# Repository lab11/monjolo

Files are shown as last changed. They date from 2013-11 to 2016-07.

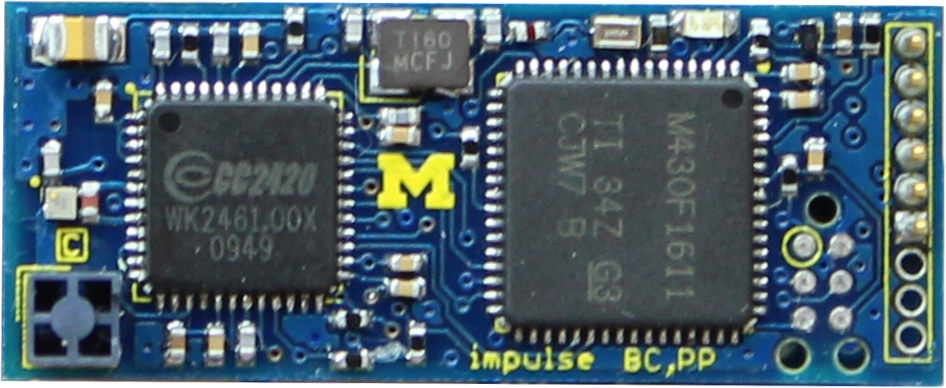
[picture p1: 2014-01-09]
hardware/impulse/rev_c/impulse.jpg

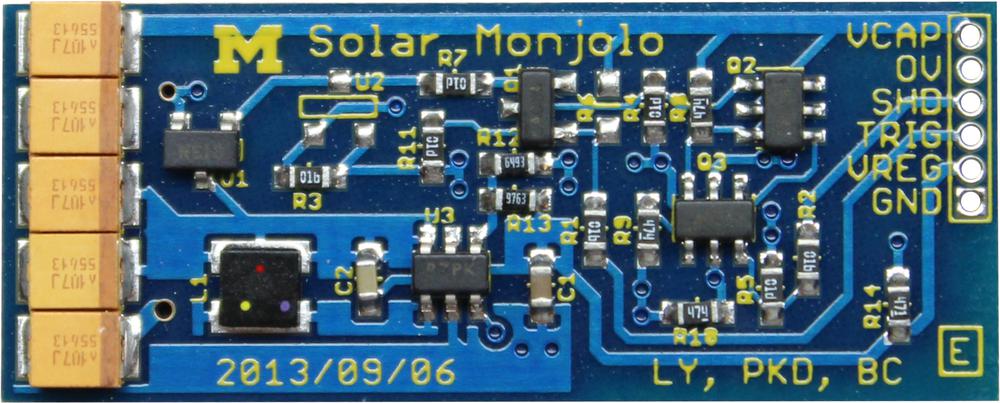
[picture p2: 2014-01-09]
hardware/gecko_power_supply/rev_e/monjolo.jpg

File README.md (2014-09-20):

Monjolo
=======

Monjolo sensors are designed to meter energy consumers, such as plug loads,
lighting, water heaters, etc. Monjolo exploits an interesting fact to accomplish
this: energy consuming loads (e.g. overhead lighting) often produce side
channels of energy that can be harvested (e.g. light with a solar panel).
Monjolo nodes use an energy-harvesting power supply to scavenge energy from
these side channels to power themselves. The sensors then infer information
about the original load based on the rate it is able to harvest. Monjolo nodes
follow a simple principle: the faster the rate of harvesting the greater the
amount of energy consumed by the monitored load.

The operation of a Monjolo node proceeds as follows: the harvester charges
a capacitor to some threshold. Once the threshold is met, the processing
core of the node activates and transmits a packet. The capacitor is then
drained to a lower threshold where the processing core is disabled and
the recharging process recommences. A central receiver collects all of these
packets and calculates the activation rate of the Monjolo node. This rate
is then used to meter the energy consumer.

This differs from traditional sensing because there is no explicit sensor
on the device. The sensing apparatus is entirely composed of the
energy-harvester and the packet receiver. All information is contained in
the rate of activations of the Monjolo node.

We have developed Three instantiations of this metering design. First is
Coilcube, a power meter for AC loads. Second is a light sensor for metering
lighting. And third is a thermoelectric design for metering temperature
differential.

Coilcube
--------

cc_case (https://raw.github.com/lab11/monjolo/master/media/coilcube_case.jpg)
cc_open (https://raw.github.com/lab11/monjolo/master/media/coilcube_open.jpg)

Coilcube is an AC power meter that comes in two forms: plug-load and split-core.

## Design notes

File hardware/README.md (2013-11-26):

Hardware (PCBs)
===============

This folder contains hardware for the various Monjolo nodes.

| Board | Folder | Description |
|---|---|---|
| Coilcube Power Supply | cc_power_supply | An AC current transformer based energy-harvesting power supply. |
| Coilcube | coilcube | Plug load AC meter. Contains processing core. |
| Gecko Power Supply | gecko_power_supply | Energy-harvesting power supply for solar cell. |
| Impulse | impulse | Processing core. Contains, uC, radio, antenna, FRAM, and timing capacitor. |
| sEHnsor | sEHnsor | Processing core like Impulse based on the CC2538. |

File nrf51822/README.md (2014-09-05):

Monjolo + nRF51822
==================

This folder contains code to run on the nRF51822 based Monjolo platform.

Setup
=====

1. Get the git repo that has the Makefiles in it.

        git clone https://github.com/hlnd/nrf51-pure-gcc-setup.git

1. Make sure you have the [arm-none-eabi-gcc](https://launchpad.net/gcc-arm-embedded)
toolchain. You just need the binaries for your platform.

1. Get the nRF51822 SDK and S110 soft device from the
[downloads page](https://www.nordicsemi.com/eng/Products/Bluetooth-Smart-Bluetooth-low-energy/nRF51822?resource=20339).
You want the "nRF51 SDK Zip File" and the "S110 nRF51822 SoftDevice (Production ready)".
You do need to buy a nRF51822 evm kit to get access to these, because companies
are the worst.

1. Make sure the SDK path is set correctly in the application Makefile.

1. Get the [Segger flashing tools](http://www.segger.com/jlink-software.html).
On Linux you want the "J-Link software & documentation pack for Linux".

Install an App
==============

1. Just once you need to load the soft device onto the nRF51822.

        make flash-softdevice SOFTDEVICE=/path/to/softdevice/s110_nrf51822_X.X.X_softdevice.hex

2. Now compile and load the application code.

        cd apps/monjolo
        make flash

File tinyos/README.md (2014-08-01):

TinyOS
======

Most of the code for Monjolo sensors is written in TinyOS. There are a
few steps you must complete to be able to compile the TinyOS apps.

Step 1: Get TinyOS
------------------

This repo will only compile against the latest version of tinyos. For now,
you need to compile the tools as well.

    git clone https://github.com/lab11/tinyos-main.git
    cd tinyos-main
    cd tools
    ./Bootstrap
    ./configure
    make
    sudo make install

You also need this repository, of course:

    git clone https://github.com/lab11/monjolo.git

Now you need to tell the TinyOS build tools where to find the Monjolo specific
TinyOS code. Add the following to `bash.rc`:

    export TINYOS_ROOT_DIR_ADDITIONAL=~/git/monjolo/tinyos:$TINYOS_ROOT_DIR_ADDITIONAL
    export TINYOS_ROOT_DIR=~/git/tinyos-main

This should setup enough TinyOS infrastructure to enable you to compile the
Monjolo applications.

Step 2: Setup the RaspberryPi
-----------------------------

The receiving code is designed for the Raspberry Pi platform. You need the
[Linux CC2520 Driver](https://github.com/ab500/linux-cc2520-driver) for the RPi.
Instead of installing that by hand I suggest using my preinstalled image you
can download from the [torrent](https://github.com/lab11/raspberrypi-cc2520/tree/master/torrents).

You also need the RPi TinyOS code.

    git clone https://github.com/lab11/raspberrypi-cc2520

Add this to `bash.rc`:

    export TINYOS_ROOT_DIR_ADDITIONAL=~/git/raspberrypi-cc2520/tinyos:$TINYOS_ROOT_DIR_ADDITIONAL

Step 3: Get the Compilers
-------------------------

In order to compile the TinyOS code you need the msp430 and the ARM compilers

Step 4: Compile the Applications
--------------------------------

### Monjolo Node

The application for the Monjolo sensors is simply called Monjolo. To compile
for coilcube:

    make coilcube blip

### Receiver

The receiver just uses the default BorderRouter app from raspberrypi-cc2520 with
the makefile in this repository.

    cd git/raspberrypi-cc2520/apps/BorderRouter
    make -f git/monjolo/tinyos/apps/BorderRouter/Makefile rpi blip

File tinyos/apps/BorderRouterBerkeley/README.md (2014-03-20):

Border Router
=============

To receive coilcube packets there must be a border router application
running. Because coilcubes just use IPv6 packets, there does not
need to be a coilcube specific border router app. Instead, use
the BorderRouter app from the raspberrypi-cc2520 repository, just with
this Makefile.

    cd raspberrypi-cc2520/tinyos/apps/BorderRouter
    make -f monjolo/tinyos/apps/BorderRouter/Makefile rpi

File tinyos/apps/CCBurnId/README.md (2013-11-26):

CCBurnId
========

Use this app to insert the unique 64 bit address for this node in the FRAM.

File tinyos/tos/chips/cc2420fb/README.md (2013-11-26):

CC2420FB
========

Driver for the cc2420, fast boot style.

This radio driver contains very little. You should not expect it to handle
really anything any of the other radio drivers do. Calling send on this driver
basically puts bits on the wire. All header, seq no, etc must be filled in by
you.

This driver is designed for energy-harvesting devices that wake up and send a
packet, and not much else.

To do:

1. write ieee154Bare that wraps the low level send in the nice abstraction
2. write ieee154 that wraps that with a packet layer that understands actual
   15.4 headers

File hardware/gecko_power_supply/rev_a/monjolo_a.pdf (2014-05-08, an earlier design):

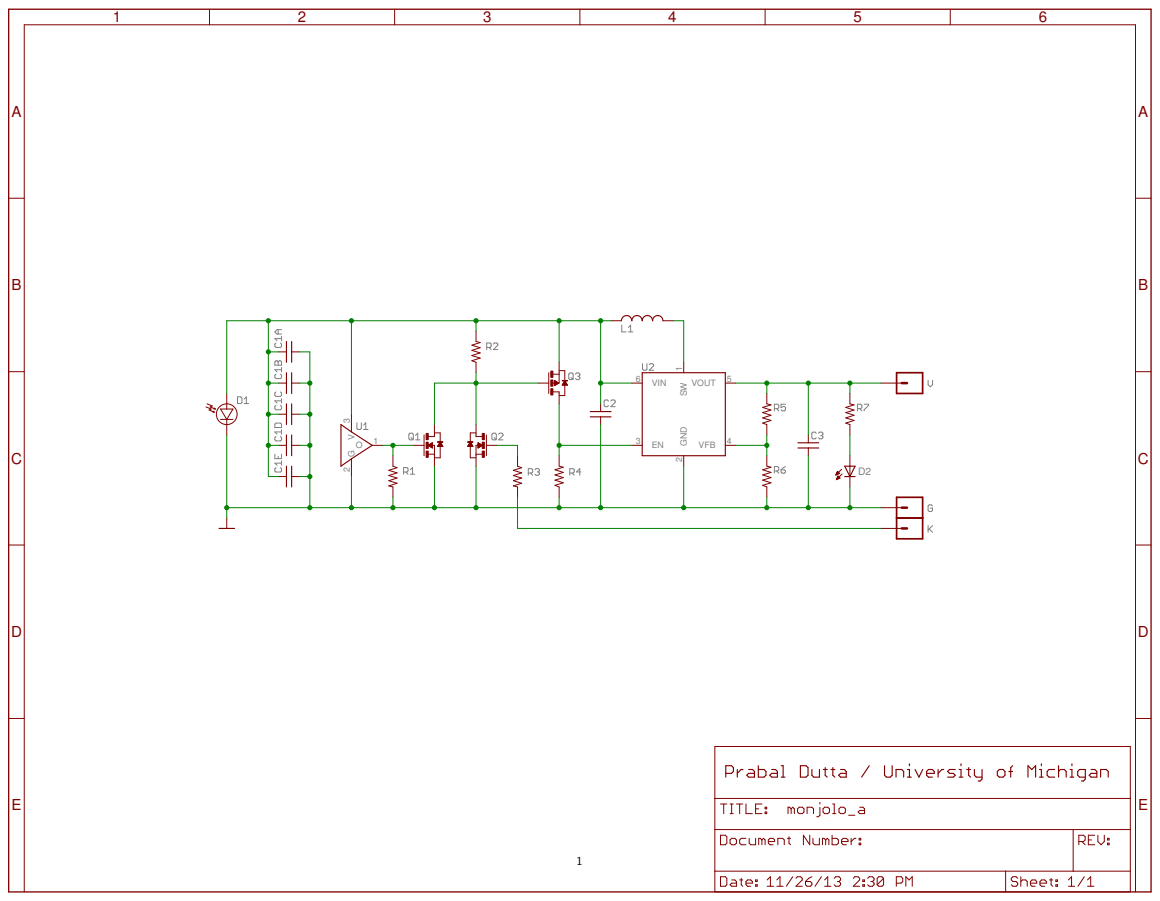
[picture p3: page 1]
SW ¹ VIN 6; VOUT; 5 VFB G; D2 ABCDE; ABCDE 1

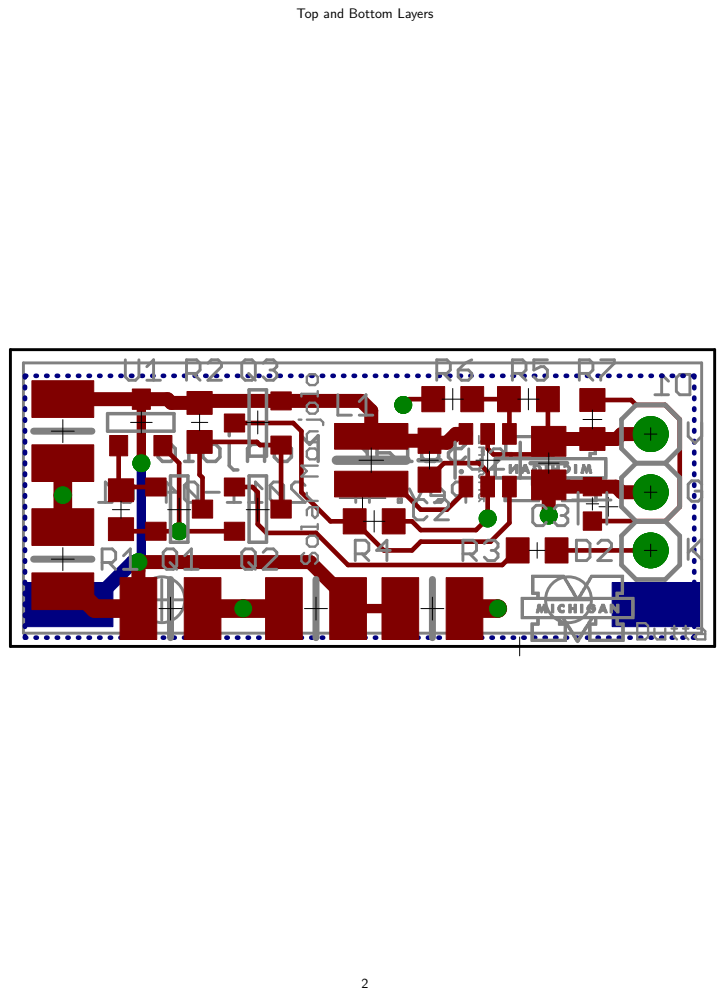
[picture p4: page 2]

Top and Bottom Layers

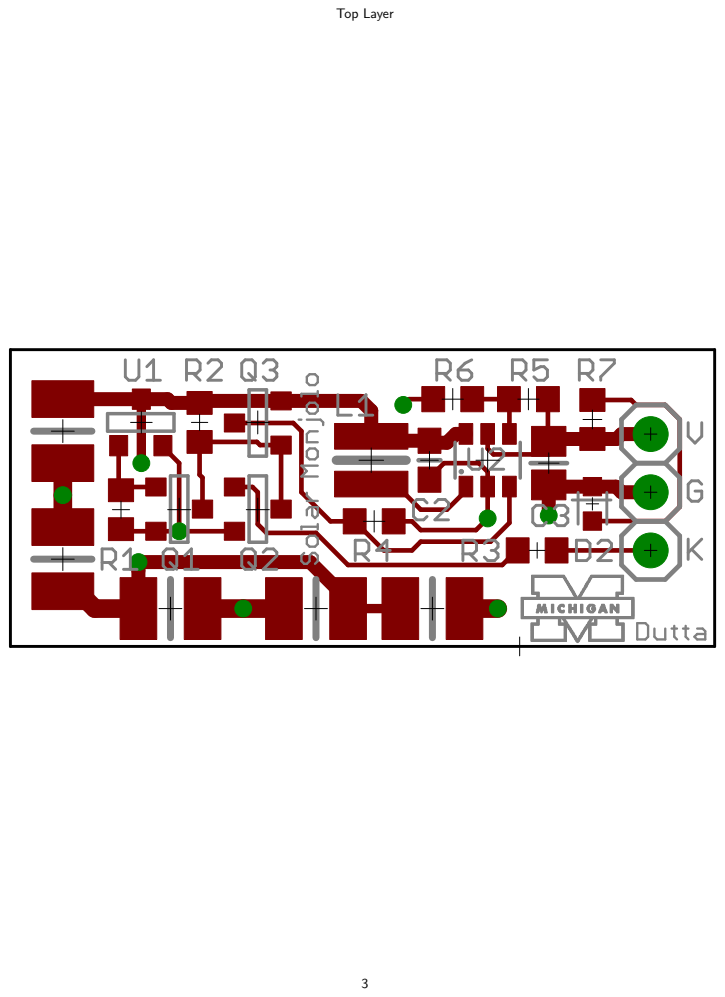
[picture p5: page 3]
Top Layer

Bottom Layer

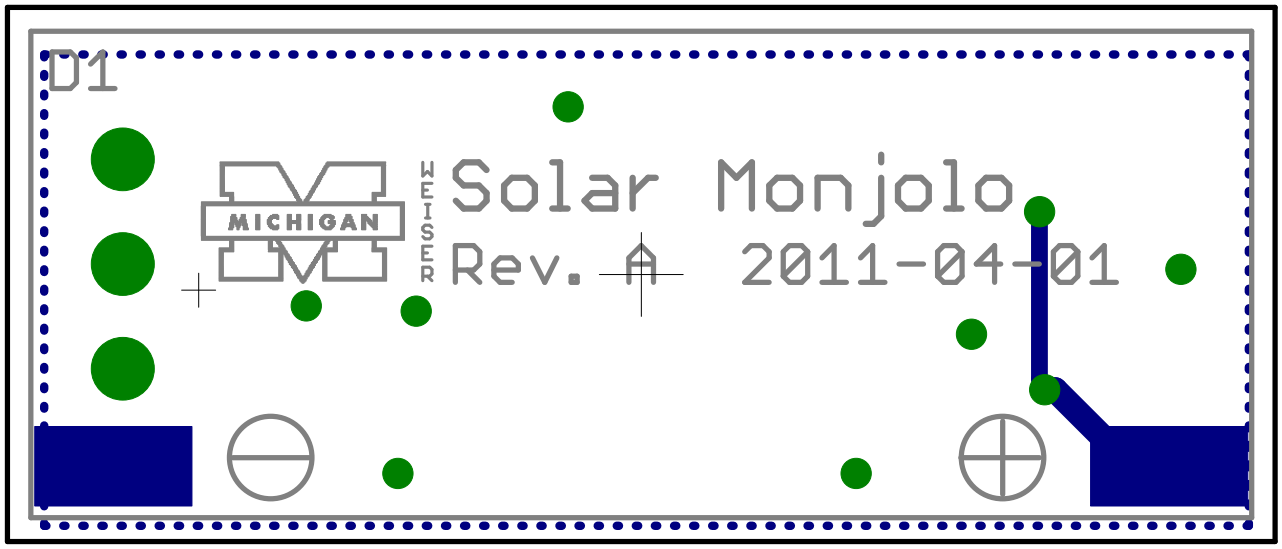
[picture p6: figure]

Top Copper Layer

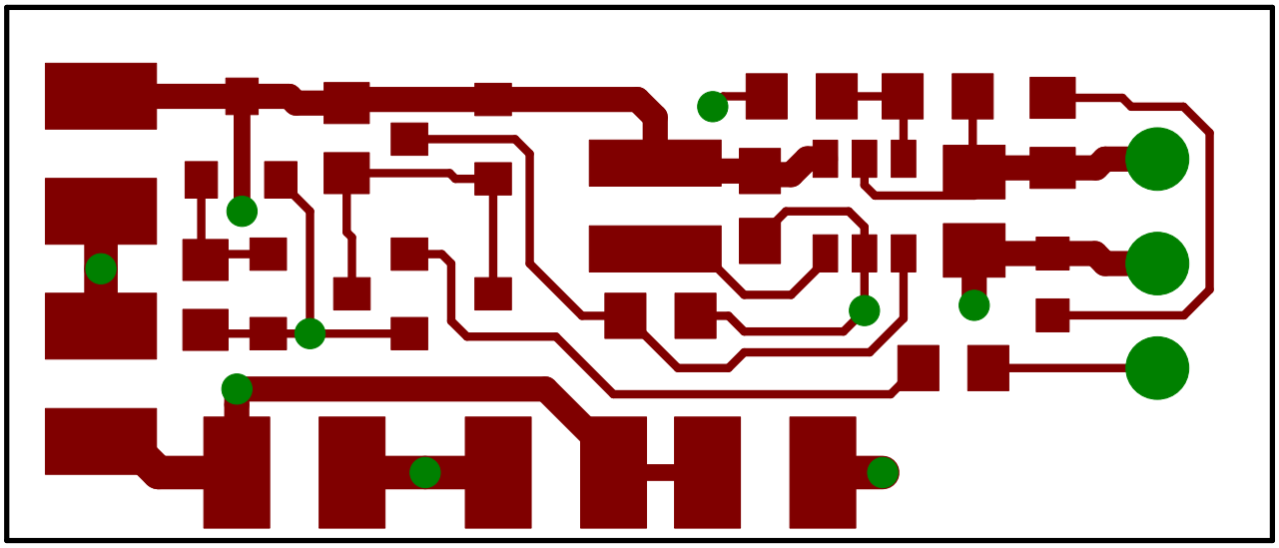
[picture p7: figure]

Bottom Copper Layer

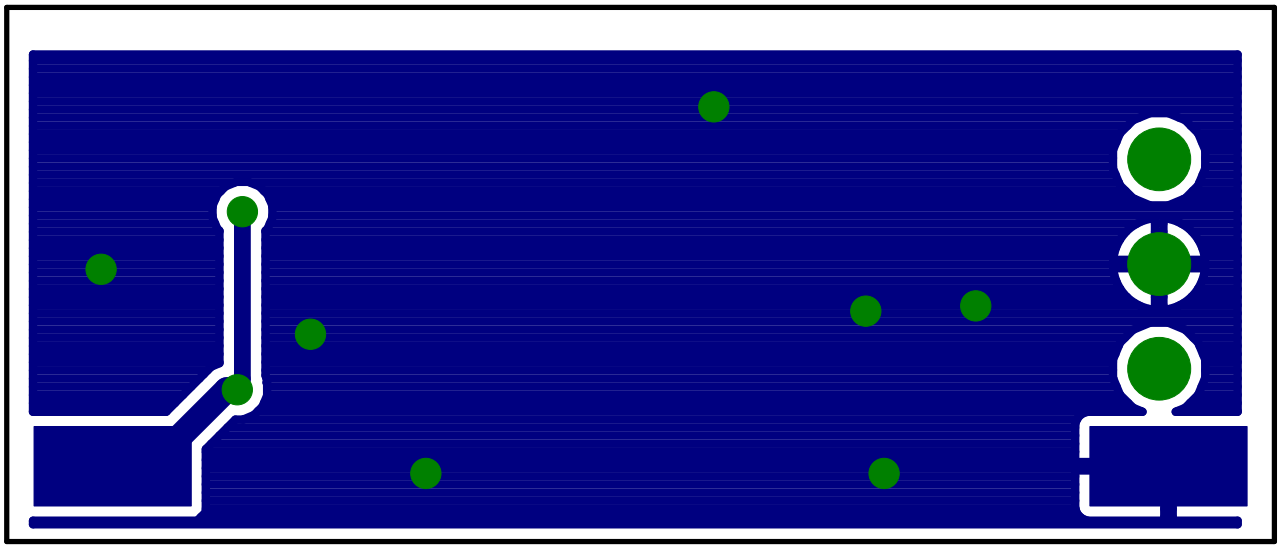
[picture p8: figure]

Top Paste Layer with Silkscreen

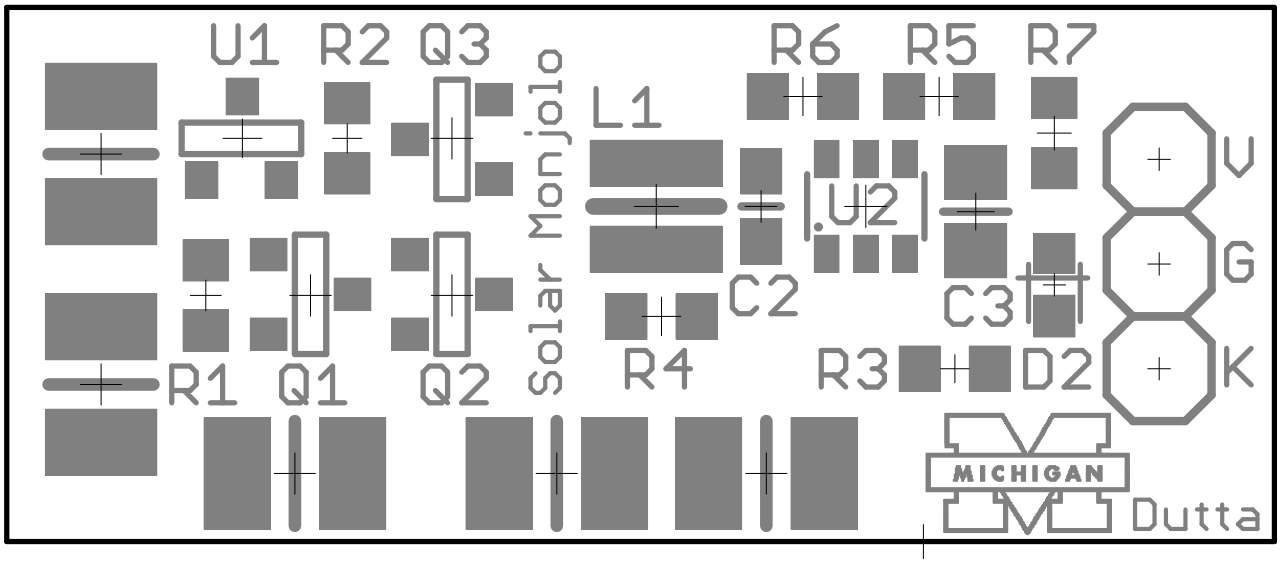
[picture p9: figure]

Bottom Paste Layer with Silkscreen

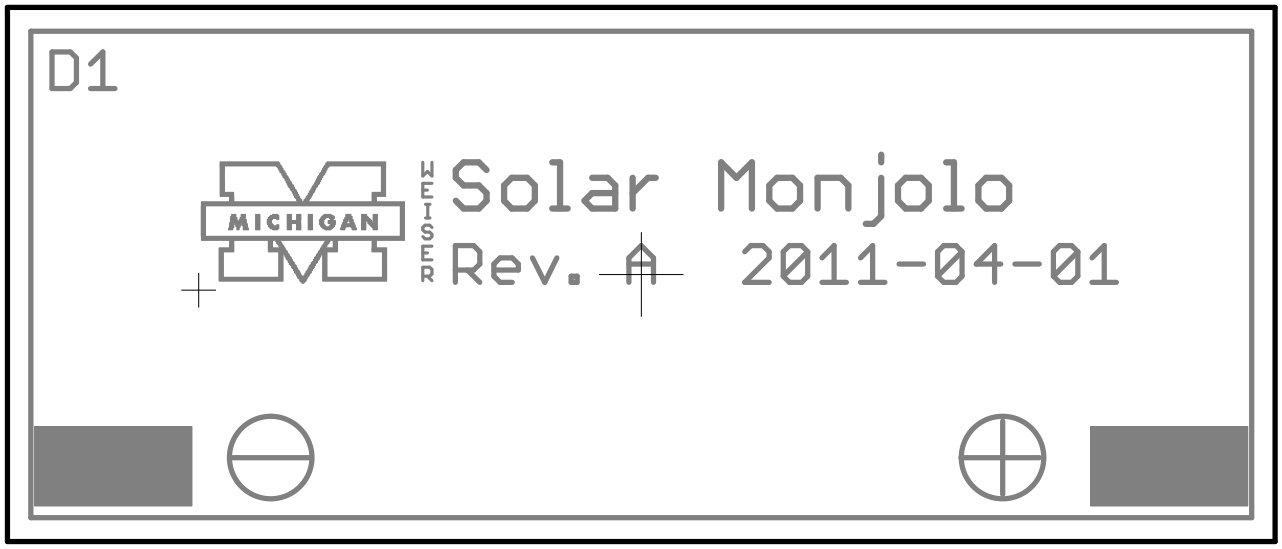
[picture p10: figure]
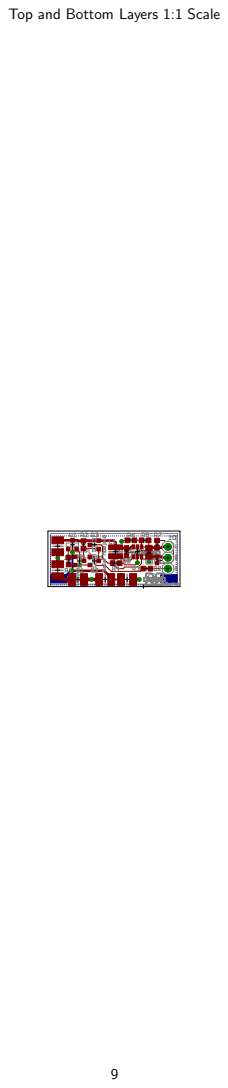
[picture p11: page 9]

Top and Bottom Layers 1:1 Scale

Top Layer 1:1 Scale

Bottom Copper Layer 1:1 Scale

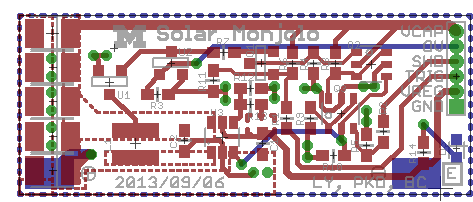
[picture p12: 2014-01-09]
hardware/gecko_power_supply/rev_e/monjolo_pcb.png

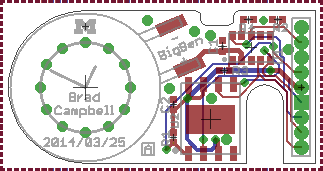
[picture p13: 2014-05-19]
hardware/bigben/rev_a/bigben_pcb.png

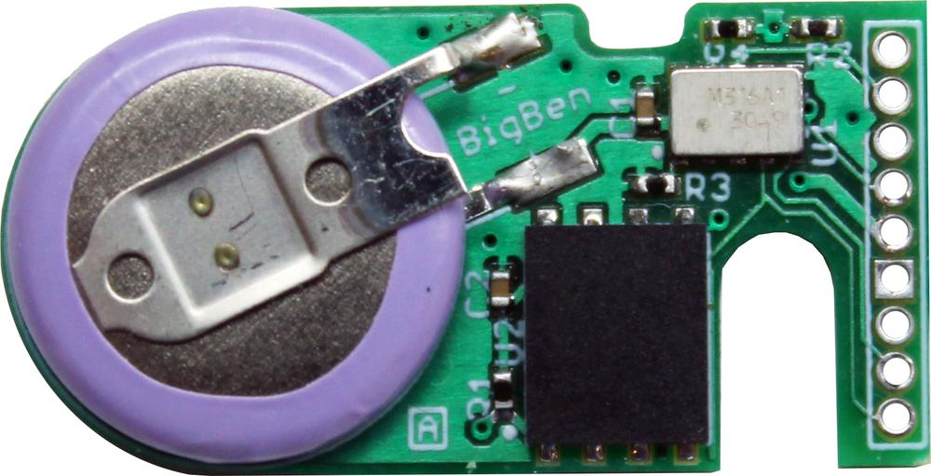
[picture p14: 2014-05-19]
hardware/bigben/rev_a/bigben.jpg

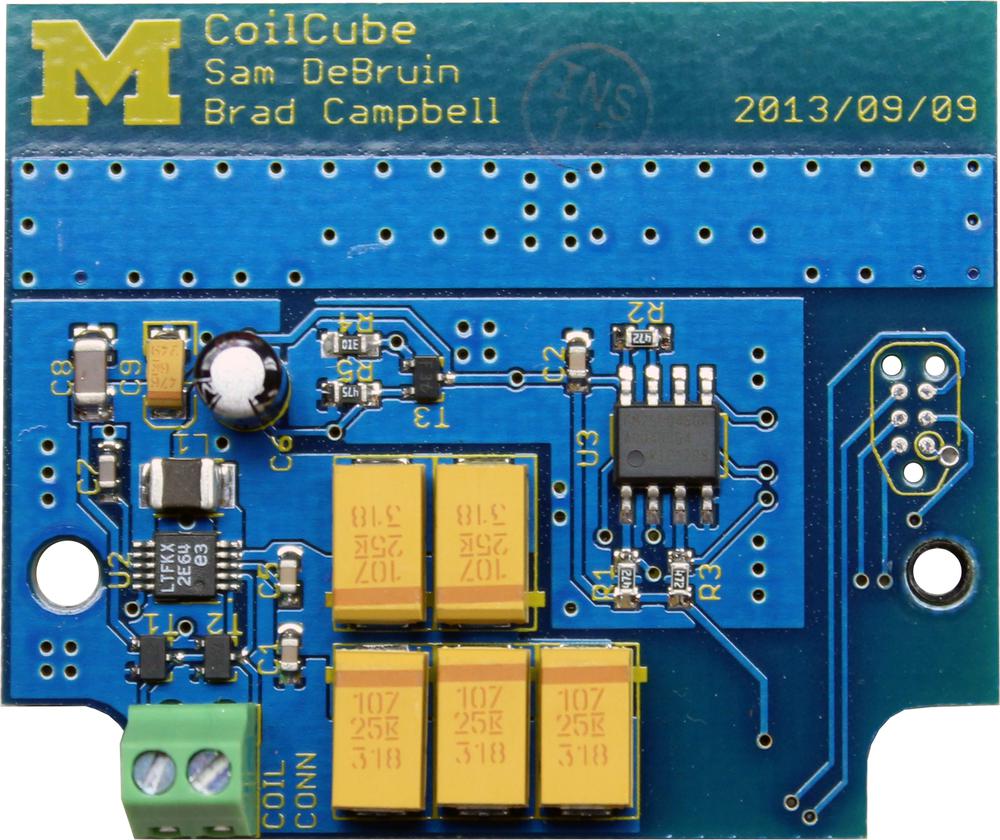
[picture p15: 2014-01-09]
hardware/coilcube/rev_c/coilcube.jpg

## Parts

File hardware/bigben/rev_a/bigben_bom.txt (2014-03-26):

# Bill of Materials
# Converted from bigben_bom.xls
# Generated by bom_to_text.py

Qty  Value         Device        Package           Parts   Description                                                  DIGIKEY         MOUSER            NEWARK
1    ML-1220/F1AN  ML-1220/F1AN  ML-1220/F1BN      BT1     BATTERY LITH 3V RECHARGE PC PINS                             P663-ND         658-ML-1220/F1BN  
1    10nF          CAPACITOR     0402_CAP          C1      0402 Capacitor                                               445-1260-1-ND                     90R7604
1    0.1uF         CAPACITOR     0402_CAP          C2      0402 Capacitor                                               445-1265-1-ND                     90R7585
4    4.7k          RESISTOR      0402_RES          R1, R2  Resistor                                                     RHM4.7KCECT-ND                    
2    10k           RESISTOR      0402_RES          R3, R4  Resistor                                                     RHM10KCECT-ND                     
1    RV-3049-C3    RV-3049-C3    MICRO-CRYSTAL-C3  U1      The RV-3049-C3 is an ultra miniature Real-Time-Clock Module                                    RV-3049-C3
1    FM25LBTDFN-8  FM25LBTDFN-8  TDFN-8            U2      IC FRAM 4KBIT 10MHZ 8SOIC                                                    877-FM25V20-DG

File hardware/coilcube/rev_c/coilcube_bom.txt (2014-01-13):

# Bill of Materials
# Converted from coilcube_bom.xlsx
# Generated by bom_to_text.py

Qty  Value                   Device                  Package         Parts                    Description                       DIGIKEY               DIGIREEL               Notes
4    0.1uF                   C-EUC0603               C0603           C1, C2, C3, C4           CAPACITOR, European symbol        445-1316-1-ND         445-1316-6-ND          
1    1uF                     C-EUC0603               C0603           C5                       CAPACITOR, European symbol        445-1321-1-ND         445-1321-6-ND          
1    2.2uF                   CAP_POLEA1MM5           CPOL_EEA_1MM5   C6                                                         P14506-ND                                    
1    4.7uF                   C-EUC0603               C0603           C7                       CAPACITOR, European symbol        445-5178-1-ND         445-5178-6-ND          
1    10uF                    C-EUC1206               C1206           C8                       CAPACITOR, European symbol        399-8152-1-ND         399-8152-6-ND          
1    47uF                    CAP_POL1206             EIA3216         C9                       Capacitor Polarized               399-3700-1-ND         399-3700-6-ND          
5    100uF 25V               2917_CAP_POL            2917_CAP_POL    C10, C11, C12, C13, C14                                    399-5175-1-ND         399-5175-6-ND          Replacement: 399-8410-1-ND
1    SCREW-TERMINAL_2_0.100  SCREW-TERMINAL_2_0.100  CONN_BLOCK_2    J1                       2x 0.100 in screw terminal block  277-1273-ND                                  
1    10uH                    INDUCTOR1210            1210            L1                       Inductors                         587-1625-1-ND         587-1625-6-ND          
3    4.7k                    R-US_R0603              R0603           R1, R2, R3               RESISTOR, American symbol         P4.7KGCT-ND           P4.7KGDKR-ND           
1    1M                      R-US_R0603              R0603           R4                       RESISTOR, American symbol         RHM1.00MCFCT-ND       RHM1.00MCFDKR-ND       
1    4.7M                    R-US_R0603              R0603           R5                       RESISTOR, American symbol         RHM4.7MCGCT-ND        RHM4.7MCGDKR-ND        
2    NCHAN_MOSFET            NCHAN_MOSFET            NCHAN_MOSFET    T1, T2                                                     SI1302DL-T1-GE3CT-ND  SI1302DL-T1-GE3DKR-ND  
1    NCHAN_MOSFET            NCHAN_MOSFET            NCHAN_MOSFET    T3                                                         568-3244-1-ND         568-3244-6-ND          
1    EPIC-CORE_A             EPIC-CORE_A             EPIC-LCC68      U1                                                                                                      Customer provided.
1    LTC3588_                LTC3588_                MSOP-10-GNDPAD  U2                       Energy Harvesting Power Supply    LTC3588EMSE-1#PBF-ND                         
1    FM25LB                  FM25LB                  SOIC_8          U3                                                         428-3210-ND

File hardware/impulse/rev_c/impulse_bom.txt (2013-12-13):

# Bill of Materials
# Converted from impulse_bom.xlsx
# Generated by bom_to_text.py

Qty  Value                   Device                  Package              Parts                                            Description                                               DIGIKEY               DIGIREEL               MOUSER           TAG-CONNECT
1    MOLEX-2.4GHZ-047948     MOLEX-2.4GHZ-047948     MOLEX-47948-ANTENNA  A1                                                                                                         WM4893CT-ND           WM4893DKR-ND                            
1    BD2425N50200A           BD2425N50200A           BD2425N50200A        B1                                                                                                         1173-1063-1-ND        1173-1063-6-ND                          
1    12pF                    CAPACITOR               0402_CAP             C1                                               0402 Capacitor                                            712-1257-1-ND         712-1257-6-ND                           
2    22pF                    CAPACITOR               0402_CAP             C2, C3                                           0402 Capacitor                                            445-1239-1-ND         445-1239-6-ND                           
4    68pF                    CAPACITOR               0402_CAP             C4, C5, C6, C7                                   0402 Capacitor                                            445-1245-1-ND         445-1245-6-ND                           
1    0.01uF                  CAPACITOR               0402_CAP             C8                                               0402 Capacitor                                            445-1260-1-ND         445-1260-6-ND                           
10   0.1uF                   CAPACITOR               0402_CAP             C9, C10, C11, C12, C13, C14, C15, C16, C17, C18  0402 Capacitor                                            445-1265-1-ND         445-1265-6-ND                           
1    2.2uF                   CAPACITOR               0402_CAP             C19                                              0402 Capacitor                                            445-3882-1-ND         445-3882-6-ND                           
1    10uF                    C-USC0805               C0805                C20                                              CAPACITOR, American symbol                                478-2561-1-ND         478-2561-6-ND                           
2    BLUE                    LED-0603                LED-0603             D1, D2                                           LED – BLUE                                                                                                            
DNP  IMPULSE_GECKO_HEADER    IMPULSE_GECKO_HEADER    HEADER1X9/0.05IN     J1                                               Header on the impulse EPIC-esque board                                                                                  
DNP  EPIC-PROG-POGO-NO-LEGS  EPIC-PROG-POGO-NO-LEGS  TC2030-IDC-NL        J2                                               Epic programmer based on the Tag Connect pogo pin cable.                                                                TC2030-IDC-NL
1    INDUCTOR0402            INDUCTOR0402            0402_CAP             L1                                                                                                         712-1419-1-ND         712-1419-6-ND                           
1    MOSFET-NCHANNELXFDN-3   MOSFET-NCHANNELXFDN-3   XFDFN-3              Q1                                               Generic NMOS footprint                                    DMN2400UFB4-7DICT-ND  DMN2400UFB4-7DIDKR-ND                   
1    2.2                     RESISTOR                0402_RES             R1                                               Resistor                                                  RHM2.2CECT-ND         RHM2.2CEDKR-ND                          
1    470                     RESISTOR                0402_RES             R2, R16                                          Resistor                                                                        RHM470BHDKR-ND                          
1    2.2k                    RESISTOR                0402_RES             R3                                               Resistor                                                  RHM2.2KCECT-ND        RHM2.2KCEDKR-ND                         
3    4.7k                    RESISTOR                0402_RES             R4, R5, R6                                       Resistor                                                  RHM4.7KCECT-ND        RHM4.7KCEDKR-ND                         
1    43k                     RESISTOR                0402_RES             R7                                               Resistor                                                  RHM43KCECT-ND         RHM43KCEDKR-ND                          
2    100k                    RESISTOR                0402_RES             R8, R9                                           Resistor                                                  RHM100KCECT-ND        RHM100KCEDKR-ND                         
4    1M                      RESISTOR                0402_RES             R10, R11, R12, R13                               Resistor                                                  RHM1.0MCECT-ND        RHM1.0MCEDKR-ND                         
1    4.7M                    RESISTOR                0402_RES             R14                                              Resistor                                                  541-4.7MJCT-ND        541-4.7MJDKR-ND                         
1    5.1M                    RESISTOR                0402_RES             R15                                              Resistor                                                  RHM5.1MBICT-ND        RHM5.1MBIDKR-ND                         
1    DS2411                  DS2411                  SOT-23               U1                                               Maxim DS2411                                              DS2411R+CT-ND         DS2411R+DKR-ND                          
1    FM25LBTDFN-8            FM25LBTDFN-8            TDFN-8               U2                                               IC FRAM 4KBIT 10MHZ 8SOIC                                 FM25L04B-DGRA-ND                             877-FM25L04B-DG  
1    MSP430F1611IRTD         MSP430F1611IRTD         S-PVQFN-N64          U3                                                                                                         296-18102-1-ND        296-18102-6-ND                          
1    CC2420RGZ               CC2420RGZ               S-PVQFN-N48          U4                                               2.4 GHz IEEE 802.15.4 / ZigBee-ready RF Transceiver       296-19585-1-ND        296-19585-6-ND                          
1    TXC-7V                  TXC-7V                  TXC-7V               X1                                                                                                         887-1799-1-ND         887-1799-6-ND                           
1    ABRACON-ABS05           ABRACON-ABS05           ABS05                X2                                               32.768kHz Crystal                                         535-11899-1-ND        535-11899-6-ND

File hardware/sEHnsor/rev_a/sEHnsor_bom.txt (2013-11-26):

# Bill of Materials
# Converted from sEHnsor_bom.xlsx
# Generated by bom_to_text.py

Qty  Value                           Device                          Package                          Parts                              Description                                                   DIGIKEY               MOUSER               NEWARK   RICHARDSON_RFPD
1    FRACTUS-2.4GHZ-FR05-S1-N-0-001  FRACTUS-2.4GHZ-FR05-S1-N-0-001  FRACTUS-ANTENNA-FR05-S1-N-0-001  A1                                 Fractus Reach Xtend                                                                                               FR05-S1-N-0001B
1    2450BM15A0002                   2450BM15A0002                   2450BM                           B1                                 BALUN JTI MATCHED ZIGBEE                                      712-1536-1-ND                                       
2    12pF                            CAPACITOR                       0402_CAP                         C1, C2                             0402 Capacitor                                                445-1236-1-ND                                       
1    220pF                           CAPACITOR                       0402_CAP                         C3                                 0402 Capacitor                                                445-1251-1-ND                                       
1    1nF                             CAPACITOR                       0402_CAP                         C4                                 0402 Capacitor                                                445-2651-1-ND                                       
8    0.1uF                           CAPACITOR                       0402_CAP                         C5, C6, C7, C8, C9, C10, C11, C12  0402 Capacitor                                                445-1265-1-ND                                       
3    1uF                             CAPACITOR                       0402_CAP                         C13, C14, C15                      0402 Capacitor                                                445-4998-1-ND                                       
1    2.2uF                           CAPACITOR                       0402_CAP                         C16                                0402 Capacitor                                                445-10882-1-ND                                      
1    GECKO_POWER_SUPPLY_CONN         GECKO_POWER_SUPPLY_CONN         HEADER1X6/0.05IN                 J1                                 Header on the gecko power supply board.                       TMS-106-51-G-S-ND                                   
1    MOSFET-NCHANNELXFDN-3           MOSFET-NCHANNELXFDN-3           XFDFN-3                          Q1                                 Generic NMOS footprint                                        DMN2400UFB4-7DICT-ND                                
2    2.2k                            RESISTOR                        0402_RES                         R1, R2                             Resistor                                                      RHM2.2KCECT-ND                                      
3    4.7k                            RESISTOR                        0402_RES                         R3, R4, R5                         Resistor                                                      RHM4.7KCECT-ND                                      
1    56k                             RESISTOR                        0402_RES                         R6                                 Resistor                                                      RHM56KBHCT-ND                                       
1    4.7M                            RESISTOR                        0402_RES                         R7                                 Resistor                                                      541-4.7MJCT-ND                                      
1    DS2411                          DS2411                          SOT-23                           U1                                 Maxim DS2411                                                  DS2411R+CT-ND                                       
1    FM25LBTDFN-8                    FM25LBTDFN-8                    TDFN-8                           U2                                 IC FRAM 4KBIT 10MHZ 8SOIC                                     FM25L04B-DGRA-ND      877-FM25L04B-DG               
1    CC2538                          CC2538                          S-PVQFN-N56                      U3                                 A Powerful System-On-Chip for 2.4-GHz IEEE 802.15.4, 6LoWPAN  296-35797-1-ND        595-CC2538SF53RTQT   87W7713  
1    EPSON-FA-128                    EPSON-FA-128                    FA-128                           X1                                 MHz RANGE CRYSTAL UNIT                                        SER3800CT-ND          732-FA128-32F20X-K3

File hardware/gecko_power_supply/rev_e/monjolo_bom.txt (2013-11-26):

# Bill of Materials
# Converted from monjolo_bom.xls
# Generated by bom_to_text.py

Qty  Value         Layout      Parts               Digikey Part #         DIGIREEL                Coilcraft       Discription                       Notes
1    10uF          C0603       C1                  445-7486-1-ND          445-7486-6-ND                           CAP CER 10UF 10V 10% X5R 0603     
1    4.7uF         C0603       C2                  490-6407-1-ND          490-6407-6-ND                           CAP CER 4.7UF 6.3V 10% X5R 0603   
4    100uF         C1206       C3, C4, C5, C6, C7  478-3130-1-ND          478-3130-6-ND                           CAP TANT 100UF 6.3V 20% 1210      
1    AM-1417       Solar cell  D1                  869-1000-ND                                                    SOLAR CELL AM 35MM X 13.9MM       
1    LED           LED0603     D2                  160-1837-1-ND          160-1837-6-ND                           LED BLUE CLEAR 0603 SMD           
1    4.7uH         L-US        L1                                                                 EPL3012-472MLB  4.7 UH INDUCTOR                   
1    PMOS          SOT23-3     Q1                  SI2305ADS-T1-GE3CT-ND  SI2305ADS-T1-GE3DKR-ND                  MOSFET P-CH 8V 5.4A SOT23-3       
2    MOSFET NP-CH  6-TSOP      Q2, Q3              SI3585DV-T1-E3CT-ND    SI3585DV-T1-E3DKR-ND                    MOSFET N/P-CH 20V 2A/1.5A 6-TSOP  
3    1K            R0603       R1, R2, R3          RHM1.00KCFCT-ND        RHM1.00KCFDKR-ND                        RES 1.00K OHM 1/10W 1% 0603 SMD   
4    100K          R0603       R4, R5, R7, R11     RHM100KCFCT-ND         RHM100KCFDKR-ND                         RES 100K OHM 1/10W 1% 0603 SMD    
DNP  100K          R0603       R6                  RHM100KCFCT-ND         RHM100KCFDKR-ND                         RES 100K OHM 1/10W 1% 0603 SMD    To use External Trigger solder R6 instead of R11
3    470K          R0603       R8, R9, R10         RHM470KCFCT-ND         RHM470KCFDKR-ND                         RES 470K OHM 1/10W 1% 0603 SMD    
1    649K          R0603       R12                 541-649KHCT-ND         541-649KHDKR-ND                         RES 649K OHM 1/10W 1% 0603 SMD    
1    976K          R0603       R13                 541-976KHCT-ND         541-976KHDKR-ND                         RES 976K OHM 1/10W 1% 0603 SMD    
1    470           R0603       R14                 RHM470CFCT-ND          RHM470CFDKR-ND                          RES 470 OHM 1/10W 1% 0603 SMD     
1    MN1382S 2.0V  SOT23-3     U1                  TC54VC2102ECB713CT-ND  TC54VC2102ECB713DKR-ND                  IC VOLT DETECT 2.0V CMOS SMD      
1    TC54VC 2.9V   SOT23-3     U2                  TC54VC2902ECB71CT-ND   TC54VC2902ECB71DKR-ND                   IC VOLT DETECTOR 2.9V SOT23A      Not needed if not using external Trigger (R11 soldered)
1    MCP1640T      SOT23-6     U3                  MCP1640T-I/CHYCT-ND    MCP1640T-I/CHYDKR-ND                    IC BOOST SYNC ADJ 0.1A SOT23-6

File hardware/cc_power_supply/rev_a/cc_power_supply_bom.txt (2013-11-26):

# Bill of Materials
# Converted from cc_power_supply_bom.xlsx
# Generated by bom_to_text.py

Qty  Value                    Device                   Package           Parts                    Description                              DIGIKEY               DIGIREEL               MOUSER
1    0.1uF                    C-EUC0603                C0603             C1                       CAPACITOR, European symbol               445-1316-1-ND         445-1316-6-ND          
1    1uF                      C-EUC0603                C0603             C5                       CAPACITOR, European symbol               445-1321-1-ND         445-1321-6-ND          
1    4.7uF                    C-EUC0603                C0603             C7                       CAPACITOR, European symbol               445-5178-1-ND         445-5178-6-ND          
1    10uF                     C-EUC1206                C1206             C8                       CAPACITOR, European symbol               399-8152-1-ND         399-8152-6-ND          
1    47uF                     CAP_POL1206              EIA3216           C9                       Capacitor Polarized                      399-3700-1-ND         399-3700-6-ND          
5    100uF 25V                2917_CAP_POL             2917_CAP_POL      C10, C11, C12, C13, C14                                           399-5175-1-ND         399-5175-6-ND          
DNP  SCREW-TERMINAL_2_0.100   SCREW-TERMINAL_2_0.100   CONN_BLOCK_2      J1                       2x 0.100 in screw terminal block         277-1273-ND                                  
1    10uH                     INDUCTOR1210             1210              L1                       Inductors                                587-1625-1-ND         587-1625-6-ND          
2    NCHAN_MOSFET             NCHAN_MOSFET             NCHAN_MOSFET      T1, T2                                                            SI1302DL-T1-GE3CT-ND  SI1302DL-T1-GE3DKR-ND  781-SI1302DL-E3
1    LTC3588_                 LTC3588_                 MSOP-10-GNDPAD    U2                       Energy Harvesting Power Supply           LTC3588EMSE-1#PBF-ND                         
DNP  GECKO_POWER_SUPPLY_CONN  GECKO_POWER_SUPPLY_CONN  HEADER1X6/0.05IN  J1                       Header on the gecko power supply board.  TMS-106-51-G-S-ND

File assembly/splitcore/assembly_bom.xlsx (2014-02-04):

Quantity | DIGIKEY | Manufacturer Part Number | Description | Notes
0 | 398-1079-ND | TT 100-SD | TRANSFORM CURR 100A SPLIT CORE
1 | 398-1078-ND | TT 50-SD | TRANSFORM CURRENT 50A SPLIT CORE

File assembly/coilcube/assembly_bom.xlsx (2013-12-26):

Quantity | DIGIKEY | Manufacturer Part Number | Description | Notes
0 | 582-1002-ND | CR2550-G | CURRENT INDICATOR REMOTE GRN 11" | Current transfomer. Need one of this or 582-1018-ND
1 | 582-1018-ND | CR8420-1000-G | TRANSFORMER GROUND FAULT WIRE LD
1 | 377-1709-ND | PPB-11860-BK | BOX ABS 3.09X2.09X1.65" BLK | Case. Comes in white or black.
0 | 377-1710-ND | PPB-11860-WT | BOX ABS 3.09X2.09X1.65" WHT
1 | Q228-ND | 739W-X2/03 | OUTLET PWR NEMA 5-15R SNAPIN/IDC | Female 5-15 socket.
1 | 6717 BK005-ND | 6717 BK005 | HOOK-UP STRND 14AWG BLACK 100' | 14 guage black
1 | 6717 GR005-ND | 6717 GR005 | HOOK-UP STRND 14AWG GREEN 100' | 14 guage green
1 | 6717 WH005-ND | 6717 WH005 | HOOK-UP STRND 14AWG WHITE 100' | 14 guage white
1 | ANT-2.4-CW-RH-SMA-ND | ANT-2.4-CW-RH-SMA | ANTENNA 2.45GHZ 1/4 WAVE SMA | SMA 2.4GHz Antenna
1 | 931-1187-ND | CAB.719 | HIROSE U.FL TO SMA(F) 100MM | Mirco ufl to sma for epic
1 | 3M6439-ND | DP-4XL | EPOXY ADHESIVE DUO-PACK 37ML | Epoxy
2 |  |  |  | #4 3/16" Panhead Self-Tapping Screws

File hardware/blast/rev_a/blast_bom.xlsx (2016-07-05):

Note | Qty | Value | Device | Package | Parts | Description | DIGIKEY | MOUSER | NEWARK | RICHARDSON_RFPD
 | 1 | FRACTUS-2.4GHZ-FR05-S1-N-0-001 | FRACTUS-2.4GHZ-FR05-S1-N-0-001 | FRACTUS-ANTENNA-FR05-S1-N-0-001 | A1 | Fractus Reach Xtend |  |  |  | FR05-S1-N-0001B
 | 1 | BAL-NRF01D3 | BAL-NRF01D3 | BAL-NRF01D3 | B1 | 50 ohm nominal input / conjugate match balun to nRF51422-QFAA, | 497-13637-1-ND | 511-BAL-NRF01D3
 | 1 | 0.8pF | CAPACITOR | 0402_CAP | C1 | 0402 Capacitor | 490-6269-1-ND
 | 2 | 12pF | CAPACITOR | 0402_CAP | C2, C3 | 0402 Capacitor | 490-6197-1-ND
 | 2 | 1nF | CAPACITOR | 0402_CAP | C4, C5 | 0402 Capacitor | 490-1303-1-ND
 | 1 | 2.2nF | CAPACITOR | 0402_CAP | C6 | 0402 Capacitor | 490-5419-1-ND
DNP | 1 | 10nF | CAPACITOR | 0402_CAP | C7 | 0402 Capacitor | 445-1260-1-ND
 | 1 | 47nF | CAPACITOR | 0402_CAP | C8 | 0402 Capacitor | 445-1264-1-ND
 | 2 | 0.1uF | CAPACITOR | 0402_CAP | C9, C10 | 0402 Capacitor | 445-4952-1-ND
DNP | 1 | 0.1uF | CAPACITOR | 0402_CAP | C11 | 0402 Capacitor | 445-4952-1-ND
 | 1 | 1uF | CAPACITOR | 0402_CAP | C12 | 0402 Capacitor | 1276-1513-1-ND
 | 1 | 2.2uF | CAPACITOR | 0402_CAP | C13 | 0402 Capacitor | 445-3882-1-ND
 | 1 | 4.7uF | CAPACITOR | 0402_CAP | C14 | 0402 Capacitor | 445-5947-1-ND
 | 2 | BLUE | LED0603 | LED-0603 | D1, D2 | LEDs | 160-1837-1-ND
 | 1 | IMPULSE_GECKO_HEADER | IMPULSE_GECKO_HEADER | HEADER1X9/0.05IN | J1 | Header on the impulse EPIC-esque board.
 | 1 | 10uH | INDUCTOR0603 | 0603_CAP | L1 |  | 490-4025-1-ND
 | 1 | 15nH | INDUCTOR0402 | 0402_CAP | L2 |  | 587-1521-1-ND
 | 1 | MOSFET-NCHANNELXFDN-3 | MOSFET-NCHANNELXFDN-3 | XFDFN-3 | Q1 | Generic NMOS footprint | DMN2400UFB4-7DICT-ND
 | 2 | 470 | RESISTOR | 0402_RES | R1, R2 | Resistor | RHM470CECT-ND
 | 1 | 4.7k | RESISTOR | 0402_RES | R3 | Resistor | RHM4.7KCECT-ND
DNP | 2 | 4.7k | RESISTOR | 0402_RES | R4, R5 | Resistor | RHM4.7KCECT-ND
DNP | 2 | 10k | RESISTOR | 0402_RES | R6, R7 | Resistor | RHM10KCECT-ND
 | 1 | 12k | RESISTOR | 0402_RES | R8 | Resistor | RHM12.0KCDCT-ND
 | 1 | 1M | RESISTOR | 0402_RES | R9 | Resistor | RHM1.0MCECT-ND
 | 1 | 4.7M | RESISTOR | 0402_RES | R10 | Resistor | 541-4.7MJCT-ND
 | 1 | NRF51822QF | NRF51822QF | QFN-48-6MM | U1 | Multiprotocol Bluetooth® 4.0 low energy/2.4 GHz RF SoC | 1490-1042-1-ND | 949-NRF51822-QFAC-R7
 | 1 | FM25LBTDFN-8 | FM25LBTDFN-8 | TDFN-8@1 | U2 | IC FRAM 4KBIT 10MHZ 8SOIC | FM25L04B-DGRA-ND | 877-FM25L04B-DG
DNP | 1 | RV-3049-C3 | RV-3049-C3 | MICRO-CRYSTAL-C3 | U3 | The RV-3049-C3 is an ultra miniature Real-Time-Clock Module |  |  | RV-3049-C3
DNP | 1 | FM25V20-DG | FM25V20-DG | TDFN-8/6MM | U4 | Cypress FRAM | FM25V20-DGRA-ND | 877-FM25V20-DG
 | 1 | 16MHz | TXC-8Y | TXC-8Y | X1 | 2mmx1.6mm SMD Crystal | 887-2003-1-ND

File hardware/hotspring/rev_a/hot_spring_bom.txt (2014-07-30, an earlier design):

# Bill of Materials
# Converted from hot_spring_bom.xlsx
# Generated by bom_to_text.py

Qty  Value               Device              Package     Parts                   Description                   COILCRAFT       DIGIKEY              NEWARK
2    470pF               CAPACITOR           0402_CAP    C1, C2                  0402 Capacitor                                445-1255-1-ND        
2    1000pF              CAPACITOR           0402_CAP    C3, C4                  0402 Capacitor                                445-1256-1-ND        
1    0.1uF               CAPACITOR           0402_CAP    C5                      0402 Capacitor                                445-4952-1-ND        
1    1uF                 CAPACITOR           0402_CAP    C6                      0402 Capacitor                                445-13185-1-ND       
1    2.2 uF              CAPACITOR           0402_CAP    C7                      0402 Capacitor                                445-4999-1-ND        
1    47uF                CAP1210             1210        C8                      Capacitor                                     399-5515-1-ND        
5    100uF               1210_CAP_POLARIZED  CAP1210     C9, C10, C11, C12, C13  Capacitor                                     478-3130-1-ND        
2    MOSFET-NCHANNELSMD  MOSFET-NCHANNELSMD  SOT23-3     Q1, Q2                  NMOS                                          FDV301NCT-ND         
1    DUAL_MOSFET_NP      DUAL_MOSFET_NP      TSOP-6      Q3                      MOSFET N/P-CH 20V 2A 6-TSOP                   SI3585DV-T1-E3CT-ND  
1    250k                RESISTOR0402_RES    0402_RES    R1                      Resistor                                      RHM249KCDCT-ND       
1    470k                RESISTOR0402_RES    0402_RES    R2                      Resistor                                      RHM470KCDCT-ND       
1    500k                RESISTOR0402_RES    0402_RES    R3                      Resistor                                      RHM499KCDCT-ND       
2    LPR6235-752SMR      LPR6235-752SMR      LPR6235     T1, T2                  Transformer 100:1             LPR6235-752SMR                       
1    LTC3109EUF          LTC3109EUF          QFN-20-4MM  U1                      IC BOOST CONVERTER PMU 20QFN                  LTC3109EUF#PBF-ND    84R6674

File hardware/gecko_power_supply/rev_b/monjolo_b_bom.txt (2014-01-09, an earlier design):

# Bill of Materials
# Converted from monjolo_b_bom.xls
# Generated by bom_to_text.py

Partlist  exported      from        Dropbox/eagle/Gecko/SOLAR-MONJOLO_B/SOLAR-MONJOLO_B/SOLAR-MONJOLO_B.sch  at  6/7/2012  4:25                                                                    
                                                                                                                                                                                                   
Qty       Value         Layout      Parts                                                                                        Digikey Part #                  Discription                       Notes
1         LED           LED0603     D2                                                                                                                                                             Any color LED
1         LED RESISTOR  R0603       R5                                                                                                                                                             VREG = 3V (try to use <5mA) select R value appropriately
1         PMOS          SOT23-3     Q1                                                                                           SI2305ADS-T1-GE3CT-ND           MOSFET P-CH 8V 5.4A SOT23-3       
3         1K            R0603       R3                                                                       R8  R10             P1.00KHCT-ND                    RES 1.00K OHM 1/10W 1% 0603 SMD   
3         1M            R0603       R2                                                                       R4  R7              P470KHCT-ND                     RES 470K OHM 1/10W 1% 0603 SMD    1M Ohm should work but using the 470K that was tested
1         4.7uF         C0603       C2                                                                                           490-3297-1-ND                   CAP CER 4.7UF 6.3V 10% X5R 0603   
1         4.7uH         L-US        L1                                                                                           Order from coilcraft direct ->  EPL3012-472MLB                    
1         10uF          C0603       C1                                                                                           445-7486-1-ND                   CAP CER 10UF 10V 10% X5R 0603     
4         100K          R0603       R1                                                                       R6  R12       R15   P100KHCT-ND                     RES 100K OHM 1/10W 1% 0603 SMD    To use External Trigger solder R11 instead of R12
1         649K          R0603       R16                                                                                          P649KHCT-ND                     RES 649K OHM 1/10W 1% 0603 SMD    
1         976K          R0603       R14                                                                                          P976KHCT-ND                     RES 976K OHM 1/10W 1% 0603 SMD    
1         AM-1437       Solar cell  D1                                                                                                                                                             
2         MOSFET NP-CH  6-TSOP      Q2                                                                       Q5                  SI3585DV-T1-E3CT-ND             MOSFET N/P-CH 20V 2A/1.5A 6-TSOP  
1         MCP1640T      SOT23-6     U4                                                                                           MCP1640T-I/CHYCT-ND             IC BOOST SYNC ADJ 0.1A SOT23-6    
1         MN1382S 2.0V  SOT23-3     U1                                                                                           MN1382SCPCT-ND                  IC VOLT DETECT 2.0V CMOS SMD      If supply low: TC54VC2102ECB713CT-ND is a tested alternative
1         TC54VC 2.9V   SOT23-3     U3                                                                                           TC54VC2902ECB71CT-ND            IC VOLT DETECTOR 2.9V SOT23A      Not needed if not using external Trigger (R12 soldered)
3         100uF         C1206       C1A                                                                          C1C       C1D   478-3130-1-ND                   CAP TANT 100UF 6.3V 20% 1210      Much more expensive alternative at 1206 size for 100uF (478-3345-1-ND) Allowing C1B to be populated as well giving 400uF of capacitance.

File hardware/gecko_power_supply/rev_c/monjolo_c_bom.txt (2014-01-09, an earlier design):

# Bill of Materials
# Converted from monjolo_c_bom.xls
# Generated by bom_to_text.py

Order  Qty  Value         Layout      Parts           Digikey Part #          Coilcraft       Discription                       Notes                                                         
300    1    10uF          C0603       C1              445-7486-6-ND                           CAP CER 10UF 10V 10% X5R 0603                                                                   
300    1    4.7uF         C0603       C2              490-3297-6-ND                           CAP CER 4.7UF 6.3V 10% X5R 0603                                                                 
1100   4    100uF         C1206       C3, C4, C5, C6  478-3130-1-ND                           CAP TANT 100UF 6.3V 20% 1210      Much more expensive alternative at 1206 size for 100uF.       
200    1    AM-1437       Solar cell  D1              ???                                                                                                                                     869-1002-ND
300    1    LED           LED0603     D2              160-1184-6-ND                           LED YELLOW CLEAR 0603 SMD         Any color LED                                                 
300    1    4.7uH         L-US        L1                                      EPL3012-472MLB  4.7 UH INDUCTOR                                                                                 
300    1    PMOS          SOT23-3     Q1              SI2305ADS-T1-GE3DKR-ND                  MOSFET P-CH 8V 5.4A SOT23-3                                                                     
550    2    MOSFET NP-CH  6-TSOP      Q2, Q3          SI3585DV-T1-E3DKR-ND                    MOSFET N/P-CH 20V 2A/1.5A 6-TSOP                                                                
1000   3    1K            R0603       R1, R2, R3      P1.00KHDKR-ND                           RES 1.00K OHM 1/10W 1% 0603 SMD                                                                 
1250   4    100K          R0603       R4, R5, R7      P100KHDKR-ND                            RES 100K OHM 1/10W 1% 0603 SMD                                                                  
DNP    1    100K          R0603       R6              P100KHDKR-ND                            RES 100K OHM 1/10W 1% 0603 SMD                                                                  
1000   3    470K          R0603       R8, R9, R10     P470KHDKR-ND                            RES 470K OHM 1/10W 1% 0603 SMD    Using 470K that was tested, should work with 1M               
250    1    100K          R0603       R11             P100KHDKR-ND                            RES 100K OHM 1/10W 1% 0603 SMD    To use External Trigger solder R11 instead of R6              
300    1    649K          R0603       R12             P649KHDKR-ND                            RES 649K OHM 1/10W 1% 0603 SMD                                                                  
300    1    976K          R0603       R13             P976KHDKR-ND                            RES 976K OHM 1/10W 1% 0603 SMD                                                                  
DNP    1    1K            R0603       R14             P1.0KGDKR-ND                            RES 1.0K OHM 1/10W 5% 0603 SMD    VREG = 3V (try to use <5mA) select R value appropriately      
500    1    470           R0603       R14             P470GDKR-ND                             RES 470 OHM 1/10W 5% 0603 SMD                                                                   
300    1    MN1382S 2.0V  SOT23-3     U1              TC54VC2102ECB713DKR-ND                  IC VOLT DETECT 2.0V CMOS SMD      If supply low: TC54VC2102ECB713CT-ND is a tested alternative  MN1382SCPCT-ND
300    1    TC54VC 2.9V   SOT23-3     U2              TC54VC2902ECB71DKR-ND                   IC VOLT DETECTOR 2.9V SOT23A      Not needed if not using external Trigger (R6 soldered)        
300    1    MCP1640T      SOT23-6     U3              MCP1640T-I/CHYDKR-ND                    IC BOOST SYNC ADJ 0.1A SOT23-6

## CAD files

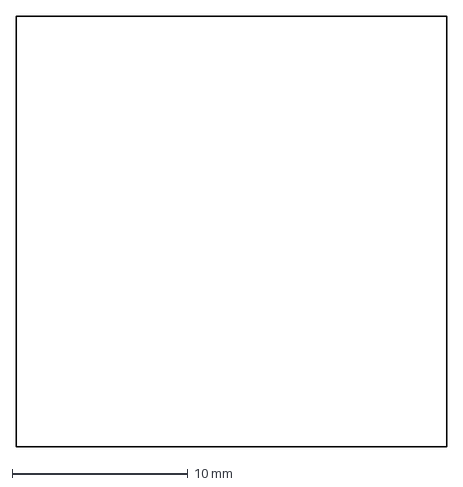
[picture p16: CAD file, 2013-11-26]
assembly/coilcube/coilcube_case_cutout.dxf
24.5 x 24.5 mm

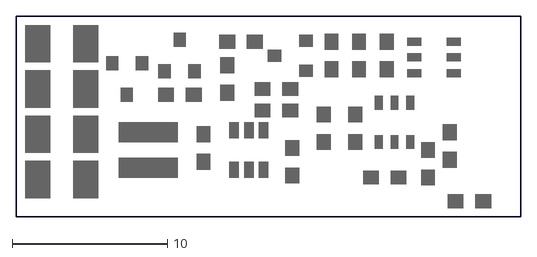
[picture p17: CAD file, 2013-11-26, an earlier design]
hardware/gecko_power_supply/rev_c/monjolo_c_mm.dxf
32.5 x 13.0

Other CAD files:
assembly/coilcube/coilcube_case_cutout.dwg

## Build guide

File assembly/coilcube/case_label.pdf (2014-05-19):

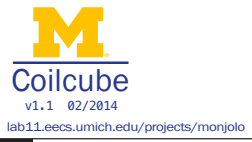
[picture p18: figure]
Coilcube; v1.1 02/2014 lab11.eecs.umich.edu/projects/monjolo

ID

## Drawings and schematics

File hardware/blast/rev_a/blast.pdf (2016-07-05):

## FRAM (4 Kbit)

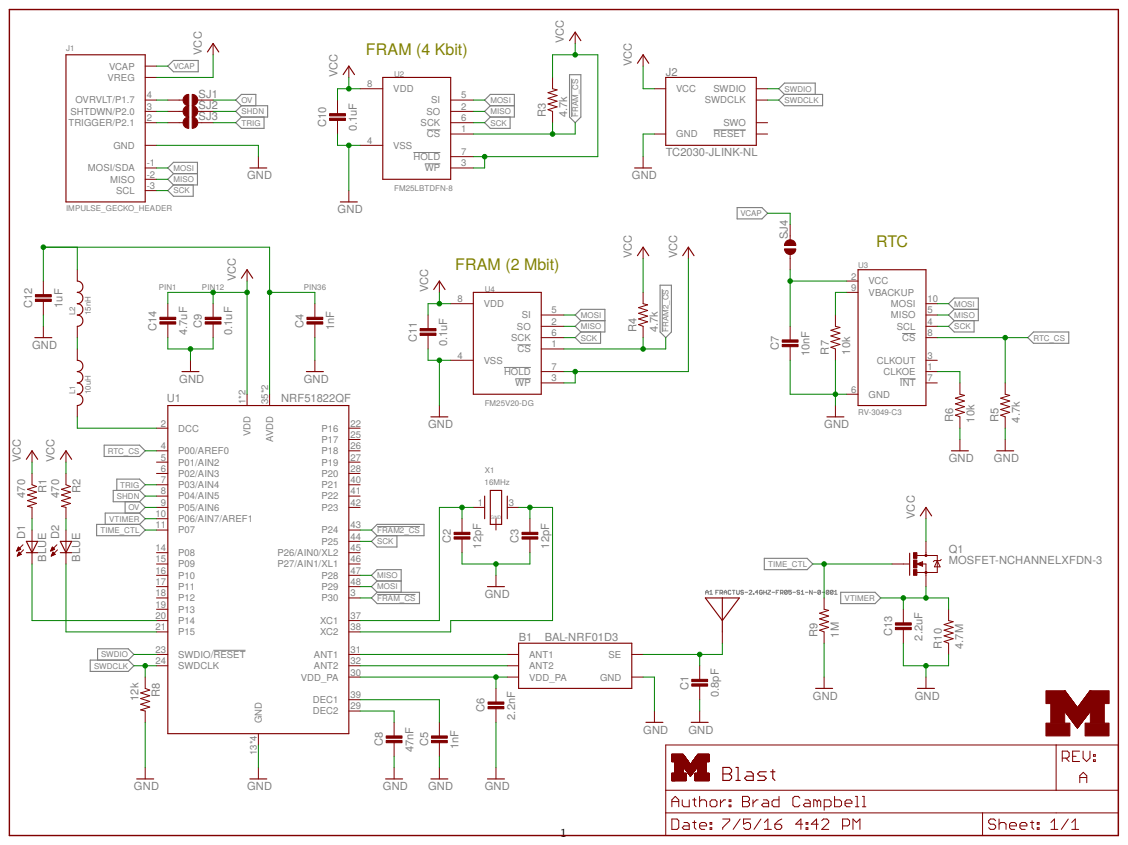
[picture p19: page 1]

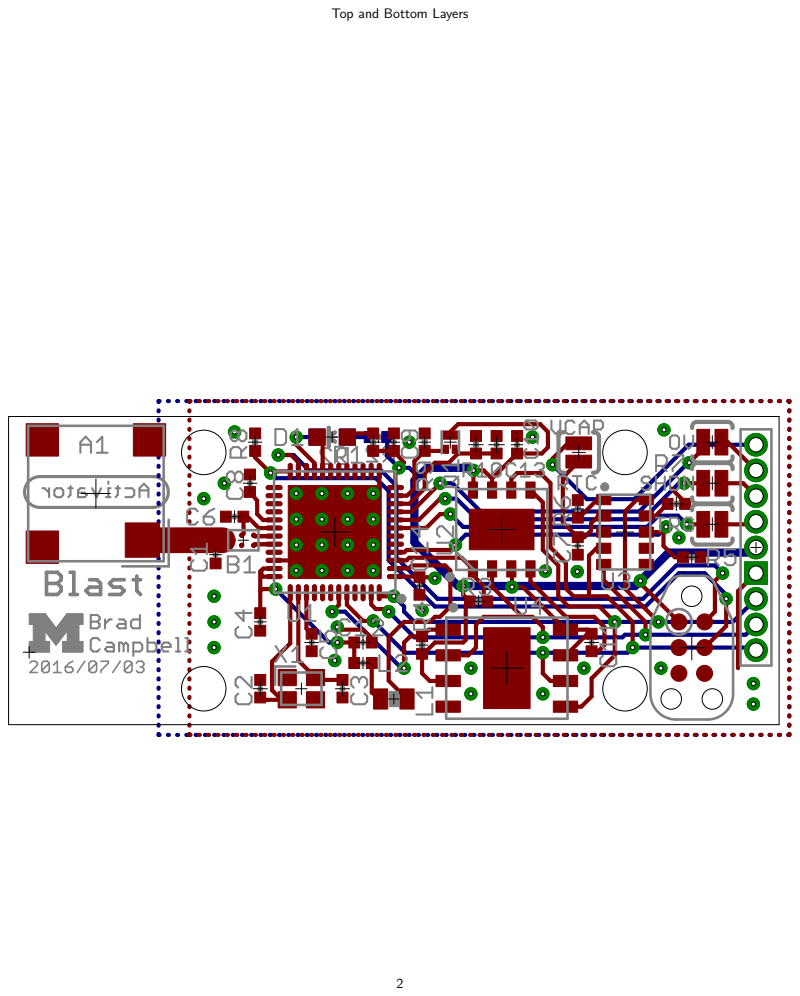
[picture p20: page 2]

Top and Bottom Layers

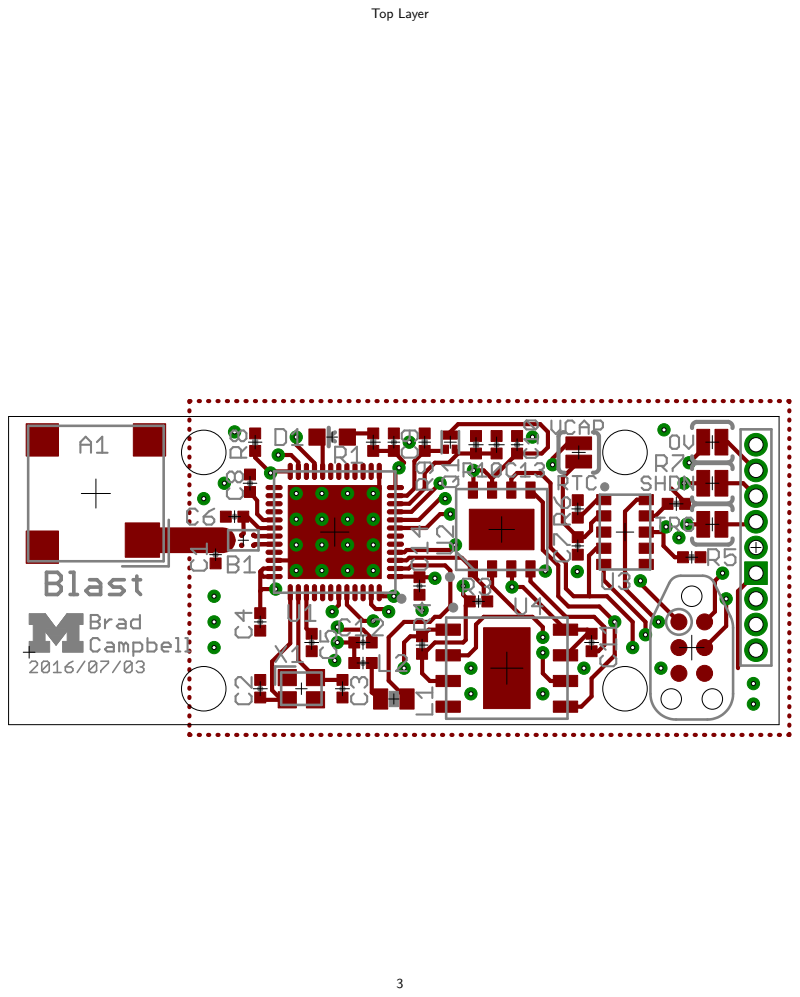
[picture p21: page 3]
Top Layer

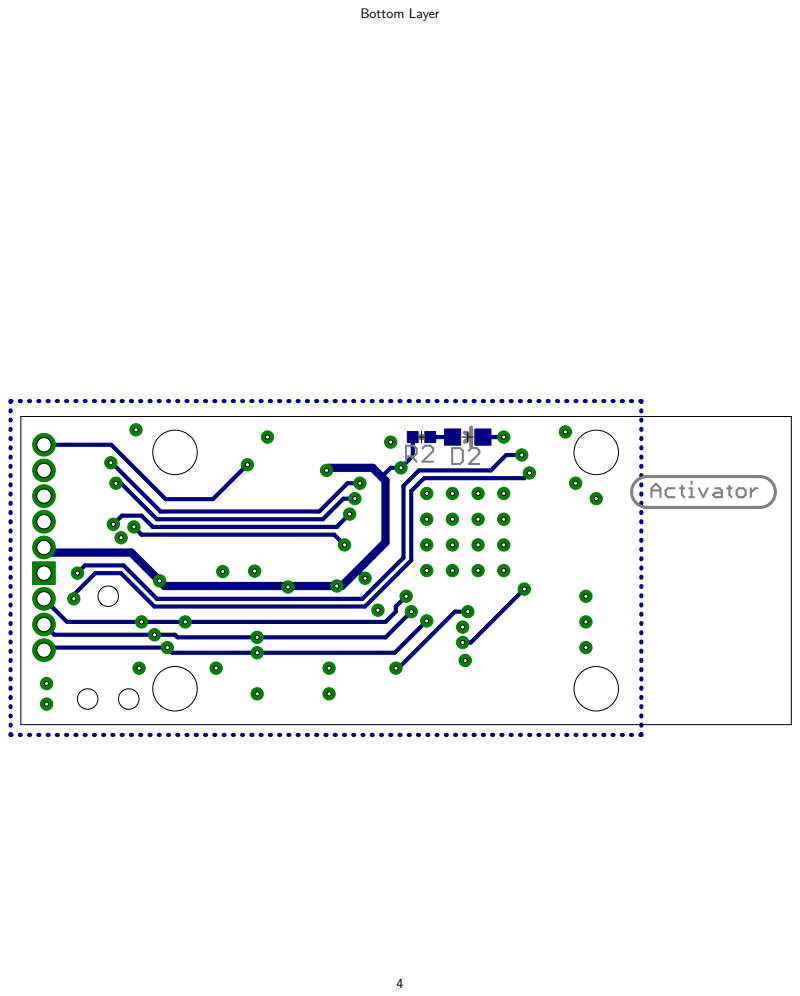
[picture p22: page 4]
Bottom Layer

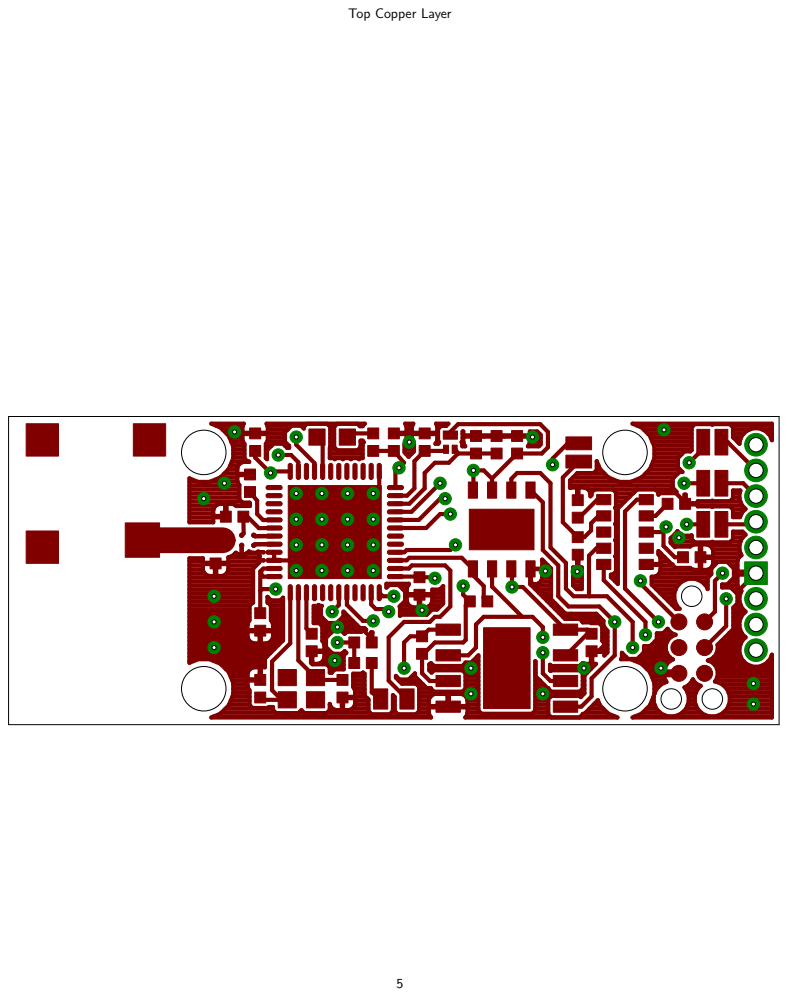
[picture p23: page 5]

Top Copper Layer

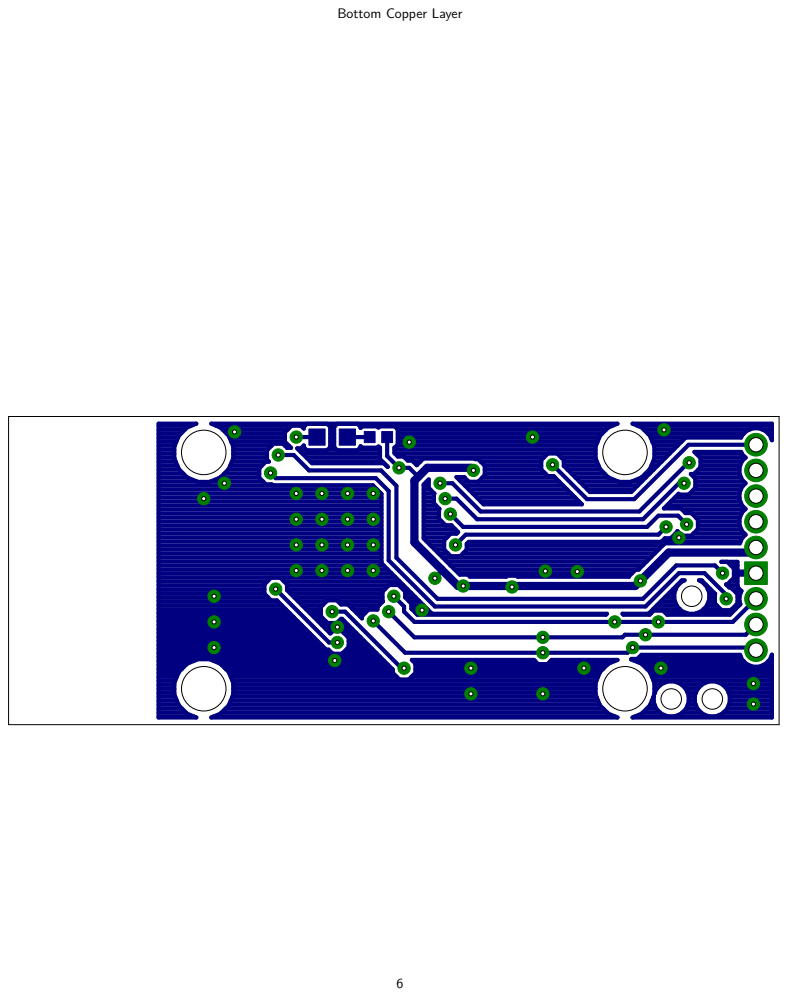
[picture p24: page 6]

Bottom Copper Layer

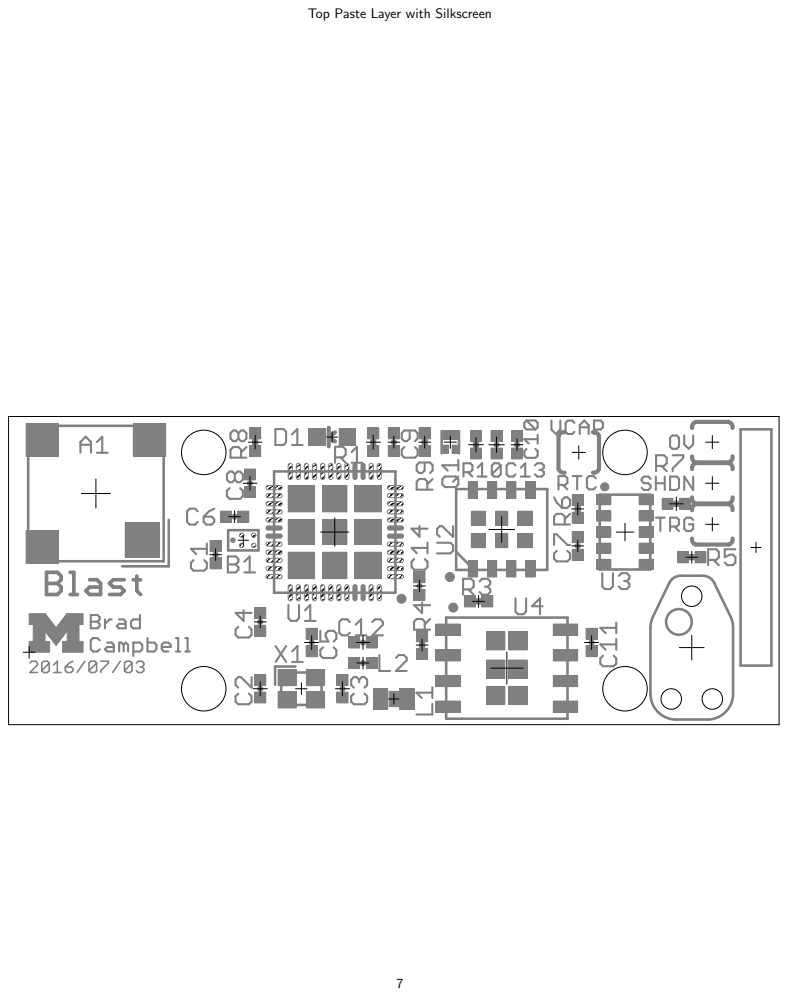
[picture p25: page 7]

Top Paste Layer with Silkscreen

Bottom Paste Layer with Silkscreen

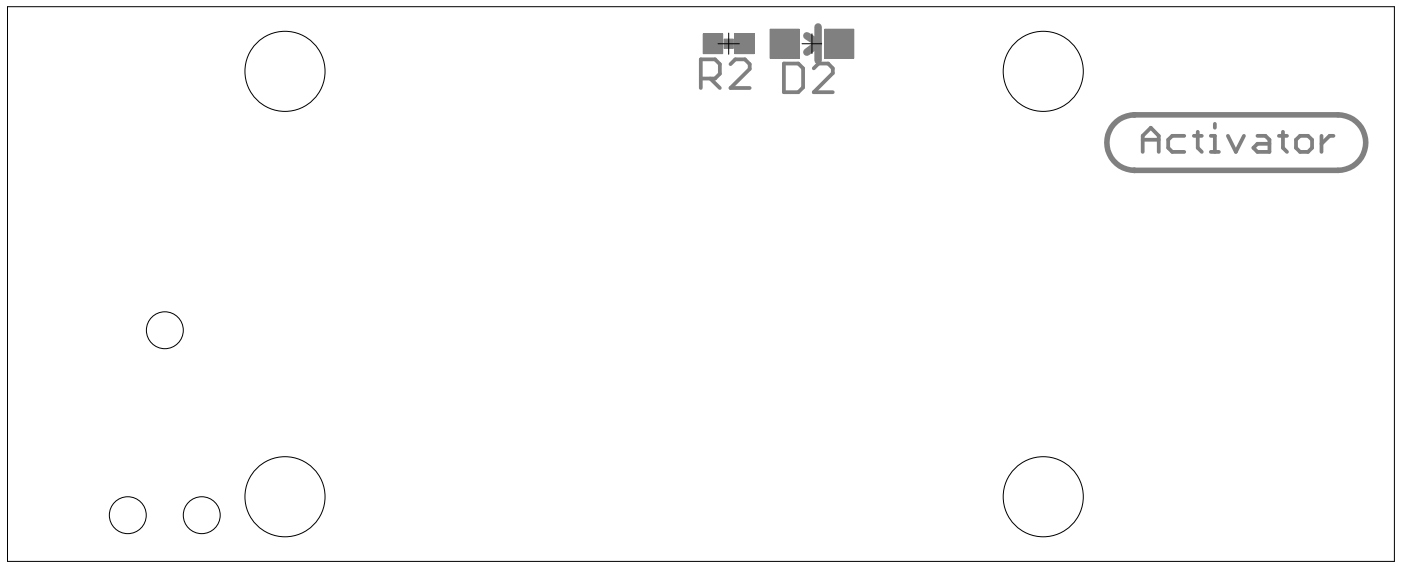
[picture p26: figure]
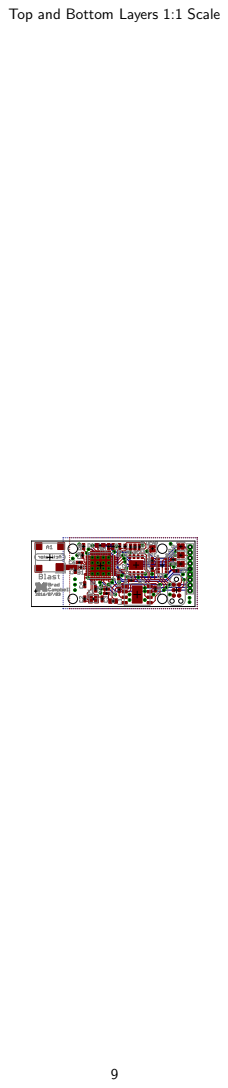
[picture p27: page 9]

Top and Bottom Layers 1:1 Scale

Top Layer 1:1 Scale

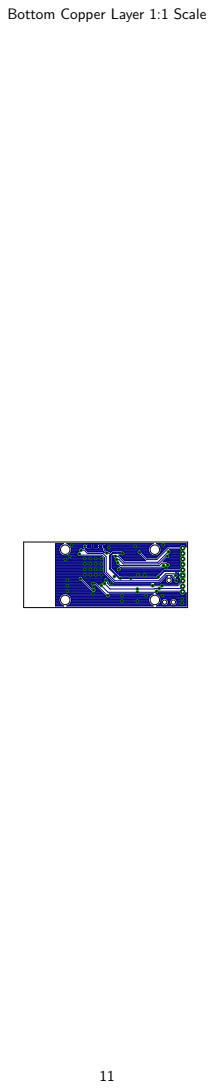
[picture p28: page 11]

Bottom Copper Layer 1:1 Scale

### blast

Note Qty Value | Device
1 FRACTUS-2.4GHZ-FR05-S1-N-0-001 FRACTUS-2.4GHZ-FR05-S1-N-0-001
| 1 BAL-NRF01D3 | BAL-NRF01D3
| 10.8pF | CAPACITOR
| 212pF | CAPACITOR
| 21nF | CAPACITOR
| 12.2nF | CAPACITOR
DNP | 110nF | CAPACITOR
| 147nF | CAPACITOR
| 20.1uF | CAPACITOR
DNP | 10.1uF | CAPACITOR
| 11uF | CAPACITOR
| 12.2uF | CAPACITOR
| 14.7uF | CAPACITOR
| 2 BLUE | LED0603
| 1IMPULSE_GECKO_HEADER | IMPULSE_GECKO_HEADER
| 110uH | INDUCTOR0603
| 115nH | INDUCTOR0402
| 1 MOSFET-NCHANNELXFDN-3 | MOSFET-NCHANNELXFDN-3
| 2470 | RESISTOR
| 14.7k | RESISTOR
DNP | 24.7k | RESISTOR
DNP | 210k | RESISTOR
| 112k | RESISTOR
| 11M | RESISTOR
| 14.7M | RESISTOR
| 1 NRF51822QF | NRF51822QF
| 1 FM25LBTDFN-8 | FM25LBTDFN-8
DNP | 1 RV-3049-C3 | RV-3049-C3
DNP | 1 FM25V20-DG | FM25V20-DG
| 116MHz | TXC-8Y

### blast

Package | Parts
FRACTUS-ANTENNA-FR05-S1-N-0-001 A1
BAL-NRF01D3 | B1
0402_CAP | C1
0402_CAP | C2, C3
0402_CAP | C4, C5
0402_CAP | C6
0402_CAP | C7
0402_CAP | C8
0402_CAP | C9, C10
0402_CAP | C11
0402_CAP | C12
0402_CAP | C13
0402_CAP | C14
LED-0603 | D1, D2
HEADER1X9/0.05IN | J1
0603_CAP | L1
0402_CAP | L2
XFDFN-3 | Q1
0402_RES | R1, R2
0402_RES | R3
0402_RES | R4, R5
0402_RES | R6, R7
0402_RES | R8
0402_RES | R9
0402_RES | R10
QFN-48-6MM | U1
TDFN-8@1 | U2
MICRO-CRYSTAL-C3 | U3
TDFN-8/6MM | U4
TXC-8Y | X1

### blast

Description | DIGIKEY
Fractus Reach Xtend
50 ohm nominal input / conjugate match balun to nRF51422-QFAA, 497-13637-1-ND
0402 Capacitor | 490-6269-1-ND
0402 Capacitor | 490-6197-1-ND
0402 Capacitor | 490-1303-1-ND
0402 Capacitor | 490-5419-1-ND
0402 Capacitor | 445-1260-1-ND
0402 Capacitor | 445-1264-1-ND
0402 Capacitor | 445-4952-1-ND
0402 Capacitor | 445-4952-1-ND
0402 Capacitor | 1276-1513-1-ND
0402 Capacitor | 445-3882-1-ND
0402 Capacitor | 445-5947-1-ND
LEDs | 160-1837-1-ND
Header on the impulse EPIC-esque board.
| 490-4025-1-ND
| 587-1521-1-ND
Generic NMOS footprint | DMN2400UFB4-7DICT-ND
Resistor | RHM470CECT-ND
Resistor | RHM4.7KCECT-ND
Resistor | RHM4.7KCECT-ND
Resistor | RHM10KCECT-ND
Resistor | RHM12.0KCDCT-ND
Resistor | RHM1.0MCECT-ND
Resistor | 541-4.7MJCT-ND
Multiprotocol Bluetooth® 4.0 low energy/2.4 GHz RF SoC | 1490-1042-1-ND
IC FRAM 4KBIT 10MHZ 8SOIC | FM25L04B-DGRA-ND
The RV-3049-C3 is an ultra miniature Real-Time-Clock Module
Cypress FRAM | FM25V20-DGRA-ND
2mmx1.6mm SMD Crystal | 887-2003-1-ND

### blast

MOUSER | NEWARK RICHARDSON_RFPD FR05-S1-N-0001B

511-BAL-NRF01D3

949-NRF51822-QFAC-R7
877-FM25L04B-DG
RV-3049-C3
877-FM25V20-DG

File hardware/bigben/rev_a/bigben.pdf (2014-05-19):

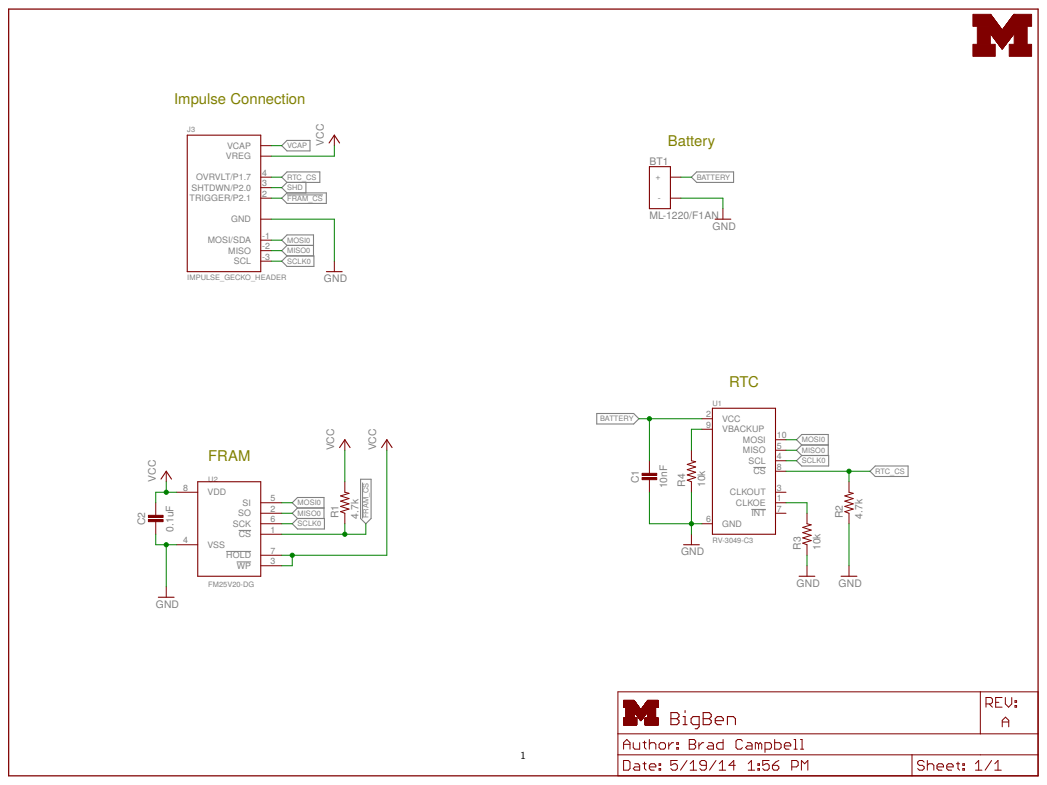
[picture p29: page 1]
1 FRAM Impulse Connection; RTC Battery GND VCC IMPULSE_GECKO_HEADER; RV-3049-C3 ML-1220/F1AN GND; GND ¹⁰k; 10k 10nF GND VCC; 4.7k VCC 0.1uF; 4.7k GND GND VCC VCAP VREG GND OVRVLT/P1.7; 4 SHTDWN/P2.0; 3 TRIGGER/P2.1; 2 J3 MOSI/SDA; -1 MISO; -2 SCL; MOSI; 10 MISO; 5 SCL; 4 CLKOUT; 3 CLKOE; 1 VCC 2; VBACKUP 9; INT; 7 GND 6; R² VDD 8; VSS 4; 2 SCK; 1 HOLD; FRAM_CS; FRAM_CS VCAP SHD MOSI0; MOSI0 MOSI0 MISO0; MISO0 MISO0 SCLK0; SCLK0 SCLK0; RTC_CS RTC_CS; BATTERY

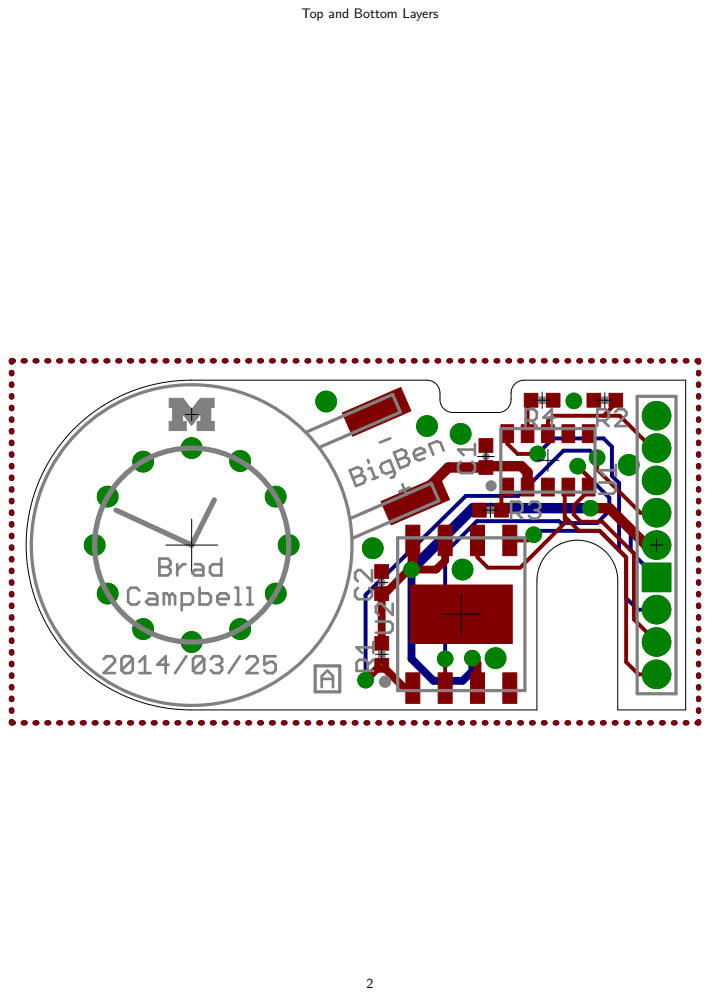
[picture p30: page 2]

Top and Bottom Layers

Top Layer

Bottom Layer


Top Copper Layer


Bottom Copper Layer


Top Paste Layer with Silkscreen

Bottom Paste Layer with Silkscreen


Top and Bottom Layers 1:1 Scale

Top Layer 1:1 Scale


Bottom Copper Layer 1:1 Scale

## Sheet1

Qty Value | Device | Package | Parts
1 ML-1220/F1AN | ML-1220/F1AN | ML-1220/F1BN | BT1
1 10nF | CAPACITOR | 0402_CAP | C1
1 0.1uF | CAPACITOR | 0402_CAP | C2
4 4.7k | RESISTOR | 0402_RES | R1, R2
2 10k | RESISTOR | 0402_RES | R3, R4
1 RV-3049-C3 | RV-3049-C3 | MICRO-CRYSTAL-C3 U1
1 FM25LBTDFN-8 | FM25LBTDFN-8 | TDFN-8 | U2

## Sheet1

Description | DIGIKEY | MOUSER
BATTERY LITH 3V RECHARGE PC PINS | P663-ND | 658-ML-1220/F1BN
0402 Capacitor | 445-1260-1-ND
0402 Capacitor | 445-1265-1-ND
Resistor | RHM4.7KCECT-ND
Resistor | RHM10KCECT-ND

### The RV-3049-C3 is an ultra miniature Real-Time-Clock Module

IC FRAM 4KBIT 10MHZ 8SOIC | | 877-FM25V20-DG

## Sheet1

### NEWARK

90R7604
90R7585

### RV-3049-C3

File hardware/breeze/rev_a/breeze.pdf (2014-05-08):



Top and Bottom Layers

Top Layer

Bottom Layer


Top Copper Layer


Bottom Copper Layer

Top Paste Layer with Silkscreen


Bottom Paste Layer with Silkscreen


Top and Bottom Layers 1:1 Scale

Top Layer 1:1 Scale


Bottom Copper Layer 1:1 Scale

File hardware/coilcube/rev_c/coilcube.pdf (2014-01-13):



### Top and Bottom Layers


### Top Layer


### Bottom Layer


### Top Copper Layer


### Bottom Copper Layer


### Top Paste Layer with Silkscreen


### Bottom Paste Layer with Silkscreen


### Top and Bottom Layers 1:1 Scale


### Top Layer 1:1 Scale

### Bottom Copper Layer 1:1 Scale


### Sheet1

### Page 1

Qty Value | Device | Package | Parts | Description | DIGIKEY | DIGIREEL | Notes
4 0.1uF | C-EUC0603 | C0603 | C1, C2, C3, C4 | CAPACITOR, European symbol445-1316-1-ND | 445-1316-6-ND
1 1uF | C-EUC0603 | C0603 | C5 | CAPACITOR, European symbol445-1321-1-ND | 445-1321-6-ND
1 2.2uF | CAP_POLEA1MM5 | CPOL_EEA_1MM5 C6 | P14506-ND
1 4.7uF | C-EUC0603 | C0603 | C7 | CAPACITOR, European symbol445-5178-1-ND | 445-5178-6-ND
1 10uF | C-EUC1206 | C1206 | C8 | CAPACITOR, European symbol399-8152-1-ND | 399-8152-6-ND
1 47uF | CAP_POL1206 | EIA3216 | C9 | Capacitor Polarized | 399-3700-1-ND | 399-3700-6-ND
5 100uF 25V | 2917_CAP_POL | 2917_CAP_POL | C10, C11, C12, C13, C14 | 399-5175-1-ND | 399-5175-6-ND | Replacement: 399-8410-1-ND
1 SCREW-TERMINAL_2_0.100SCREW-TERMINAL_2_0.100CONN_BLOCK_2 J1 | 2x 0.100 in screw terminal block277-1273-ND
1 10uH | INDUCTOR1210 | 1210 | L1 | Inductors | 587-1625-1-ND | 587-1625-6-ND
3 4.7k | R-US_R0603 | R0603 | R1, R2, R3 | RESISTOR, American symbol P4.7KGCT-ND | P4.7KGDKR-ND
1 1M | R-US_R0603 | R0603 | R4 | RESISTOR, American symbol RHM1.00MCFCT-ND | RHM1.00MCFDKR-ND
1 4.7M | R-US_R0603 | R0603 | R5 | RESISTOR, American symbol RHM4.7MCGCT-ND | RHM4.7MCGDKR-ND
2 NCHAN_MOSFET | NCHAN_MOSFET | NCHAN_MOSFET T1, T2 | SI1302DL-T1-GE3CT-ND SI1302DL-T1-GE3DKR-ND
1 NCHAN_MOSFET | NCHAN_MOSFET | NCHAN_MOSFET T3 | 568-3244-1-ND | 568-3244-6-ND
1 EPIC-CORE_A | EPIC-CORE_A | EPIC-LCC68 | U1 | | | | Customer provided.
1 LTC3588_ | LTC3588_ | MSOP-10-GNDPADU2 | Energy Harvesting Power SupplyLTC3588EMSE-1#PBF-ND
1 FM25LB | FM25LB | SOIC_8 | U3 | | 428-3210-ND

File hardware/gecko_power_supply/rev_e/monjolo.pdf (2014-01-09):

A

A


## Top and Bottom Layers


## Top Layer


## Bottom Layer


## Top Copper Layer


## Bottom Copper Layer


## Top Paste Layer with Silkscreen


## Bottom Paste Layer with Silkscreen

## Top and Bottom Layers 1:1 Scale


## Top Layer 1:1 Scale

## Bottom Copper Layer 1:1 Scale


Qty | Value | Layout | Parts | Digikey Part # | DIGIREEL | Coilcraft | Discription
| 1 10uF | C0603 | C1 | 445-7486-1-ND | 445-7486-6-ND | | CAP CER 10UF 10V 10% X5R 0603
| 1 4.7uF | C0603 | C2 | 490-6407-1-ND | 490-6407-6-ND | | CAP CER 4.7UF 6.3V 10% X5R 0603
| 4 100uF | C1206 | C3, C4, C5, C6, C7 | 478-3130-1-ND | 478-3130-6-ND | | CAP TANT 100UF 6.3V 20% 1210
| 1 AM-1417 | Solar cell | D1 | 869-1000-ND | | | SOLAR CELL AM 35MM X 13.9MM
| 1 LED | LED0603 | D2 | 160-1837-1-ND | 160-1837-6-ND | | LED BLUE CLEAR 0603 SMD
1 4.7uH | L-US | L1 | EPL3012-472MLB 4.7 UH INDUCTOR
| 1 PMOS | SOT23-3 | Q1 | SI2305ADS-T1-GE3CT-ND | SI2305ADS-T1-GE3DKR-ND | | MOSFET P-CH 8V 5.4A SOT23-3
| 2 MOSFET NP-CH | 6-TSOP | Q2, Q3 | SI3585DV-T1-E3CT-ND | SI3585DV-T1-E3DKR-ND | | MOSFET N/P-CH 20V 2A/1.5A 6-TSOP
| 3 1K | R0603 | R1, R2, R3 | RHM1.00KCFCT-ND | RHM1.00KCFDKR-ND | | RES 1.00K OHM 1/10W 1% 0603 SMD
| 4 100K | R0603 | R4, R5, R7, R11 | RHM100KCFCT-ND | RHM100KCFDKR-ND | | RES 100K OHM 1/10W 1% 0603 SMD
DNP | 100K | R0603 | R6 | RHM100KCFCT-ND | RHM100KCFDKR-ND | | RES 100K OHM 1/10W 1% 0603 SMD
| 3 470K | R0603 | R8, R9, R10 | RHM470KCFCT-ND | RHM470KCFDKR-ND | | RES 470K OHM 1/10W 1% 0603 SMD
| 1 649K | R0603 | R12 | 541-649KHCT-ND | 541-649KHDKR-ND | | RES 649K OHM 1/10W 1% 0603 SMD
| 1 976K | R0603 | R13 | 541-976KHCT-ND | 541-976KHDKR-ND | | RES 976K OHM 1/10W 1% 0603 SMD
| 1 470 | R0603 | R14 | RHM470CFCT-ND | RHM470CFDKR-ND | | RES 470 OHM 1/10W 1% 0603 SMD
| 1 MN1382S 2.0V | SOT23-3 | U1 | TC54VC2102ECB713CT-ND | TC54VC2102ECB713DKR-ND | | IC VOLT DETECT 2.0V CMOS SMD
| 1 TC54VC 2.9V | SOT23-3 | U2 | TC54VC2902ECB71CT-ND | TC54VC2902ECB71DKR-ND | | IC VOLT DETECTOR 2.9V SOT23A
| 1 MCP1640T | SOT23-6 | U3 | MCP1640T-I/CHYCT-ND | MCP1640T-I/CHYDKR-ND | | IC BOOST SYNC ADJ 0.1A SOT23-6

Notes

To use External Trigger solder R6 instead of R11

Not needed if not using external Trigger (R11 soldered)

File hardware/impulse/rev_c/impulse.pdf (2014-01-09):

# Programming Connection

## GND


2 FRAM Timing Circuit; DS2411 ID Chip DS2411; GND VCC; 2.2k VCC VCC; 4.7M GND².2uF; MOSFET-NCHANNELXFDN-3 GND VCC; 4.7k VCC 0.1uF; 1M GND; I/O VCC GND U1; R³ R¹C; Q1 VDD 8; VSS 4; 2 SCK; 1 HOLD; 3 U2 FM25LBTDFN-8; R⁵ C¹⁸; R¹² V_TIMER/1.5L TIME_CTL/1.5L; FRAM_CS/1.5I; FRAM_HOLD/1.5K; FRAM_WP/1.1L; ONEWIRE/1.1J MOSI0/1.7J MISO0/1.7J SCLK0/1.7I

## Top and Bottom Layers


## Top Layer


## Bottom Layer


## Top Copper Layer


## Layer 2 Copper


## Layer 3 Copper


## Bottom Copper Layer


## Top Paste Layer with Silkscreen


## Bottom Paste Layer with Silkscreen


## Top and Bottom Layers 1:1 Scale


## Top Layer 1:1 Scale

## Layer 2 Copper 1:1 Scale

## Layer 3 Copper 1:1 Scale

## Bottom Copper Layer 1:1 Scale


### Sheet1

Qty | Value | Device | Package | Parts | Description | DIGIKEY | DIGIREEL | MOUSER | TAG-CONNECT
1 MOLEX-2.4GHZ-047948 | MOLEX-2.4GHZ-047948 | MOLEX-47948-ANTENNAA1 | WM4893CT-ND | WM4893DKR-ND
| 1 BD2425N50200A | BD2425N50200A | BD2425N50200A | B1 | | 1173-1063-1-ND | 1173-1063-6-ND
| 1 12pF | CAPACITOR | 0402_CAP | C1 | 0402 Capacitor | 712-1257-1-ND | 712-1257-6-ND
| 2 22pF | CAPACITOR | 0402_CAP | C2, C3 | 0402 Capacitor | 445-1239-1-ND | 445-1239-6-ND
| 4 68pF | CAPACITOR | 0402_CAP | C4, C5, C6, C7 | 0402 Capacitor | 445-1245-1-ND | 445-1245-6-ND
| 1 0.01uF | CAPACITOR | 0402_CAP | C8 | 0402 Capacitor | 445-1260-1-ND | 445-1260-6-ND
10 0.1uF | CAPACITOR | 0402_CAP | C9, C10, C11, C12, C13, C14, C15, C16, C17, C180402 Capacitor | 445-1265-1-ND | 445-1265-6-ND
| 1 2.2uF | CAPACITOR | 0402_CAP | C19 | 0402 Capacitor | 445-3882-1-ND | 445-3882-6-ND
| 1 10uF | C-USC0805 | C0805 | C20 | CAPACITOR, American symbol | 478-2561-1-ND | 478-2561-6-ND
| 2 BLUE | LED-0603 | LED-0603 | D1, D2 | LED – BLUE
DNP | IMPULSE_GECKO_HEADER IMPULSE_GECKO_HEADER HEADER1X9/0.05IN | J1 | Header on the impulse EPIC-esque board
DNP | EPIC-PROG-POGO-NO-LEGSEPIC-PROG-POGO-NO-LEGSTC2030-IDC-NL | J2 | Epic programmer based on the Tag Connect pogo pin cable. | TC2030-IDC-NL
| 1 INDUCTOR0402 | INDUCTOR0402 | 0402_CAP | L1 | | 712-1419-1-ND | 712-1419-6-ND
1 MOSFET-NCHANNELXFDN-3MOSFET-NCHANNELXFDN-3XFDFN-3 | Q1 | Generic NMOS footprint | DMN2400UFB4-7DICT-NDDMN2400UFB4-7DIDKR-ND
| 1 2.2 | RESISTOR | 0402_RES | R1 | Resistor | RHM2.2CECT-ND | RHM2.2CEDKR-ND
| 1 470 | RESISTOR | 0402_RES | R2, R16 | Resistor | | RHM470BHDKR-ND
| 1 2.2k | RESISTOR | 0402_RES | R3 | Resistor | RHM2.2KCECT-ND | RHM2.2KCEDKR-ND
| 3 4.7k | RESISTOR | 0402_RES | R4, R5, R6 | Resistor | RHM4.7KCECT-ND | RHM4.7KCEDKR-ND
| 1 43k | RESISTOR | 0402_RES | R7 | Resistor | RHM43KCECT-ND | RHM43KCEDKR-ND
| 2 100k | RESISTOR | 0402_RES | R8, R9 | Resistor | RHM100KCECT-ND | RHM100KCEDKR-ND
| 4 1M | RESISTOR | 0402_RES | R10, R11, R12, R13 | Resistor | RHM1.0MCECT-ND | RHM1.0MCEDKR-ND
| 1 4.7M | RESISTOR | 0402_RES | R14 | Resistor | 541-4.7MJCT-ND | 541-4.7MJDKR-ND
| 1 5.1M | RESISTOR | 0402_RES | R15 | Resistor | RHM5.1MBICT-ND | RHM5.1MBIDKR-ND
| 1 DS2411 | DS2411 | SOT-23 | U1 | Maxim DS2411 | DS2411R+CT-ND | DS2411R+DKR-ND
| 1 FM25LBTDFN-8 | FM25LBTDFN-8 | TDFN-8 | U2 | IC FRAM 4KBIT 10MHZ 8SOIC | FM25L04B-DGRA-ND | | 877-FM25L04B-DG
| 1 MSP430F1611IRTD | MSP430F1611IRTD | S-PVQFN-N64 | U3 | | 296-18102-1-ND | 296-18102-6-ND
1 CC2420RGZ | CC2420RGZ | S-PVQFN-N48 | U4 | 2.4 GHz IEEE 802.15.4 / ZigBee-ready RF Transceiver 296-19585-1-ND | 296-19585-6-ND
| 1 TXC-7V | TXC-7V | TXC-7V | X1 | | 887-1799-1-ND | 887-1799-6-ND
| 1 ABRACON-ABS05 | ABRACON-ABS05 | ABS05 | X2 | 32.768kHz Crystal | 535-11899-1-ND | 535-11899-6-ND

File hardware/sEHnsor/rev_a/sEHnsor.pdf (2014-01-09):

## VCAP OV


32
42


Top and Bottom Layers

Top Layer

Bottom Layer


Top Copper Layer

Layer 2 Copper

Layer 3 Copper


Bottom Copper Layer


Top Paste Layer with Silkscreen

Bottom Paste Layer with Silkscreen


Top and Bottom Layers 1:1 Scale

Top Layer 1:1 Scale

Layer 2 Copper 1:1 Scale

Layer 3 Copper 1:1 Scale


Bottom Copper Layer 1:1 Scale

### sEHnsor_bom.xlsx

Qty Value | Device
1 FRACTUS-2.4GHZ-FR05-S1-N-0-001FRACTUS-2.4GHZ-FR05-S1-N-0-001
12450BM15A0002 | 2450BM15A0002
212pF | CAPACITOR
1220pF | CAPACITOR
11nF | CAPACITOR
80.1uF | CAPACITOR
31uF | CAPACITOR
12.2uF | CAPACITOR
1 GECKO_POWER_SUPPLY_CONN GECKO_POWER_SUPPLY_CONN
1 MOSFET-NCHANNELXFDN-3 | MOSFET-NCHANNELXFDN-3
22.2k | RESISTOR
34.7k | RESISTOR
156k | RESISTOR
14.7M | RESISTOR
1 DS2411 | DS2411
1 FM25LBTDFN-8 | FM25LBTDFN-8
1 CC2538 | CC2538
1 EPSON-FA-128 | EPSON-FA-128

### sEHnsor_bom.xlsx

Package | Parts
FRACTUS-ANTENNA-FR05-S1-N-0-001A1
2450BM | B1
0402_CAP | C1, C2
0402_CAP | C3
0402_CAP | C4
0402_CAP | C5, C6, C7, C8, C9, C10, C11, C12
0402_CAP | C13, C14, C15
0402_CAP | C16
HEADER1X6/0.05IN | J1
XFDFN-3 | Q1
0402_RES | R1, R2
0402_RES | R3, R4, R5
0402_RES | R6
0402_RES | R7
SOT-23 | U1
TDFN-8 | U2
S-PVQFN-N56 | U3
FA-128 | X1

### sEHnsor_bom.xlsx

Description | DIGIKEY
Fractus Reach Xtend
BALUN JTI MATCHED ZIGBEE | 712-1536-1-ND
0402 Capacitor | 445-1236-1-ND
0402 Capacitor | 445-1251-1-ND
0402 Capacitor | 445-2651-1-ND
0402 Capacitor | 445-1265-1-ND
0402 Capacitor | 445-4998-1-ND
0402 Capacitor | 445-10882-1-ND
Header on the gecko power supply board. | TMS-106-51-G-S-ND
Generic NMOS footprint | DMN2400UFB4-7DICT-ND
Resistor | RHM2.2KCECT-ND
Resistor | RHM4.7KCECT-ND
Resistor | RHM56KBHCT-ND
Resistor | 541-4.7MJCT-ND
Maxim DS2411 | DS2411R+CT-ND
IC FRAM 4KBIT 10MHZ 8SOIC | FM25L04B-DGRA-ND
A Powerful System-On-Chip for 2.4-GHz IEEE 802.15.4, 6LoWPAN296-35797-1-ND
MHz RANGE CRYSTAL UNIT | SER3800CT-ND

### sEHnsor_bom.xlsx

MOUSER | NEWARK RICHARDSON_RFPD FR05-S1-N-0001B

877-FM25L04B-DG
595-CC2538SF53RTQT87W7713
732-FA128-32F20X-K3

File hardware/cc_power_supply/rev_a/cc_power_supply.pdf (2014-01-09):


### Top and Bottom Layers


### Top Layer


### Bottom Layer


### Top Copper Layer


### Bottom Copper Layer


### Top Paste Layer with Silkscreen


### Bottom Paste Layer with Silkscreen

### Top and Bottom Layers 1:1 Scale


### Top Layer 1:1 Scale

### Bottom Copper Layer 1:1 Scale


cc_power_supply_bom.xlsx

Qty Value | Device | Package | Parts | Description | DIGIKEY | DIGIREEL | MOUSER
1 0.1uF | C-EUC0603 | C0603 | C1 | CAPACITOR, European symbol | 445-1316-1-ND | 445-1316-6-ND
1 1uF | C-EUC0603 | C0603 | C5 | CAPACITOR, European symbol | 445-1321-1-ND | 445-1321-6-ND
1 4.7uF | C-EUC0603 | C0603 | C7 | CAPACITOR, European symbol | 445-5178-1-ND | 445-5178-6-ND
1 10uF | C-EUC1206 | C1206 | C8 | CAPACITOR, European symbol | 399-8152-1-ND | 399-8152-6-ND
1 47uF | CAP_POL1206 | EIA3216 | C9 | Capacitor Polarized | 399-3700-1-ND | 399-3700-6-ND
5 100uF 25V | 2917_CAP_POL | 2917_CAP_POL | C10, C11, C12, C13, C14 | 399-5175-1-ND | 399-5175-6-ND
DNP SCREW-TERMINAL_2_0.100 | SCREW-TERMINAL_2_0.100 | CONN_BLOCK_2 J1 | 2x 0.100 in screw terminal block | 277-1273-ND
1 10uH | INDUCTOR1210 | 1210 | L1 | Inductors | 587-1625-1-ND | 587-1625-6-ND
2 NCHAN_MOSFET | NCHAN_MOSFET | NCHAN_MOSFET T1, T2 | SI1302DL-T1-GE3CT-ND SI1302DL-T1-GE3DKR-ND781-SI1302DL-E3
1 LTC3588_ | LTC3588_ | MSOP-10-GNDPAD U2 | Energy Harvesting Power Supply | LTC3588EMSE-1#PBF-ND
DNP GECKO_POWER_SUPPLY_CONNGECKO_POWER_SUPPLY_CONNHEADER1X6/0.05IN J1 | Header on the gecko power supply board.TMS-106-51-G-S-ND

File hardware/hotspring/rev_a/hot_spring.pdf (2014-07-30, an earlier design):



Top and Bottom Layers

Top Layer

Bottom Layer


Top Copper Layer


Bottom Copper Layer

Top Paste Layer with Silkscreen


Bottom Paste Layer with Silkscreen


Top and Bottom Layers 1:1 Scale

Top Layer 1:1 Scale


Bottom Copper Layer 1:1 Scale

### Sheet1

Qty Value | Device | Package
2 470pF | CAPACITOR | 0402_CAP
2 1000pF | CAPACITOR | 0402_CAP
1 0.1uF | CAPACITOR | 0402_CAP
1 1uF | CAPACITOR | 0402_CAP
1 2.2 uF | CAPACITOR | 0402_CAP
1 47uF | CAP1210 | 1210
5 100uF | 1210_CAP_POLARIZED | CAP1210
2 MOSFET-NCHANNELSMD | MOSFET-NCHANNELSMD | SOT23-3
1 DUAL_MOSFET_NP | DUAL_MOSFET_NP | TSOP-6
1 250k | RESISTOR0402_RES | 0402_RES
1 470k | RESISTOR0402_RES | 0402_RES
1 500k | RESISTOR0402_RES | 0402_RES
2 LPR6235-752SMR | LPR6235-752SMR | LPR6235
1 LTC3109EUF | LTC3109EUF | QFN-20-4MM

### Sheet1

Parts | Description | COILCRAFT
C1, C2 | 0402 Capacitor
C3, C4 | 0402 Capacitor
C5 | 0402 Capacitor
C6 | 0402 Capacitor
C7 | 0402 Capacitor
C8 | Capacitor
C9, C10, C11, C12, C13 Capacitor
Q1, Q2 | NMOS
Q3 | MOSFET N/P-CH 20V 2A 6-TSOP
R1 | Resistor
R2 | Resistor
R3 | Resistor
T1, T2 | Transformer 100:1 | LPR6235-752SMR
U1 | IC BOOST CONVERTER PMU 20QFN

### Sheet1

DIGIKEY | NEWARK
445-1255-1-ND
445-1256-1-ND
445-4952-1-ND
445-13185-1-ND
445-4999-1-ND
399-5515-1-ND
478-3130-1-ND
FDV301NCT-ND
SI3585DV-T1-E3CT-ND
RHM249KCDCT-ND
RHM470KCDCT-ND
RHM499KCDCT-ND

LTC3109EUF#PBF-ND 84R6674

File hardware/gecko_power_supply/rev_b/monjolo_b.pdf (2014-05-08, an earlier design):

SOLAR; (Tantalum) BUFFER; Voltage MONITOR; OVERVOLT DISCHARGE; EXTERNAL TRIGGER; (Optional); ENABLE; LATCH; INTERFACE; GND; VCAP; VREG; SHD; TRIG; Q2_NMOS; Q2_PMOS; Q5_NMOSQ5_PMOS; 1 VIN; VOUT; 5 VFB G

BOOST VOLTAGE REGULATOR


Top and Bottom Layers

Top Layer

Bottom Layer


Top Copper Layer


Bottom Copper Layer


Top Paste Layer with Silkscreen

Bottom Paste Layer with Silkscreen


Top and Bottom Layers 1:1 Scale

Top Layer 1:1 Scale


Bottom Copper Layer 1:1 Scale

12

Partlist exported | from | Dropbox/eagle/Gecko/SOLAR-MONJOLO_B/SOLAR-MONJOLO_B/SOLAR-MONJOLO_B.sch at ### 4:25
Qty | Value | Layout | Parts
1 LED | LED0603 | D2
1 LED RESISTOR | R0603 | R5
1 PMOS | SOT23-3 | Q1
3 1K | R0603 | R3 | R8 R10
3 1M | R0603 | R2 | R4 R7
1 4.7uF | C0603 | C2
1 4.7uH | L-US | L1
1 10uF | C0603 | C1
4 100K | R0603 | R1 | R6 R12 R15
1 649K | R0603 | R16
1 976K | R0603 | R14
1 AM-1437 | Solar cell | D1
2 MOSFET NP-CH 6-TSOP | Q2 | Q5
1 MCP1640T | SOT23-6 | U4
1 MN1382S 2.0V | SOT23-3 | U1
1 TC54VC 2.9V | SOT23-3 | U3
3 100uF | C1206 | C1A | C1C C1D

13

Digikey Part # | Discription
SI2305ADS-T1-GE3CT-ND | MOSFET P-CH 8V 5.4A SOT23-3
P1.00KHCT-ND | RES 1.00K OHM 1/10W 1% 0603 SMD
P470KHCT-ND | RES 470K OHM 1/10W 1% 0603 SMD
490-3297-1-ND | CAP CER 4.7UF 6.3V 10% X5R 0603
Order from coilcraft direct ->EPL3012-472MLB
445-7486-1-ND | CAP CER 10UF 10V 10% X5R 0603
P100KHCT-ND | RES 100K OHM 1/10W 1% 0603 SMD
P649KHCT-ND | RES 649K OHM 1/10W 1% 0603 SMD
P976KHCT-ND | RES 976K OHM 1/10W 1% 0603 SMD
SI3585DV-T1-E3CT-ND | MOSFET N/P-CH 20V 2A/1.5A 6-TSOP
MCP1640T-I/CHYCT-ND | IC BOOST SYNC ADJ 0.1A SOT23-6
MN1382SCPCT-ND | IC VOLT DETECT 2.0V CMOS SMD
TC54VC2902ECB71CT-ND | IC VOLT DETECTOR 2.9V SOT23A
478-3130-1-ND | CAP TANT 100UF 6.3V 20% 1210

14

Notes

Any color LED
VREG = 3V (try to use <5mA) select R value appropriately

1M Ohm should work but using the 470K that was tested

To use External Trigger solder R11 instead of R12

Much more expensive alternative at 1206 size for 100uF (478-3345-1-ND) Allowing C1B to be populated as well giving 400uF of capacitance.

If supply low: TC54VC2102ECB713CT-ND is a tested alternative

Not needed if not using external Trigger (R12
soldered)

15

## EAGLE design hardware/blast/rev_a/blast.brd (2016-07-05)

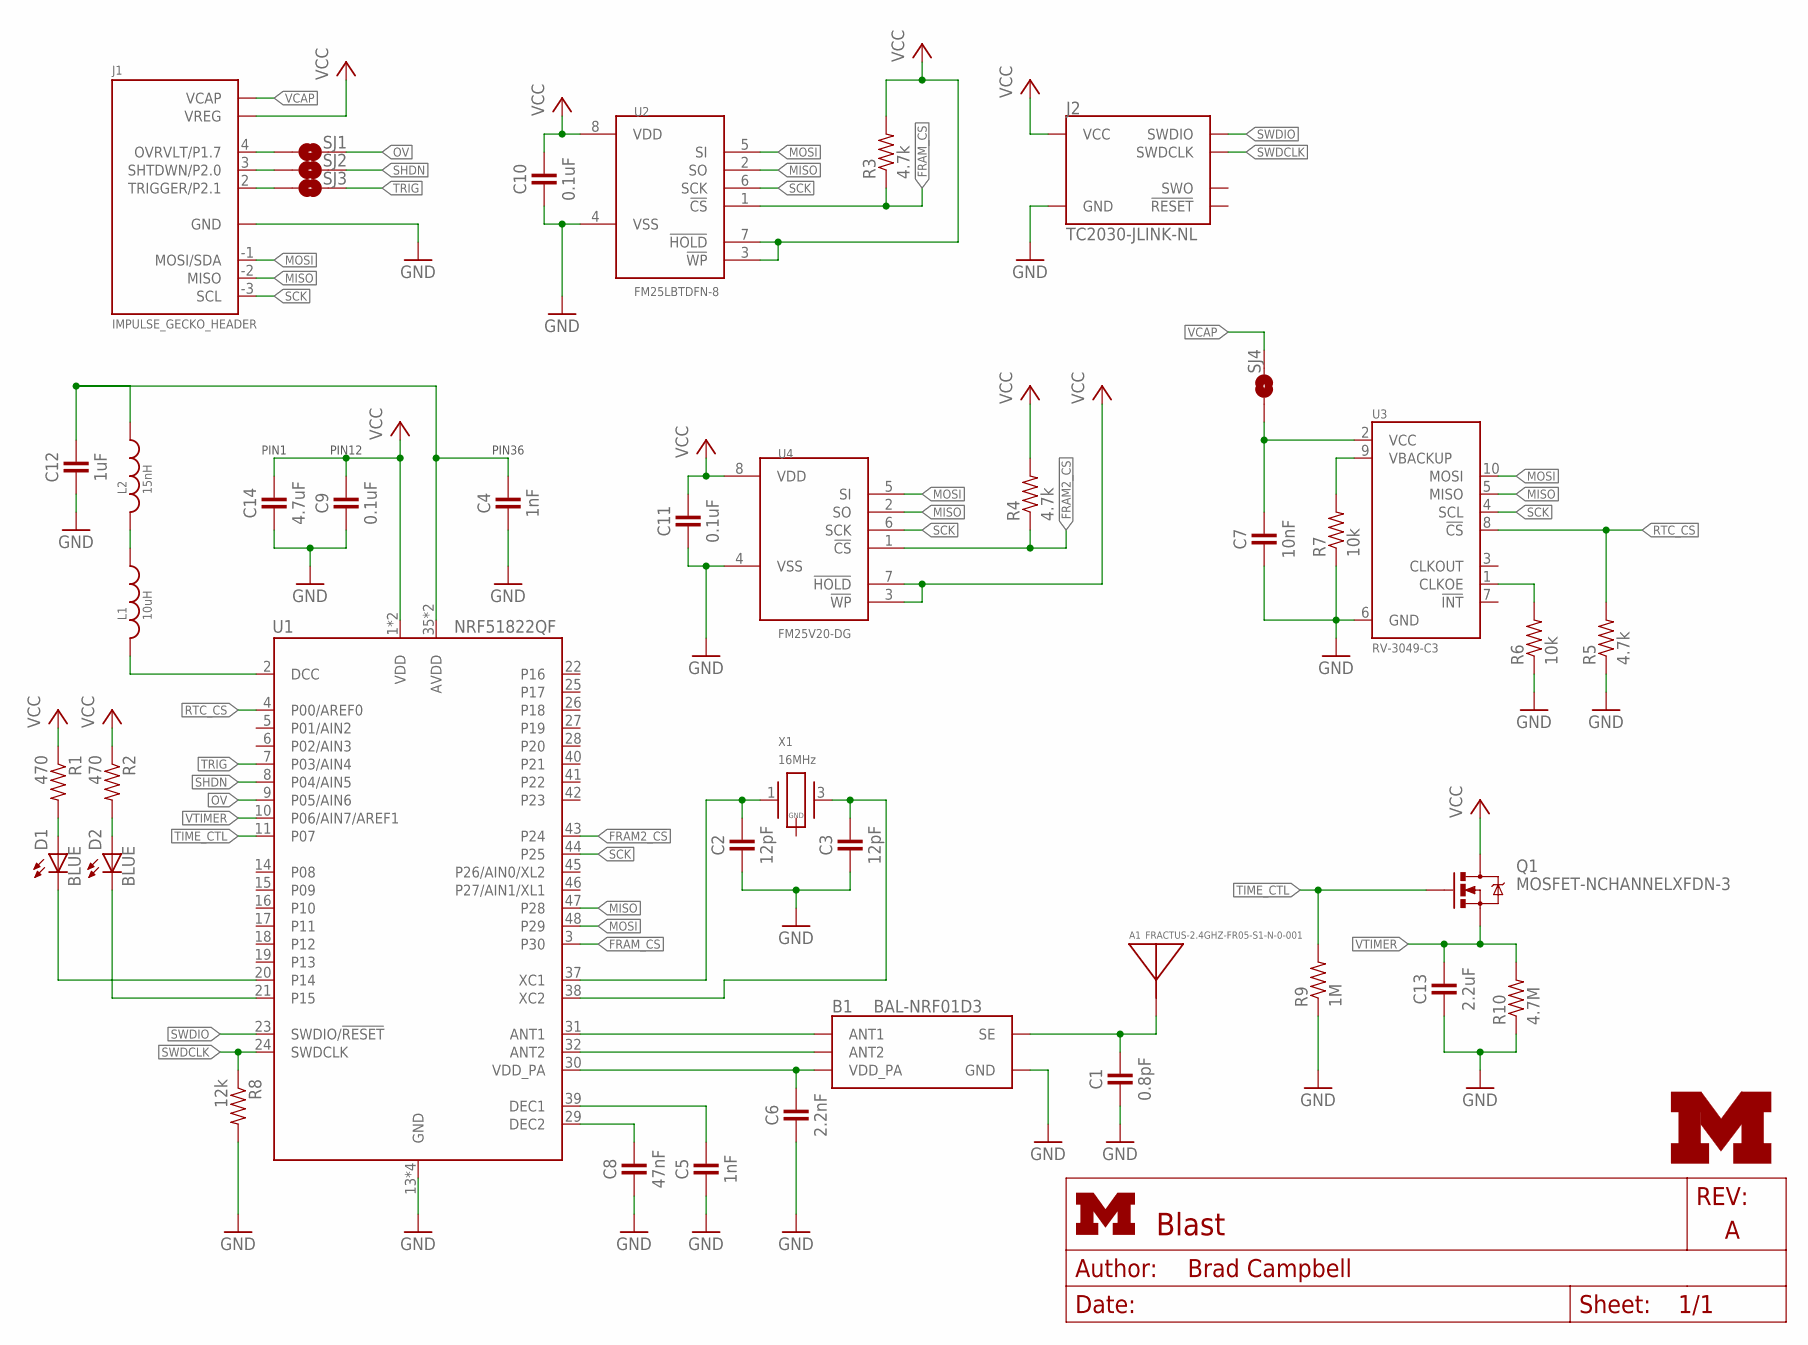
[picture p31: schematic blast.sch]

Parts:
A1: FRACTUS-2.4GHZ-FR05-S1-N-0-001; FRACTUS-ANTENNA-FR05-S1-N-0-001
B1: BAL-NRF01D3
C1: 0.8pF; 0402_CAP; DIGIKEY 490-6269-1-ND
C2, C3: 12pF; 0402_CAP; DIGIKEY 490-6197-1-ND
C4, C5: 1nF; 0402_CAP; DIGIKEY 490-1303-1-ND
C6: 2.2nF; 0402_CAP; DIGIKEY 490-5419-1-ND
C7: 10nF; 0402_CAP; DIGIKEY 445-1260-1-ND
C8: 47nF; 0402_CAP; DIGIKEY 445-1264-1-ND
C9, C10, C11: 0.1uF; 0402_CAP; DIGIKEY 445-4952-1-ND
C12: 1uF; 0402_CAP; DIGIKEY 1276-1513-1-ND
C13: 2.2uF; 0402_CAP; DIGIKEY 445-3882-1-ND
C14: 4.7uF; 0402_CAP; DIGIKEY 445-5947-1-ND
D1, D2: BLUE; LED-0603; DIGIKEY 160-1837-1-ND
J1: IMPULSE_GECKO_HEADER; HEADER1X9/0.05IN
J2: TC2030-JLINK-NL; TC2030-IDC-NL
L1: 10uH; 0603_CAP; DIGIKEY 490-4025-1-ND
L2: 15nH; 0402_CAP; DIGIKEY 587-1521-1-ND
Q1: MOSFET-NCHANNELXFDN-3; XFDFN-3
R1, R2: 470; 0402_RES; DIGIKEY RHM470CECT-ND
R3, R4, R5: 4.7k; 0402_RES; DIGIKEY RHM4.7KCECT-ND
R6, R7: 10k; 0402_RES; DIGIKEY RHM10KCECT-ND
R8: 12k; 0402_RES; DIGIKEY RHM12.0KCDCT-ND
R9: 1M; 0402_RES; DIGIKEY RHM1.0MCECT-ND
R10: 4.7M; 0402_RES; DIGIKEY 541-4.7MJCT-ND
SJ1, SJ2, SJ3, SJ4: SOLDERJUMPERNO; SJ_2S-NO
U1: NRF51822QF; QFN-48-6MM; DIGIKEY 1490-1042-1-ND
U2: FM25LBTDFN-8; TDFN-8@1; DIGIKEY FM25L04B-DGRA-ND
U3: RV-3049-C3; MICRO-CRYSTAL-C3
U4: FM25V20-DG; TDFN-8/6MM
U$1: UMICH_SOLID_SMALL; UMICH_SOLID_75MIL
X1: 16MHz; TXC-8Y; DIGIKEY 887-2003-1-ND

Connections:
!FRAM2_CS: R4.1, U1.43 (P24), U4.1 (!CS)
!FRAM_CS: R3.1, U1.3 (P30), U2.1 (!CS)
BATTERY: C7.1, SJ4.1, U3.2 (VCC)
GND: B1.GND, C1.2, C2.2, C3.2, C4.2, C5.2, C6.2, C7.2, C8.2, C9.2, C10.2, C11.2, C12.2, C13.2, C14.2, J1.0 (GND), J2.5 (GND), R5.1, R6.1, R7.1, R8.2, R9.1, R10.1, U1.13 (GND), U1.33 (GND), U1.34 (GND), U1.GND, U2.4 (VSS), U3.6 (GND), U4.4 (VSS)
MISO: J1.-2 (MISO), U1.47 (P28), U2.2 (SO), U3.5 (MISO), U4.2 (SO)
MOSI: J1.-1 (MOSI/SDA), U1.48 (P29), U2.5 (SI), U3.10 (MOSI), U4.5 (SI)
unnamed: D2.C, U1.21 (P15)
unnamed: B1.ANT1, U1.31 (ANT1)
unnamed: B1.ANT2, U1.32 (ANT2)
unnamed: D1.C, U1.20 (P14)
unnamed: R7.2, U3.9 (VBACKUP)
unnamed: R6.2, U3.1 (CLKOE)
unnamed: A1.1, B1.SE, C1.1
unnamed: C4.1, C12.1, L2.1, U1.35 (AVDD), U1.36 (AVDD)
unnamed: L1.2, U1.2 (DCC)
unnamed: L1.1, L2.2
unnamed: D2.A, R2.2
unnamed: C2.1, U1.37 (XC1), X1.1
unnamed: C3.1, U1.38 (XC2), X1.3 (2)
unnamed: C5.1, U1.39 (DEC1)
unnamed: C8.1, U1.29 (DEC2)
unnamed: J1.2 (TRIGGER/P2.1), SJ3.1
unnamed: J1.3 (SHTDWN/P2.0), SJ2.1
unnamed: J1.4 (OVRVLT/P1.7), SJ1.1
unnamed: D1.A, R1.2
OV: SJ1.2, U1.9 (P05/AIN6)
RTC_CS: R5.2, U1.4 (P00/AREF0), U3.8 (!CS)
SCK: J1.-3 (SCL), U1.44 (P25), U2.6 (SCK), U3.4 (SCL), U4.6 (SCK)
SHDN: SJ2.2, U1.8 (P04/AIN5)
SWDCLK: J2.4 (SWDCLK), R8.1, U1.24 (SWDCLK)
SWDIO: J2.2 (SWDIO), U1.23 (SWDIO/!RESET)
TIME_CTL: Q1.G, R9.2, U1.11 (P07)
TRIG: SJ3.2, U1.7 (P03/AIN4)
VCAP: J1.5 (VCAP), SJ4.2
VCC: C9.1, C10.1, C11.1, C14.1, J1.1 (VREG), J2.1 (VCC), Q1.D, R1.1, R2.1, R3.2, R4.2, U1.1 (VDD), U1.12 (VDD), U2.3 (!WP), U2.7 (!HOLD), U2.8 (VDD), U4.3 (!WP), U4.7 (!HOLD), U4.8 (VDD)
VDD_PA: B1.VCC (VDD_PA), C6.1, U1.30 (VDD_PA)
VTIMER: C13.1, Q1.S, R10.2, U1.10 (P06/AIN7/AREF1)

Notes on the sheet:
PIN12
PIN1
PIN36

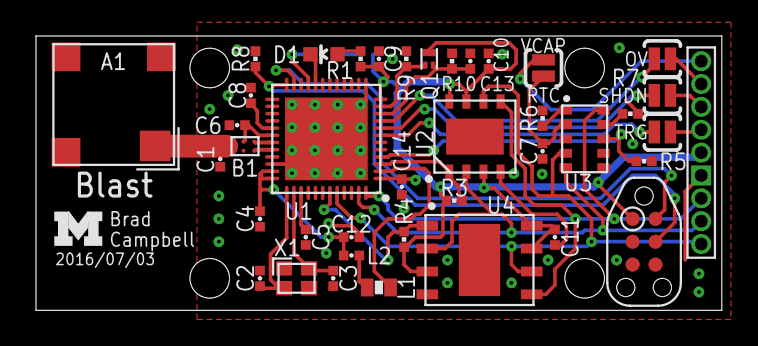
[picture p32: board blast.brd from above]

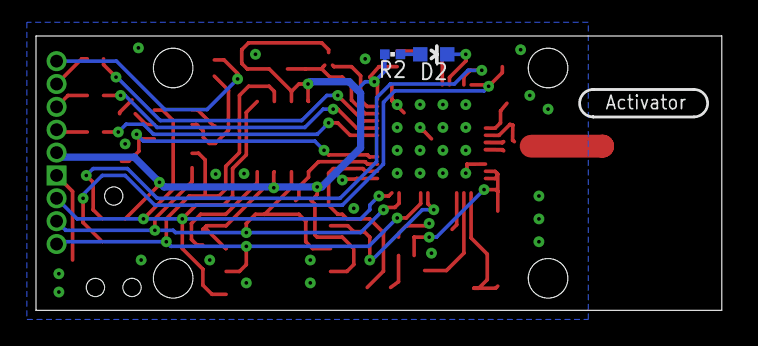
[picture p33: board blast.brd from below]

Board: 2 copper layers, 38.1 x 15.2 mm, 43 parts (2 on the bottom side), 37 nets.

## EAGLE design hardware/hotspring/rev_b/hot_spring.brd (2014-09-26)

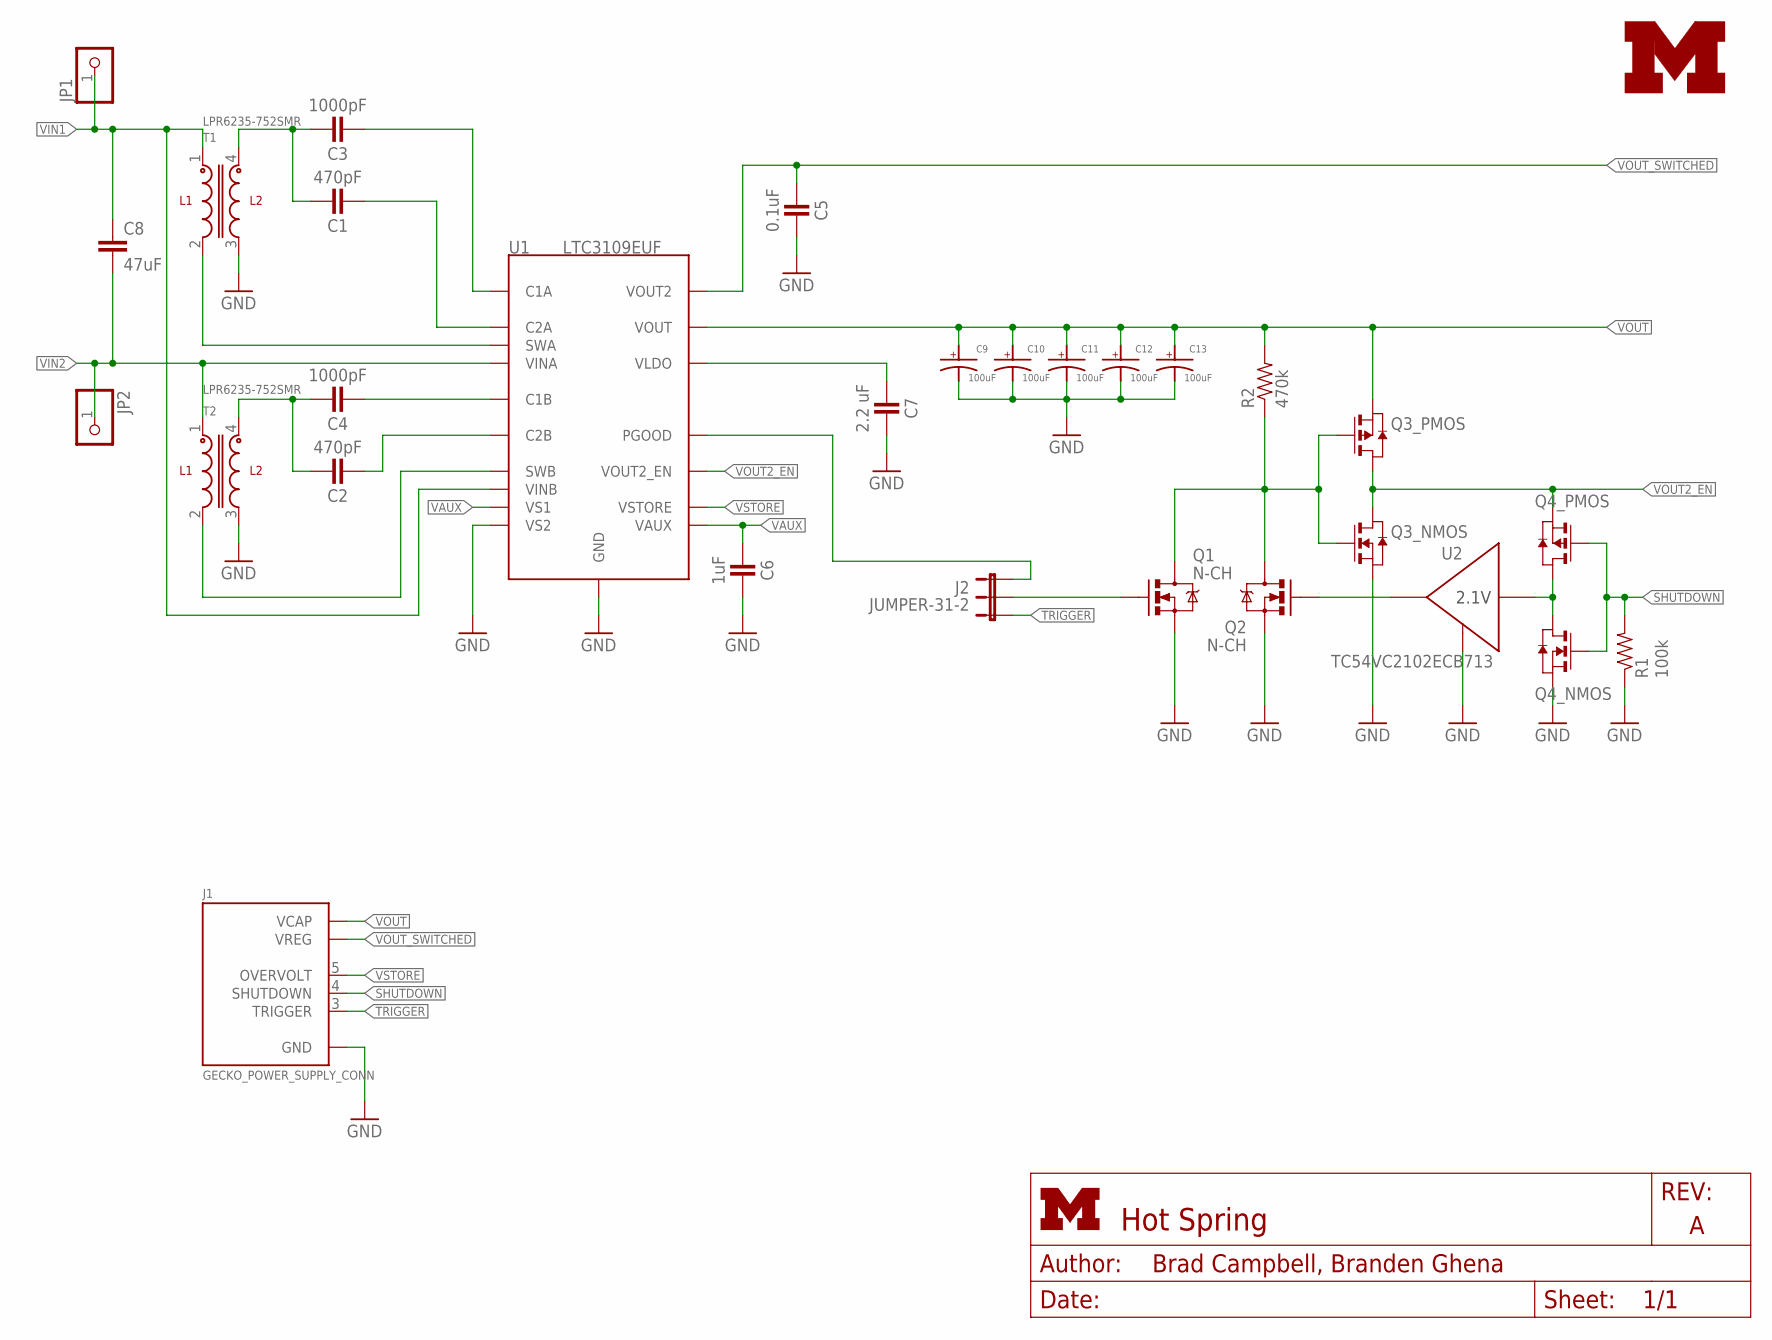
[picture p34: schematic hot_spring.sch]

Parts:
C1, C2: 470pF; 0402_CAP; DIGIKEY 445-1255-1-ND
C3, C4: 1000pF; 0402_CAP; DIGIKEY 445-1256-1-ND
C5: 0.1uF; 0402_CAP; DIGIKEY 445-4952-1-ND
C6: 1uF; 0402_CAP; DIGIKEY 445-13185-1-ND
C7: 2.2 uF; 0402_CAP; DIGIKEY 445-4999-1-ND
C8: 47uF; 1210; DIGIKEY 399-5515-1-ND
C9, C10, C11, C12, C13: 100uF; CAP1210; DIGIKEY 478-3130-1-ND
J1: GECKO_POWER_SUPPLY_CONN; HEADER1X6/0.05IN
J2: JUMPER-31-2; SJ_3_PASTE1&2
JP1, JP2: PINHD-1X1; 1X01
LOGO1: UMICH_SOLID_SMALL; UMICH_SOLID_75MIL
Q1, Q2: MOSFET-NCHANNELSMD; SOT23-3; DIGIKEY FDV301NCT-ND
Q3, Q4: DUAL_MOSFET_NP; TSOP-6
R1: 100k; 0402_RES; DIGIKEY RHM100KCDCT-ND
R2: 470k; 0402_RES; DIGIKEY RHM470KCDCT-ND
T1, T2: LPR6235-752SMR; LPR6235
U1: LTC3109EUF; QFN-20-4MM
U2: TC54VC2102ECB713; SOT-23

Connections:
GND: C5.1, C6.1, C7.1, C9.ANODE, C10.ANODE, C11.ANODE, C12.ANODE, C13.ANODE, J1.1 (GND), Q1.2 (S), Q2.2 (S), Q3.5 (S), Q4.5 (S), R1.1, T1.3, T2.3, U1.8 (GND), U1.11 (GND), U1.16 (GND), U1.20 (VS2), U1.GND, U2.2 (GND)
unnamed: C2.1, C4.1, T2.4
unnamed: C1.1, C3.1, T1.4
unnamed: C3.2, U1.18 (C1A)
unnamed: C1.2, U1.17 (C2A)
unnamed: Q4.4 (D), Q4.6 (D), U2.3 (IN)
unnamed: C4.2, U1.9 (C1B)
unnamed: C2.2, U1.10 (C2B)
unnamed: C7.2, U1.7 (VLDO)
unnamed: T1.2, U1.15 (SWA)
unnamed: T2.2, U1.12 (SWB)
unnamed: J2.2, Q1.1 (G)
unnamed: Q2.1 (G), U2.1 (OUT)
unnamed: Q1.3 (D), Q2.3 (D), Q3.1 (G), Q3.3 (G), R2.1
PGOOD: J2.1, U1.6 (PGOOD)
SHUTDOWN: J1.4 (SHUTDOWN), Q4.1 (G), Q4.3 (G), R1.2
TRIGGER: J1.3 (TRIGGER), J2.3
VAUX: C6.2, U1.2 (VAUX), U1.19 (VS1)
VIN1: C8.1, JP1.1, T1.1, U1.13 (VINB)
VIN2: C8.2, JP2.1, T2.1, U1.14 (VINA)
VOUT: C9.CATHODE, C10.CATHODE, C11.CATHODE, C12.CATHODE, C13.CATHODE, J1.6 (VCAP), Q3.2 (S), R2.2, U1.3 (VOUT)
VOUT2_EN: Q3.4 (D), Q3.6 (D), Q4.2 (S), U1.5 (VOUT2_EN)
VOUT_SWITCHED: C5.2, J1.2 (VREG), U1.4 (VOUT2)
VSTORE: J1.5 (OVERVOLT), U1.1 (VSTORE)

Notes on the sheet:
N-CH
2.1V

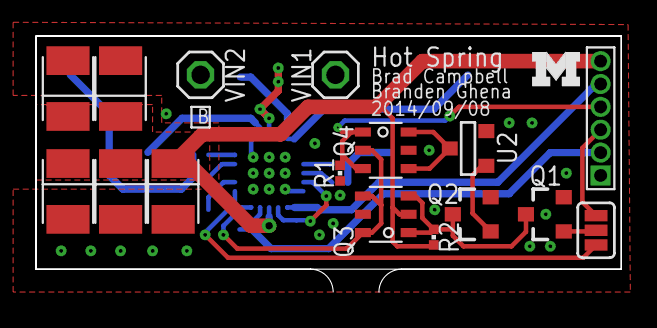
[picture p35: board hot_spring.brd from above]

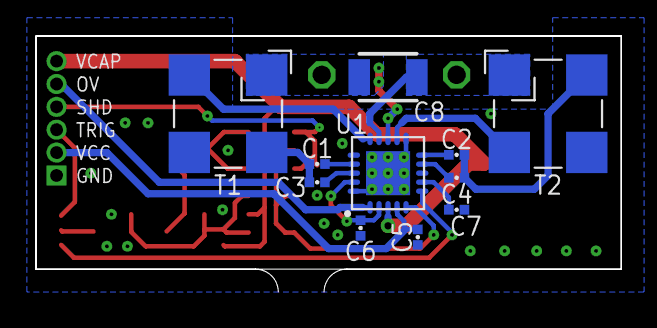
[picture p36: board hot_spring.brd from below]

Board: 2 copper layers, 32.5 x 14.2 mm, 28 parts (11 on the bottom side), 24 nets.

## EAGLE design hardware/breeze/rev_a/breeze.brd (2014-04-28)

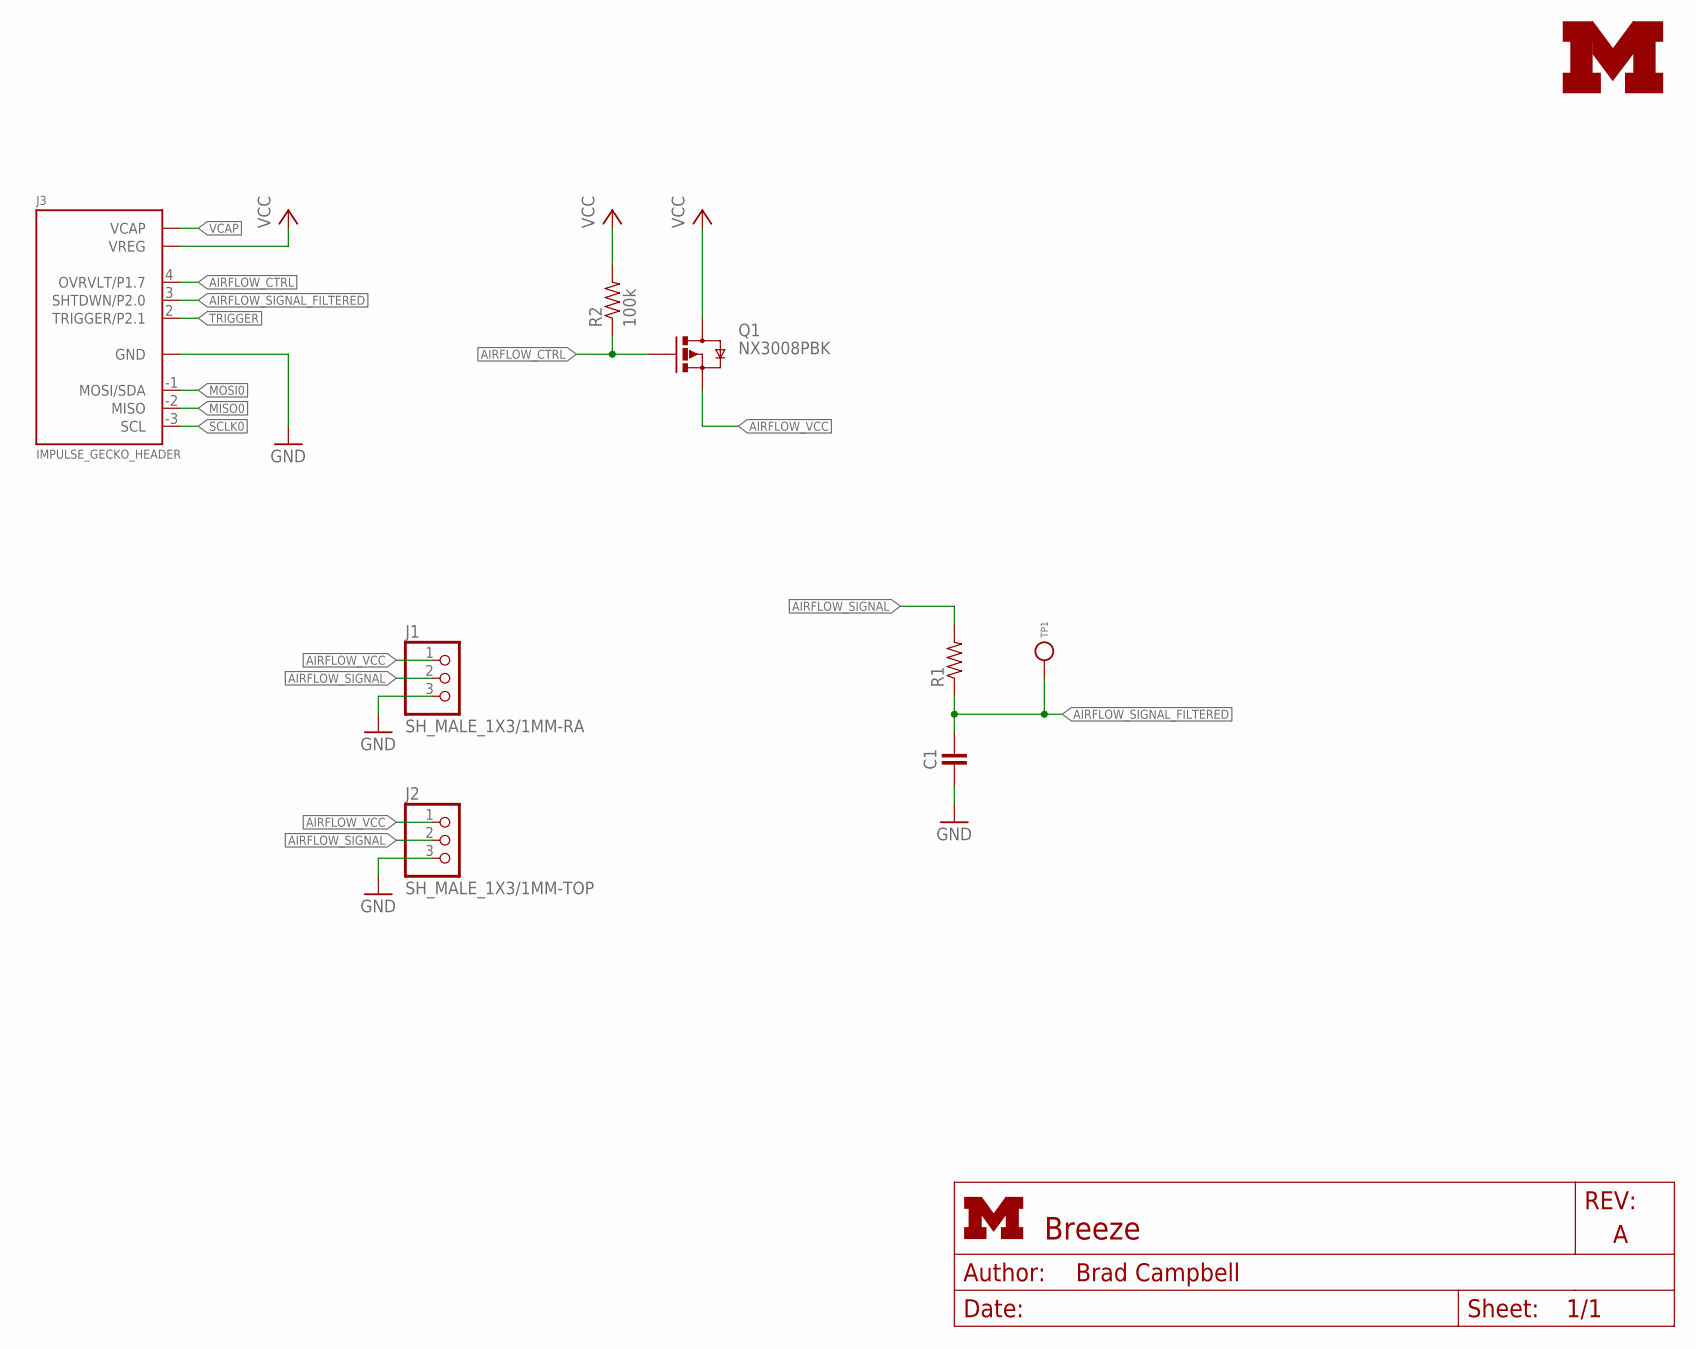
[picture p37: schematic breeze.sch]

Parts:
C1: CAPACITOR; 0402_CAP
J1: SH_MALE_1X3/1MM-RA; 1X3/SMD/SH/RA/1MM
J2: SH_MALE_1X3/1MM-TOP; 1X3/SMD/SH/1MM
J3: IMPULSE_GECKO_HEADER; HEADER1X9/0.05IN
LOGO1: UMICH_SOLID_TINY; UMICH_SOLID_50MIL
Q1: NX3008PBK; SOT23-3
R1: RESISTOR0402_RES; 0402_RES
R2: 100k; 0402_RES
TP1: TEST_POINT_0.040IN; TESTPOINT_0.040IN

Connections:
AIRFLOW_CTRL: J3.4 (OVRVLT/P1.7), Q1.1 (G), R2.1
AIRFLOW_SIGNAL: J1.2, J2.2, R1.2
AIRFLOW_SIGNAL_FILTERED: C1.1, J3.3 (SHTDWN/P2.0), R1.1, TP1.TESTPOINT
AIRFLOW_VCC: J1.1, J2.1, Q1.2 (S)
GND: C1.2, J1.3, J2.3, J3.0 (GND)
MISO0: J3.-2 (MISO)
MOSI0: J3.-1 (MOSI/SDA)
SCLK0: J3.-3 (SCL)
TRIGGER: J3.2 (TRIGGER/P2.1)
VCAP: J3.5 (VCAP)
VCC: J3.1 (VREG), Q1.3 (D), R2.2

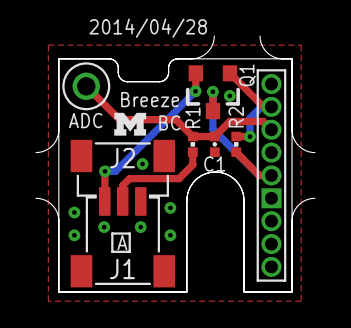
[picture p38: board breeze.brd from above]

Board: 2 copper layers, 13.0 x 13.0 mm, 9 parts (0 on the bottom side), 6 nets.

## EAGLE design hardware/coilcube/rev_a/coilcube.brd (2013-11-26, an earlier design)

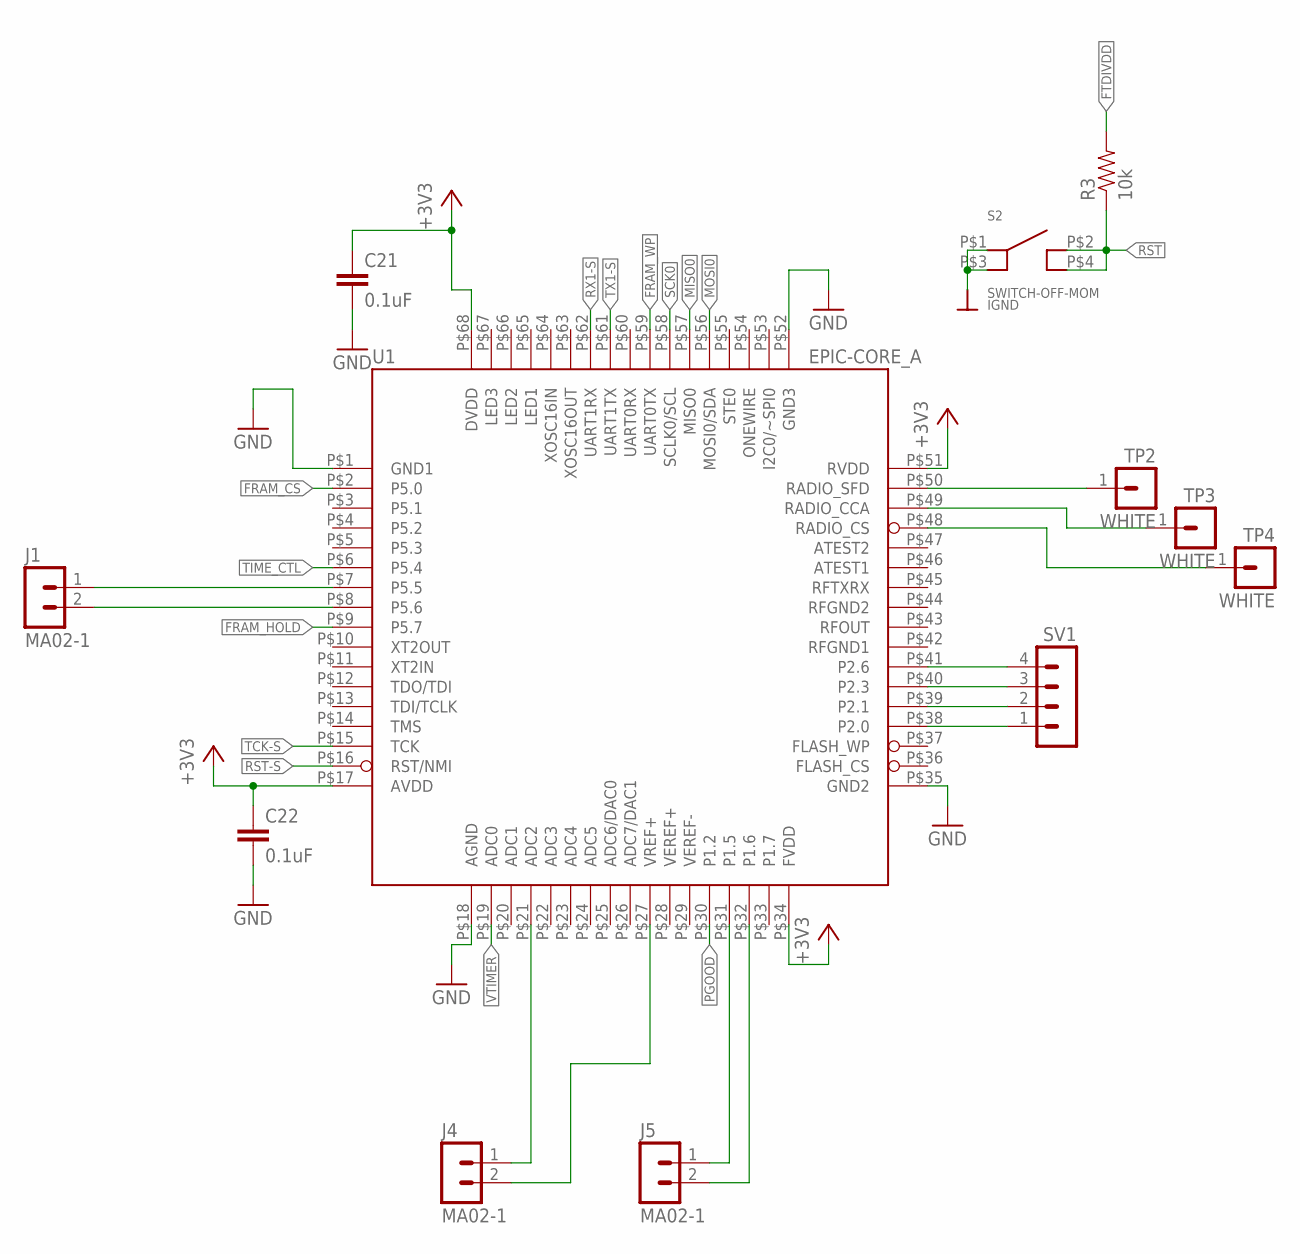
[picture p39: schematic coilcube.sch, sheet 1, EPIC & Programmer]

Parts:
C21, C22: 0.1uF; C0603; DIGIKEY 445-1316-1-ND
J1, J4: MA02-1; DIGIKEY 609-4434-ND
J5: MA02-1; DIGIEKY 609-4434-ND
R3: 10k; 0603-RES; DIGIKEY P10KGCT-ND
S2: SWITCH-OFF-MOM
SV1: MA04-1; DIGIKEY 609-3248-ND
TP2, TP3, TP4: WHITE; MA01-1; DIGIKEY 5002K-ND
U1: EPIC-CORE_A; EPIC-LCC68

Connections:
+3V3: C21.1, C22.1, U1.P$17 (AVDD), U1.P$34 (FVDD), U1.P$51 (RVDD), U1.P$68 (DVDD); also elsewhere on the board
FRAM_CS: U1.P$2 (P5.0); also elsewhere on the board
FRAM_HOLD: U1.P$9 (P5.7); also elsewhere on the board
FRAM_WP: U1.P$59 (UART0TX); also elsewhere on the board
FTDIVDD: R3.2; also elsewhere on the board
GND: C21.2, C22.2, U1.P$1 (GND1), U1.P$18 (AGND), U1.P$35 (GND2), U1.P$52 (GND3); also elsewhere on the board
IGND: S2.P$1 (P1), S2.P$3 (P3); also elsewhere on the board
MISO0: U1.P$57 (MISO0); also elsewhere on the board
MOSI0: U1.P$56 (MOSI0/SDA); also elsewhere on the board
unnamed: J5.1, U1.P$31 (P1.5)
unnamed: J5.2, U1.P$32 (P1.6)
unnamed: J4.1, U1.P$21 (ADC2)
unnamed: J4.2, U1.P$27 (VREF+)
unnamed: SV1.4, U1.P$41 (P2.6)
unnamed: SV1.3, U1.P$40 (P2.3)
unnamed: SV1.2, U1.P$39 (P2.1)
unnamed: SV1.1, U1.P$38 (P2.0)
unnamed: TP2.1, U1.P$50 (RADIO_SFD)
unnamed: TP3.1, U1.P$49 (RADIO_CCA)
unnamed: TP4.1, U1.P$48 (RADIO_CS)
unnamed: J1.1, U1.P$7 (P5.5)
unnamed: J1.2, U1.P$8 (P5.6)
PGOOD: U1.P$30 (P1.2); also elsewhere on the board
RST: R3.1, S2.P$2 (P2), S2.P$4 (P4); also elsewhere on the board
RST-S: U1.P$16 (RST/NMI); also elsewhere on the board
RX1-S: U1.P$62 (UART1RX); also elsewhere on the board
SCK0: U1.P$58 (SCLK0/SCL); also elsewhere on the board
TCK-S: U1.P$15 (TCK); also elsewhere on the board
TIME_CTL: U1.P$6 (P5.4); also elsewhere on the board
TX1-S: U1.P$61 (UART1TX); also elsewhere on the board
VTIMER: U1.P$19 (ADC0); also elsewhere on the board

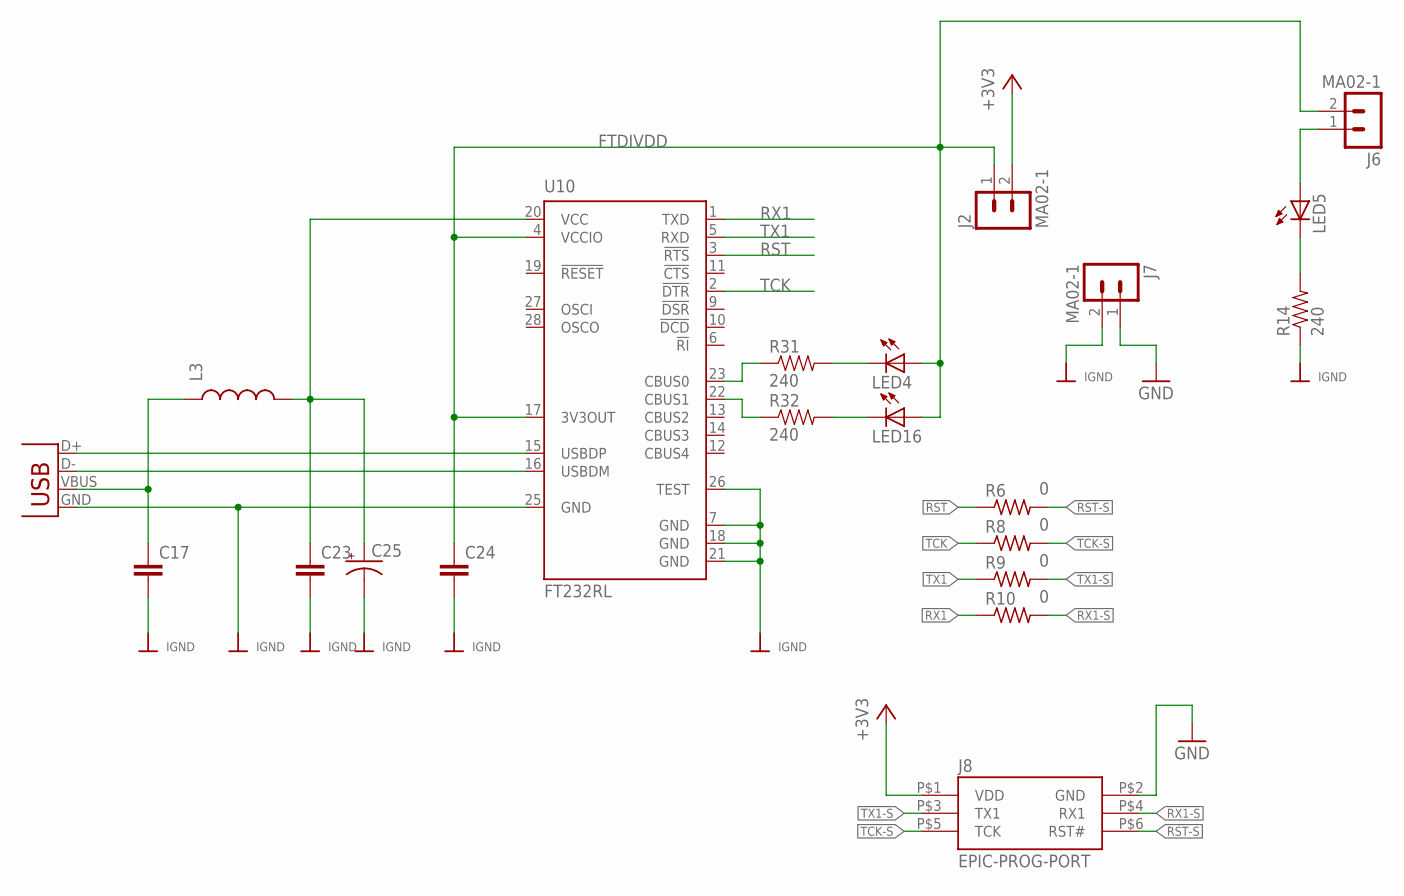
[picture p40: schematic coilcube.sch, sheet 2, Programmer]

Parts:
C17, C23, C24: CAP0603-CAP; 0603-CAP; DIGIKEY 445-1316-1-ND
C25: CAP_POL1206; EIA3216; DIGIKEY 478-1655-1-ND
J2, J6, J7: MA02-1; DIGIKEY 609-4434-ND
J8: EPIC-PROG-PORT; HEADER2X3X2MM; DIGIKEY WM18834-ND
L3: INDUCTOR0603; 0603; DIGIKEY 240-2373-1-ND
LED4: LED0603; LED-0603; DIGIKEY 1080-1400-1-ND
LED5, LED16: LED0603; LED-0603; DIGIKEY 1080-1405-1-ND
R6, R8, R9, R10: 0; R0603; DIGIKEY P0.0GCT-ND
R14, R31, R32: 240; 0603-RES; DIGIKEY P240GCT-ND
U10: FT232RL; SSOP28; DIGIKEY 768-1007-1-ND
X2: USBSMD; USB-MINIB; DIGIKEY 670-1190-1-ND

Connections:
+3V3: J2.2, J8.P$1 (VDD); also elsewhere on the board
FTDIVDD: C24.1, J2.1, J6.2, LED4.A, LED16.A, U10.4 (VCCIO), U10.17 (3V3OUT); also elsewhere on the board
GND: J7.1, J8.P$2 (GND); also elsewhere on the board
IGND: C17.2, C23.2, C24.2, C25.C (-), J7.2, R14.1, U10.7 (GND), U10.18 (GND), U10.21 (GND), U10.25 (GND), U10.26 (TEST), X2.GND; also elsewhere on the board
unnamed: J6.1, LED5.A
unnamed: LED5.C, R14.2
unnamed: U10.15 (USBDP), X2.D+
unnamed: U10.16 (USBDM), X2.D-
unnamed: LED4.C, R31.2
unnamed: LED16.C, R32.2
unnamed: R31.1, U10.23 (CBUS0)
unnamed: R32.1, U10.22 (CBUS1)
RST: R6.1, U10.3 (!RTS); also elsewhere on the board
RST-S: J8.P$6 (RST#), R6.2; also elsewhere on the board
RX1: R10.1, U10.1 (TXD)
RX1-S: J8.P$4 (RX1), R10.2; also elsewhere on the board
TCK: R8.1, U10.2 (!DTR)
TCK-S: J8.P$5 (TCK), R8.2; also elsewhere on the board
TX1: R9.1, U10.5 (RXD)
TX1-S: J8.P$3 (TX1), R9.2; also elsewhere on the board
USBVCC1: C23.1, C25.A (+), L3.2, U10.20 (VCC)
VBUS1: C17.1, L3.1, X2.VBUS

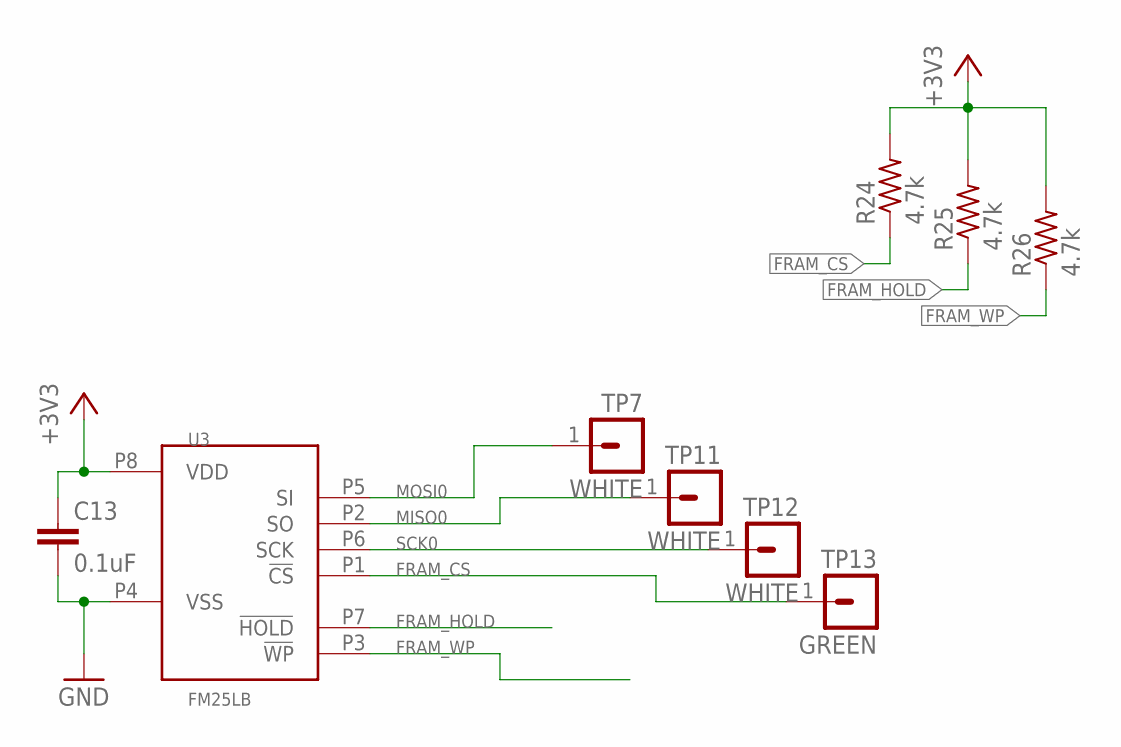
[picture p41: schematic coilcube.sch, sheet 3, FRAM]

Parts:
C13: 0.1uF; C0603; DIGIKEY 445-1316-1-ND
R24, R25, R26: 4.7k; R0603; DIGIKEY P4.7KGCT-ND
TP7, TP11, TP12: WHITE; MA01-1; DIGIKEY 5002K-ND
TP13: GREEN; MA01-1; DIGIKEY 5116K-ND
U3: FM25LB; SOIC_8; DIGIKEY 428-3210-ND

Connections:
+3V3: C13.1, R24.2, R25.2, R26.2, U3.P8 (VDD); also elsewhere on the board
FRAM_CS: R24.1, TP13.1, U3.P1 (!CS); also elsewhere on the board
FRAM_HOLD: R25.1, U3.P7 (!HOLD); also elsewhere on the board
FRAM_WP: R26.1, U3.P3 (!WP); also elsewhere on the board
GND: C13.2, U3.P4 (VSS); also elsewhere on the board
MISO0: TP11.1, U3.P2 (SO); also elsewhere on the board
MOSI0: TP7.1, U3.P5 (SI); also elsewhere on the board
SCK0: TP12.1, U3.P6 (SCK); also elsewhere on the board

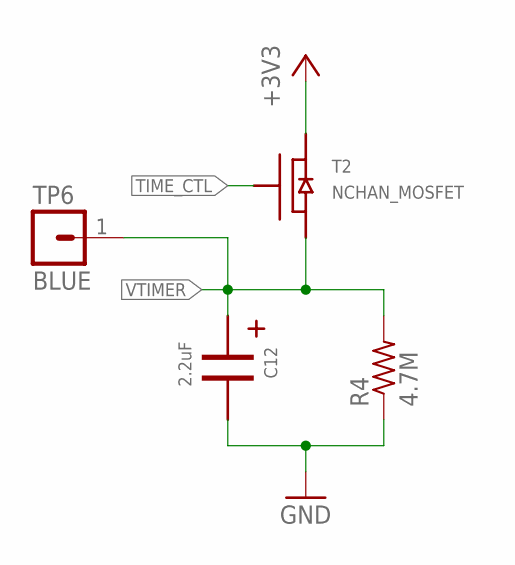
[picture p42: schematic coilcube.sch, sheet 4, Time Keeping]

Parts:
C12: 2.2uF; CPOL_EEA_1MM5
R4: 4.7M; R0805; DIGIKEY P4.7MACT-ND
T2: NCHAN_MOSFET; DIGIKEY 568-3244-1-ND
TP6: BLUE; MA01-1; DIGIKEY 5117K-ND

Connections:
+3V3: T2.D; also elsewhere on the board
GND: C12.-, R4.1; also elsewhere on the board
TIME_CTL: T2.G; also elsewhere on the board
VTIMER: C12.+, R4.2, T2.S, TP6.1; also elsewhere on the board


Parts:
C5, C6, C18, C19, C20: 100uF 25V; 2917_CAP_POL; DIGIKEY 399-5175-1-ND
C7: 1uF; C0603; DIGIKEY 445-1321-1-ND
C8: 4.7uF; C0603; DIGIKEY 445-5178-1-ND
C10: 0.1uF; C0603; DIGIKEY 445-1316-1-ND
C11: 10uF; C1206; DIGIKEY 399-8152-1-ND
C16: 47uF; EIA3216; DIGIKEY 399-3700-1-ND
J3: MA02-1; DIGIKEY A98333-ND
L1: 10uH; 1210; DIGIKEY 587-1625-1-ND
R1, R7: 0; R0603; DIGIKEY P0.0GCT-ND
R2, R5: NP; R0603
SW1: SWITCH_SPDP; DIGIKEY 563-1022-1-ND
T1, T3: NCHAN_MOSFET; DIGIKEY SI1302DL-T1-GE3CT-ND
TP1: ORANGE; MA01-1; DIGIKEY 5003K-ND
TP16: RED; MA01-1; DIGIKEY 5000K-ND
TP17: BLACK; MA01-1; DIGIKEY 5001K-ND
U2: LTC3588_; MSOP-10-GNDPAD; DIGIKEY LTC3588EMSE-1#PBF-ND

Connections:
+3V3: C11.1, C16.A (+), L1.2, T1.G, T3.G, TP16.1, U2.6 (VOUT); also elsewhere on the board
D0: R5.1, R7.1, U2.9 (D0)
D1: R1.1, R2.1, U2.8 (D1)
GND: C5.-, C6.-, C8.2, C10.2, C11.2, C16.C (-), C18.-, C19.-, C20.-, R2.2, R7.2, SW1.P3 (P2), T1.S, T3.S, TP17.1, U2.GND; also elsewhere on the board
unnamed: J3.1, SW1.P2 (PC), T3.D
unnamed: L1.1, U2.5 (SW)
unnamed: C7.2, U2.3 (CAP)
PGOOD: U2.10 (PGOOD); also elsewhere on the board
PZ1: J3.2, T1.D, U2.1 (PZ1)
PZ2: SW1.P1, U2.2 (PZ2)
VCAP: C5.+, C6.+, C7.1, C10.1, C18.+, C19.+, C20.+, TP1.1, U2.4 (VIN)
VIN2: C8.1, R1.2, R5.2, U2.7 (VIN2)

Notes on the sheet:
Output Voltage Selection


Board: 2 copper layers, 72.6 x 47.1 mm, 69 parts (0 on the bottom side), 53 nets.

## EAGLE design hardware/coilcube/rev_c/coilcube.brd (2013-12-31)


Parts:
ANT1: PIFA-2.4GHZ
C2, C3, C4: 0.1uF; C0603; DIGIKEY 445-1316-1-ND
C6: 2.2uF; CPOL_EEA_1MM5
J3: EPIC-PROG-POGO-NO-LEGS; TC2030-IDC-NL
R1, R2, R3: 4.7k; R0603; DIGIKEY P4.7KGCT-ND
R4: 1M; R0603; DIGIKEY RHM1.00MCFCT-ND
R5: 4.7M; R0603; DIGIKEY RHM4.7MCGDKR-ND
T3: NCHAN_MOSFET; DIGIKEY 568-3244-1-ND
U1: EPIC-CORE_A; EPIC-LCC68
U3: FM25LB; SOIC_8; DIGIKEY 428-3210-ND
U$1: UMICH_SOLID_MEDIUM; UMICH_SOLID_200MIL

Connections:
+3V3: C2.1, C3.1, C4.1, J3.1 (VDD), R1.2, R2.2, R3.2, T3.D, U1.P$17 (AVDD), U1.P$34 (FVDD), U1.P$51 (RVDD), U1.P$68 (DVDD), U3.P8 (VDD); also elsewhere on the board
FRAM_CS: R1.1, U1.P$2 (P5.0), U3.P1 (!CS)
FRAM_HOLD: R2.1, U1.P$9 (P5.7), U3.P7 (!HOLD)
FRAM_WP: R3.1, U1.P$59 (UART0TX), U3.P3 (!WP)
GND: C2.2, C3.2, C4.2, C6.-, J3.2 (GND), R4.1, R5.1, U1.P$1 (GND1), U1.P$18 (AGND), U1.P$35 (GND2), U1.P$52 (GND3), U3.P4 (VSS); also elsewhere on the board
MISO0: U1.P$57 (MISO0), U3.P2 (SO)
MOSI0: U1.P$56 (MOSI0/SDA), U3.P5 (SI)
unnamed: ANT1.P$1 (RFOUT), U1.P$43 (RFOUT)
PGOOD: U1.P$30 (P1.2); also elsewhere on the board
RFGND: ANT1.P$2 (RFGND), ANT1.P$3 (RFGND), U1.P$42 (RFGND1), U1.P$44 (RFGND2)
RST-S: J3.6 (RST#), U1.P$16 (RST/NMI)
RX1-S: J3.4 (RX1), U1.P$62 (UART1RX)
SCK0: U1.P$58 (SCLK0/SCL), U3.P6 (SCK)
TCK-S: J3.5 (TCK), U1.P$15 (TCK)
TIME_CTL: R4.2, T3.G, U1.P$6 (P5.4)
TX1-S: J3.3 (TX1), U1.P$61 (UART1TX)
VTIMER: C6.+, R5.2, T3.S, U1.P$19 (ADC0)

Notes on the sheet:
Programmer Connection
EPIC
FRAM
Timing Circuit


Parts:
C1: 0.1uF; C0603; DIGIKEY 445-1316-1-ND
C5: 1uF; C0603; DIGIKEY 445-1321-1-ND
C7: 4.7uF; C0603; DIGIKEY 445-5178-1-ND
C8: 10uF; C1206; DIGIKEY 399-8152-1-ND
C9: 47uF; EIA3216; DIGIKEY 399-3700-1-ND
C10, C11, C12, C13, C14: 100uF 25V; 2917_CAP_POL; DIGIKEY 399-5175-1-ND
J1: SCREW-TERMINAL_2_0.100; CONN_BLOCK_2
L1: 10uH; 1210; DIGIKEY 587-1625-1-ND
T1, T2: NCHAN_MOSFET; DIGIKEY SI1302DL-T1-GE3CT-ND
U2: LTC3588_; MSOP-10-GNDPAD; DIGIKEY LTC3588EMSE-1#PBF-ND

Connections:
+3V3: C8.1, C9.A (+), L1.2, T1.G, T2.G, U2.6 (VOUT); also elsewhere on the board
GND: C1.2, C7.2, C8.2, C9.C (-), C10.-, C11.-, C12.-, C13.-, C14.-, T1.S, T2.S, U2.9 (D0), U2.GND; also elsewhere on the board
unnamed: L1.1, U2.5 (SW)
unnamed: C5.2, U2.3 (CAP)
PGOOD: U2.10 (PGOOD); also elsewhere on the board
PZ1: J1.2, T1.D, U2.1 (PZ1)
PZ2: J1.1, T2.D, U2.2 (PZ2)
VCAP: C1.1, C5.1, C10.+, C11.+, C12.+, C13.+, C14.+, U2.4 (VIN)
VIN2: C7.1, U2.7 (VIN2), U2.8 (D1)



Board: 2 copper layers, 39.6 x 47.1 mm, 30 parts (4 on the bottom side), 23 nets.

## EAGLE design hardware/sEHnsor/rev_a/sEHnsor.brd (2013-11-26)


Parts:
A1: FRACTUS-2.4GHZ-FR05-S1-N-0-001; FRACTUS-ANTENNA-FR05-S1-N-0-001
B1: 2450BM15A0002; 2450BM
C1, C2: 12pF; 0402_CAP
C3: 220pF; 0402_CAP
C4: 1nF; 0402_CAP
C5, C6, C7, C8, C9, C10, C11, C12: 0.1uF; 0402_CAP
C13, C14, C15: 1uF; 0402_CAP
C16: 2.2uF; 0402_CAP
J1: GECKO_POWER_SUPPLY_CONN; HEADER1X6/0.05IN
J2: TC2030-CTX-NL; TC2030-IDC-NL
Q1: MOSFET-NCHANNELXFDN-3; XFDFN-3
R1, R2: 2.2k; 0402_RES
R3, R4, R5: 4.7k; 0402_RES
R6: 56k; 0402_RES
R7: 4.7M; 0402_RES
U1: DS2411; SOT-23
U2: FM25LBTDFN-8; TDFN-8; DIGIKEY FM25L04B-DGRA-ND
U3: CC2538; S-PVQFN-N56
U$1: UMICH_SOLID_SMALL; UMICH_SOLID_75MIL
X1: EPSON-FA-128; FA-128

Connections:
!FRAM_CS: R3.1, U2.1 (!CS), U3.8 (PC5)
!FRAM_HOLD: R4.1, U2.7 (!HOLD), U3.13 (PC1)
!FRAM_WP: R5.1, U2.3 (!WP), U3.7 (PC6)
!RESET: J2.3 (!RESET), R1.1
ANTENNA: A1.1, B1.1 (ANT)
DS2411: R2.1, U1.1 (I/O), U3.5 (PB0)
GND: B1.2 (GND), B1.5 (GND), B1.6 (GND), C1.2, C2.2, C3.2, C4.2, C5.2, C6.2, C7.2, C8.2, C9.2, C10.2, C11.2, C12.2, C13.2, C14.2, C15.2, C16.2, J1.1 (GND), J2.5 (GND), R6.2, R7.1, U1.3 (GND), U2.4 (VSS), U3.VSS_QFN (GND), X1.2 (GND), X1.4 (GND)
MISO: U2.2 (SO), U3.9 (PC4)
MOSI: U2.5 (SI), U3.11 (PC3)
unnamed: C4.1, R1.2, U3.28 (!RESET)
unnamed: R6.1, U3.42 (R_BIAS)
unnamed: C1.1, U3.34 (XOSC32M_Q1), X1.1
unnamed: C2.1, U3.35 (XOSC32M_Q2), X1.3 (2)
unnamed: C14.1, C15.1, U3.32 (DCOUPL2), U3.56 (DCOUPL1)
OV: J1.5 (OVERVOLT)
RF_N: B1.3 (BAL_N), U3.38 (RF_N)
RF_P: B1.4 (BAL_P), U3.37 (RF_P)
SCK: U2.6 (SCK), U3.12 (PC2)
SHD: J1.4 (SHUTDOWN), U3.6 (PC7)
TCK: J2.4 (TCK), U3.47 (JTAG_TCK)
TDI: U3.49 (PB6/JTAG-TDI)
TDO: J2.6 (TDO), U3.48 (PB7/JTAG-TDO)
TIME_CTL: Q1.G, U3.14 (PC0)
TMS: J2.2 (TMS), U3.46 (JTAG_TMS)
TRIG: J1.3 (TRIGGER)
VCAP: J1.6 (VCAP)
VCC: C3.1, C5.1, C6.1, C7.1, C8.1, C9.1, C10.1, C11.1, C12.1, C13.1, J1.2 (VREG), J2.1 (VCC), Q1.D, R2.2, R3.2, R4.2, R5.2, U1.2 (VCC), U2.8 (VDD), U3.10 (DVDD), U3.15 (DVDD), U3.24 (DVDD), U3.33 (AVDD), U3.36 (AVDD), U3.39 (AVDD), U3.40 (AVDD), U3.41 (AVDD), U3.43 (AVDD_GUARD), U3.55 (DVDD)
V_TIMER: C16.1, Q1.S, R7.2, U3.16 (PA0/ROM-UART-RX)

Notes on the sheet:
PIN10
PIN15
PIN24
PIN55
PIN33
PIN36
PIN40
PIN43


Board: 4 copper layers, 32.5 x 13.0 mm, 33 parts (0 on the bottom side), 24 nets.

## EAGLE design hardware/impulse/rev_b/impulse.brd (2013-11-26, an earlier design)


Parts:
A1: MOLEX-2.4GHZ-047948; MOLEX-47948-ANTENNA
B1: BD2425N50200A
C1: 12pF; 0402_CAP
C2, C3: 22pF; 0402_CAP
C4, C5, C6, C7: 68pF; 0402_CAP
C8: 0.01uF; 0402_CAP
C9, C10, C11, C12, C13, C14, C15, C16, C17: 0.1uF; 0402_CAP
C20: 10uF; C0805; DIGIKEY 478-2561-1-ND
D1: LED0603; LED-0603
J1: GECKO_POWER_SUPPLY_CONN; HEADER1X6/0.05IN
J2: EPIC-PROG-POGO-NO-LEGS; TC2030-IDC-NL
L1: INDUCTOR0402; 0402_CAP; DIGIKEY 712-1419-1-ND
R1: 2.2; 0402_RES
R2: 470; 0402_RES
R7: 43k; 0402_RES
R8, R9: 100k; 0402_RES
R10, R11, R13: 1M; 0402_RES
R15: 5.1M; 0402_RES
U3: MSP430F1611IRTD; S-PVQFN-N64
U4: CC2420RGZ; S-PVQFN-N48
U$1: UMICH_SOLID_SMALL; UMICH_SOLID_75MIL
X1: TXC-7V
X2: ABRACON-ABS05; ABS05

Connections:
!FRAM_CS: U3.44 (P5.0/STE1); also elsewhere on the board
!FRAM_HOLD: U3.51 (P5.7/TBOUTH/SVSOUT); also elsewhere on the board
!FRAM_WP: U3.32 (P3.4/UTXD0); also elsewhere on the board
!RADIO_CS: R13.2, U3.38 (P4.2/TB2), U4.31 (CSN)
!RADIO_RESET: R11.1, U3.42 (P4.6/TB6), U4.21 (RESETN)
!RESET: C14.1, J2.6 (RST#), R9.2, U3.58 (RST/NMI)
GND: C1.2, C2.2, C3.2, C4.2, C5.2, C6.2, C7.2, C8.2, C9.2, C10.2, C11.2, C12.2, C13.2, C14.2, C15.2, C16.2, C17.2, C20.2, D1.C, J1.1 (GND), J2.2 (GND), R7.1, R10.1, R15.1, U3.62 (AVSS), U3.63 (DVSS1), U3.GND (DVSS1), U4.5 (GND), U4.9 (GND2), U4.19 (DGND_GUARD), U4.22 (DGND), U4.23 (DSUB_PADS), U4.24 (DSUB_CORE), U4.VSS_QFN (AGND), X1.2 (GND), X1.4 (GND); also elsewhere on the board
MISO0: U3.30 (P3.2/MISO0), U4.34 (SO); also elsewhere on the board
MOSI0: U3.29 (P3.1/MOSI0/SDA), U4.33 (SI); also elsewhere on the board
unnamed: R8.1, U3.25 (P2.5/ROSC)
unnamed: R7.2, U4.45 (R_BIAS)
unnamed: D1.A, R2.1
unnamed: C20.1, R1.2
unnamed: C4.1, C5.1, C6.1, C7.1, C8.1, C9.1, C11.1, C12.1, C17.1, R1.1, U4.1 (VCO_GUARD), U4.2 (AVDD_VCO), U4.3 (AVDD_PRE), U4.4 (AVDD_RF1), U4.10 (AVDD_SW), U4.14 (AVDD_RF2), U4.15 (AVDD_IF2), U4.17 (AVDD_ADC), U4.18 (DVDD_ADC), U4.20 (DGUARD), U4.26 (DVDD1.8), U4.35 (DVDD_RAM), U4.37 (AVDD_XOSC16), U4.42 (VREG_OUT), U4.44 (AVDD_IF1), U4.48 (AVDD_CHP)
unnamed: U3.8 (XIN), X2.A (1)
unnamed: R2.2, U3.60 (P6.1/A1)
unnamed: R15.2, U3.9 (XOUT), X2.B (2)
unnamed: B1.1 (GND), C1.1, U4.7 (TXRX_SWITCH)
unnamed: B1.3 (BAL_N), L1.2, U4.8 (RF_N)
unnamed: B1.4 (BAL_P), L1.1, U4.6 (RF_P)
unnamed: C3.1, U4.38 (XOSC16_Q2), X1.3 (2)
unnamed: C2.1, U4.39 (XOSC16_Q1), X1.1
ONEWIRE: U3.24 (P2.4/CA1/TA2); also elsewhere on the board
OV: J1.5 (OVERVOLT)
RADIO_CCA: U3.16 (P1.4/SMCLK), U4.28 (CCA)
RADIO_FIFO: U3.15 (P1.3/TA2), U4.30 (FIFO)
RADIO_FIFOP: U3.12 (P1.0/TACLK), U4.29 (FIFOP)
RADIO_SFD: U3.37 (P4.1/TB1), U4.27 (SFD)
RADIO_VREG_EN: R10.2, U3.41 (P4.5/TB5), U4.41 (VREG_EN)
SCLK0: U3.31 (P3.3/UCLK0/SCL), U4.32 (SCLK); also elsewhere on the board
SHD: J1.4 (SHUTDOWN)
TCK: J2.5 (TCK), U3.57 (TCK)
TIME_CTL: U3.5 (P6.6/A6/DAC0); also elsewhere on the board
TRIG: J1.3 (TRIGGER)
UART1RX: J2.4 (RX1), U3.22 (P2.2/CAOUT/TA0/BSLRX), U3.35 (P3.7/URXD1)
UART1TX: J2.3 (TX1), U3.13 (P1.1/TA0/BSLTX), U3.34 (P3.6/UTXD1)
UNBAL: A1.1, B1.2 (ANT)
VCAP: J1.6 (VCAP)
VCC: C10.1, C13.1, C15.1, C16.1, J1.2 (VREG), J2.1 (VDD), R8.2, R9.1, R11.2, R13.1, U3.1 (DVCC), U3.64 (AVCC), U4.25 (DVDD3.3), U4.43 (VREG_IN); also elsewhere on the board
V_TIMER: U3.61 (P6.2/A2); also elsewhere on the board


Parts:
C18: 0.1uF; 0402_CAP
C19: 2.2uF; 0402_CAP
Q1: MOSFET-NCHANNELXFDN-3; XFDFN-3
R3: 2.2k; 0402_RES
R4, R5, R6: 4.7k; 0402_RES
R12: 1M; 0402_RES
R14: 4.7M; 0402_RES
U1: DS2411; SOT-23
U2: FM25LBTDFN-8; TDFN-8; DIGIKEY FM25L04B-DGRA-ND

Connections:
!FRAM_CS: R6.1, U2.1 (!CS); also elsewhere on the board
!FRAM_HOLD: R4.1, U2.7 (!HOLD); also elsewhere on the board
!FRAM_WP: R5.1, U2.3 (!WP); also elsewhere on the board
GND: C18.2, C19.2, R12.1, R14.1, U1.3 (GND), U2.4 (VSS); also elsewhere on the board
MISO0: U2.2 (SO); also elsewhere on the board
MOSI0: U2.5 (SI); also elsewhere on the board
ONEWIRE: R3.1, U1.1 (I/O); also elsewhere on the board
SCLK0: U2.6 (SCK); also elsewhere on the board
TIME_CTL: Q1.G, R12.2; also elsewhere on the board
VCC: C18.1, Q1.D, R3.2, R4.2, R5.2, R6.2, U1.2 (VCC), U2.8 (VDD); also elsewhere on the board
V_TIMER: C19.1, Q1.S, R14.2; also elsewhere on the board



Board: 4 copper layers, 32.5 x 13.0 mm, 49 parts (7 on the bottom side), 36 nets.

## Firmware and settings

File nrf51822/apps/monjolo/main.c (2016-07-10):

/*
 * Monjolo over BLE
 */

// Global libraries
#include <stdint.h>

// Nordic libraries
#include "ble_advdata.h"
#include "nrf_drv_spi.h"
#include "nrf_gpio.h"
#include "nrf_delay.h"
#include "nrf_drv_adc.h"
#include "app_util_platform.h"

// nrf5x-base libraries
#include "simple_ble.h"
#include "eddystone.h"

// FRAM
#include "fm25l04b.h"
// LEDs
#include "led.h"

/******************************************************************************/
// BLE
/******************************************************************************/

// Define constants about this beacon.
#define DEVICE_NAME "ligeiro"
#define PHYSWEB_URL "j2x.us/ligeir"

// Manufacturer specific data setup
#define UMICH_COMPANY_IDENTIFIER 0x02E0
#define UMICH_MANDATA_SERVICE_MONJOLO 0x18

// Monjolo Version
// 0: unused
// 1: coilcube rev a, rev b, rev c
// 2: sEHnsor
// 3: impulse rev a, rev b
// 4: coilcube/splitcore with impulse
// 5: gecko power supply + impulse
// 6: gecko power supply + impulse + buzz
// 7: hot spring + impulse
// 8: ligeiro (gecko power supply + blast)

typedef struct {
    uint8_t service;
    uint8_t version;
    uint8_t monjolo_version;
    uint32_t counter;
    uint32_t seq_no;
} __attribute__((packed)) monjolo_mandata_t;

static monjolo_mandata_t monjolo_mandata = {
    UMICH_MANDATA_SERVICE_MONJOLO,
    1, // Version 1 of this packet structure
    8, // Gecko power supply
    0,
    0
};

static ble_advdata_manuf_data_t mandata = {
    UMICH_COMPANY_IDENTIFIER,
    {
        sizeof(monjolo_mandata_t),
        (uint8_t*) &monjolo_mandata
    }
};

// Intervals for advertising and connections
static simple_ble_config_t ble_config = {
    .platform_id       = 0xd0,              // used as 4th octect in device BLE address
    .device_id         = DEVICE_ID_DEFAULT,
    .adv_name          = DEVICE_NAME,
    .adv_interval      = MSEC_TO_UNITS(30, UNIT_0_625_MS), // fast
    .min_conn_interval = MSEC_TO_UNITS(500, UNIT_1_25_MS),
    .max_conn_interval = MSEC_TO_UNITS(1000, UNIT_1_25_MS)
};


/******************************************************************************/
// FRAM
/******************************************************************************/

#define FM25L04B_nCS 30

static nrf_drv_spi_t _spi = NRF_DRV_SPI_INSTANCE(0);

fm25l04b_t fm25l04b = {
    .spi      = &_spi,
    .sck_pin  = SPI0_CONFIG_SCK_PIN,
    .mosi_pin = SPI0_CONFIG_MOSI_PIN,
    .miso_pin = SPI0_CONFIG_MISO_PIN,
    .ss_pin   = FM25L04B_nCS
};

/******************************************************************************/
// ADC
/******************************************************************************/

static nrf_drv_adc_config_t _adc_config = NRF_DRV_ADC_DEFAULT_CONFIG;
static nrf_drv_adc_channel_t _adc_channel_config = NRF_DRV_ADC_DEFAULT_CHANNEL(NRF_ADC_CONFIG_INPUT_7);

#define TIMER_CTL_PIN 7

/******************************************************************************/
// Monjolo
/******************************************************************************/

#define MAGIC_ID 0x63F2BA02

#define FRAM_ADDR_MAGIC   4
#define FRAM_ADDR_COUNTER FRAM_ADDR_MAGIC + 4
#define FRAM_ADDR_SEQ_NO  FRAM_ADDR_COUNTER + 4

typedef struct {
    uint32_t magic;
    uint32_t counter;
    uint32_t seq_no;
} __attribute__((packed)) monjolo_fram_t;

static monjolo_fram_t monjolo_fram;

#define LED_FRONT         14
#define LED_BACK          15



int main (void) {

    // Init LEDs
    led_init(LED_FRONT);
    led_init(LED_BACK);
    led_off(LED_FRONT);
    led_off(LED_BACK);

    // Setup BLE
    simple_ble_init(&ble_config);

    // Start by reading the FRAM
    fm25l04b_read(&fm25l04b, FRAM_ADDR_MAGIC, (uint8_t*) &monjolo_fram, sizeof(monjolo_fram_t));

    // See if this is our first wakeup
    if (monjolo_fram.magic != MAGIC_ID) {
        // If so, write the magic id
        monjolo_fram.magic = MAGIC_ID;
        fm25l04b_write(&fm25l04b, FRAM_ADDR_MAGIC, (uint8_t*) &monjolo_fram, 4);

        // And reset the counter and seq no just in case something happened
        monjolo_fram.counter = 0;
        monjolo_fram.seq_no = 0;
    }

    // Now because we woke up we increment the counter
    monjolo_fram.counter++;

    // Now setup ADC so we can read the timing capacitor
    nrf_adc_value_t timer_val;
    nrf_drv_adc_init(&_adc_config, NULL);

    // Execute a single ADC read.
    // Scale 1/3 because our input reference is 1.2 V.
    _adc_channel_config.config.config.input = NRF_ADC_CONFIG_SCALING_INPUT_ONE_THIRD;
    nrf_drv_adc_sample_convert(&_adc_channel_config, &timer_val);

    // Now check to see if we should suppress transmission or not.
    // Threshold of 400 selected to be about 5 seconds.
    if (timer_val < 400) {

        // Timing cap is low, transmit a packet
        monjolo_fram.seq_no++;

        // Save the current state
        fm25l04b_write(&fm25l04b, FRAM_ADDR_COUNTER, ((uint8_t*) &monjolo_fram)+4, 8);

        // Update outgoing packet
        monjolo_mandata.counter = monjolo_fram.counter;
        monjolo_mandata.seq_no = monjolo_fram.seq_no;

        // EddyStone + Device Name
        eddystone_with_manuf_adv(PHYSWEB_URL, &mandata);

        // Reset timing cap
        nrf_gpio_cfg_output(TIMER_CTL_PIN);
        nrf_gpio_pin_set(TIMER_CTL_PIN);

        // Blip LEDs
        led_on(LED_FRONT);
        led_on(LED_BACK);
        nrf_delay_ms(100);
        led_off(LED_FRONT);
        led_off(LED_BACK);

    } else {
        // Save the counter
        fm25l04b_write(&fm25l04b, FRAM_ADDR_COUNTER, ((uint8_t*) &monjolo_fram)+4, 4);

        // Waste energy on an LED
        led_on(LED_FRONT);
        led_on(LED_BACK);
    }

    while (1) {
        power_manage();
    }
}

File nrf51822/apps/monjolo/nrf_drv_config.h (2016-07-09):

/* Copyright (c) 2015 Nordic Semiconductor. All Rights Reserved.
 *
 * The information contained herein is property of Nordic Semiconductor ASA.
 * Terms and conditions of usage are described in detail in NORDIC
 * SEMICONDUCTOR STANDARD SOFTWARE LICENSE AGREEMENT.
 *
 * Licensees are granted free, non-transferable use of the information. NO
 * WARRANTY of ANY KIND is provided. This heading must NOT be removed from
 * the file.
 *
 */

#ifndef NRF_DRV_CONFIG_H
#define NRF_DRV_CONFIG_H

/**
 * Provide a non-zero value here in applications that need to use several
 * peripherals with the same ID that are sharing certain resources
 * (for example, SPI0 and TWI0). Obviously, such peripherals cannot be used
 * simultaneously. Therefore, this definition allows to initialize the driver
 * for another peripheral from a given group only after the previously used one
 * is uninitialized. Normally, this is not possible, because interrupt handlers
 * are implemented in individual drivers.
 * This functionality requires a more complicated interrupt handling and driver
 * initialization, hence it is not always desirable to use it.
 */
#define PERIPHERAL_RESOURCE_SHARING_ENABLED  0

/* CLOCK */
#define CLOCK_ENABLED 0

#if (CLOCK_ENABLED == 1)
#define CLOCK_CONFIG_XTAL_FREQ          NRF_CLOCK_XTALFREQ_Default
#define CLOCK_CONFIG_LF_SRC             NRF_CLOCK_LF_SRC_Xtal
#define CLOCK_CONFIG_IRQ_PRIORITY       APP_IRQ_PRIORITY_LOW
#endif

/* GPIOTE */
#define GPIOTE_ENABLED 0

#if (GPIOTE_ENABLED == 1)
#define GPIOTE_CONFIG_USE_SWI_EGU false
#define GPIOTE_CONFIG_IRQ_PRIORITY APP_IRQ_PRIORITY_LOW
#define GPIOTE_CONFIG_NUM_OF_LOW_POWER_EVENTS 1
#endif

/* TIMER */
#define TIMER0_ENABLED 0

#if (TIMER0_ENABLED == 1)
#define TIMER0_CONFIG_FREQUENCY    NRF_TIMER_FREQ_16MHz
#define TIMER0_CONFIG_MODE         TIMER_MODE_MODE_Timer
#define TIMER0_CONFIG_BIT_WIDTH    TIMER_BITMODE_BITMODE_32Bit
#define TIMER0_CONFIG_IRQ_PRIORITY APP_IRQ_PRIORITY_LOW

#define TIMER0_INSTANCE_INDEX      0
#endif

#define TIMER1_ENABLED 0

#if (TIMER1_ENABLED == 1)
#define TIMER1_CONFIG_FREQUENCY    NRF_TIMER_FREQ_16MHz
#define TIMER1_CONFIG_MODE         TIMER_MODE_MODE_Timer
#define TIMER1_CONFIG_BIT_WIDTH    TIMER_BITMODE_BITMODE_16Bit
#define TIMER1_CONFIG_IRQ_PRIORITY APP_IRQ_PRIORITY_LOW

#define TIMER1_INSTANCE_INDEX      (TIMER0_ENABLED)
#endif

#define TIMER2_ENABLED 0

#if (TIMER2_ENABLED == 1)
#define TIMER2_CONFIG_FREQUENCY    NRF_TIMER_FREQ_16MHz
#define TIMER2_CONFIG_MODE         TIMER_MODE_MODE_Timer
#define TIMER2_CONFIG_BIT_WIDTH    TIMER_BITMODE_BITMODE_16Bit
#define TIMER2_CONFIG_IRQ_PRIORITY APP_IRQ_PRIORITY_LOW

#define TIMER2_INSTANCE_INDEX      (TIMER1_ENABLED+TIMER0_ENABLED)
#endif

#define TIMER3_ENABLED 0

#if (TIMER3_ENABLED == 1)
#define TIMER3_CONFIG_FREQUENCY    NRF_TIMER_FREQ_16MHz
#define TIMER3_CONFIG_MODE         TIMER_MODE_MODE_Timer
#define TIMER3_CONFIG_BIT_WIDTH    TIMER_BITMODE_BITMODE_16Bit
#define TIMER3_CONFIG_IRQ_PRIORITY APP_IRQ_PRIORITY_LOW

#define TIMER3_INSTANCE_INDEX      (TIMER2_ENABLED+TIMER1_ENABLED+TIMER0_ENABLED)
#endif

#define TIMER4_ENABLED 0

#if (TIMER4_ENABLED == 1)
#define TIMER4_CONFIG_FREQUENCY    NRF_TIMER_FREQ_16MHz
#define TIMER4_CONFIG_MODE         TIMER_MODE_MODE_Timer
#define TIMER4_CONFIG_BIT_WIDTH    TIMER_BITMODE_BITMODE_16Bit
#define TIMER4_CONFIG_IRQ_PRIORITY APP_IRQ_PRIORITY_LOW

#define TIMER4_INSTANCE_INDEX      (TIMER3_ENABLED+TIMER2_ENABLED+TIMER1_ENABLED+TIMER0_ENABLED)
#endif


#define TIMER_COUNT (TIMER0_ENABLED + TIMER1_ENABLED + TIMER2_ENABLED + TIMER3_ENABLED + TIMER4_ENABLED)

/* RTC */
#define RTC0_ENABLED 0

#if (RTC0_ENABLED == 1)
#define RTC0_CONFIG_FREQUENCY    32678
#define RTC0_CONFIG_IRQ_PRIORITY APP_IRQ_PRIORITY_LOW
#define RTC0_CONFIG_RELIABLE     false

#define RTC0_INSTANCE_INDEX      0
#endif

#define RTC1_ENABLED 0

#if (RTC1_ENABLED == 1)
#define RTC1_CONFIG_FREQUENCY    32768
#define RTC1_CONFIG_IRQ_PRIORITY APP_IRQ_PRIORITY_LOW
#define RTC1_CONFIG_RELIABLE     false

#define RTC1_INSTANCE_INDEX      (RTC0_ENABLED)
#endif

#define RTC_COUNT                (RTC0_ENABLED+RTC1_ENABLED)

#define NRF_MAXIMUM_LATENCY_US 2000

/* RNG */
#define RNG_ENABLED 0

#if (RNG_ENABLED == 1)
#define RNG_CONFIG_ERROR_CORRECTION true
#define RNG_CONFIG_POOL_SIZE        8
#define RNG_CONFIG_IRQ_PRIORITY     APP_IRQ_PRIORITY_LOW
#endif

/* PWM */

#define PWM0_ENABLED 0

#if (PWM0_ENABLED == 1)
#define PWM0_CONFIG_OUT0_PIN        2
#define PWM0_CONFIG_OUT1_PIN        3
#define PWM0_CONFIG_OUT2_PIN        4
#define PWM0_CONFIG_OUT3_PIN        5
#define PWM0_CONFIG_IRQ_PRIORITY    APP_IRQ_PRIORITY_LOW
#define PWM0_CONFIG_BASE_CLOCK      NRF_PWM_CLK_1MHz
#define PWM0_CONFIG_COUNT_MODE      NRF_PWM_MODE_UP
#define PWM0_CONFIG_TOP_VALUE       1000
#define PWM0_CONFIG_LOAD_MODE       NRF_PWM_LOAD_COMMON
#define PWM0_CONFIG_STEP_MODE       NRF_PWM_STEP_AUTO

#define PWM0_INSTANCE_INDEX 0
#endif

#define PWM1_ENABLED 0
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

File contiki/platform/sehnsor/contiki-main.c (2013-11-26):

/*
 * Copyright (c) 2012, Texas Instruments Incorporated - http://www.ti.com/
 * All rights reserved.
 *
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
 * 3. Neither the name of the copyright holder nor the names of its
 *    contributors may be used to endorse or promote products derived
 *    from this software without specific prior written permission.
 *
 * THIS SOFTWARE IS PROVIDED BY THE COPYRIGHT HOLDERS AND CONTRIBUTORS
 * ``AS IS'' AND ANY EXPRESS OR IMPLIED WARRANTIES, INCLUDING, BUT NOT
 * LIMITED TO, THE IMPLIED WARRANTIES OF MERCHANTABILITY AND FITNESS
 * FOR A PARTICULAR PURPOSE ARE DISCLAIMED.  IN NO EVENT SHALL THE
 * COPYRIGHT HOLDER OR CONTRIBUTORS BE LIABLE FOR ANY DIRECT, INDIRECT,
 * INCIDENTAL, SPECIAL, EXEMPLARY, OR CONSEQUENTIAL DAMAGES
 * (INCLUDING, BUT NOT LIMITED TO, PROCUREMENT OF SUBSTITUTE GOODS OR
 * SERVICES; LOSS OF USE, DATA, OR PROFITS; OR BUSINESS INTERRUPTION)
 * HOWEVER CAUSED AND ON ANY THEORY OF LIABILITY, WHETHER IN CONTRACT,
 * STRICT LIABILITY, OR TORT (INCLUDING NEGLIGENCE OR OTHERWISE)
 * ARISING IN ANY WAY OUT OF THE USE OF THIS SOFTWARE, EVEN IF ADVISED
 * OF THE POSSIBILITY OF SUCH DAMAGE.
 */
/**
 * \addtogroup platform
 * @{
 *
 * \defgroup cc2538 The cc2538 Development Kit platform
 *
 * The cc2538DK is the new platform by Texas Instruments, based on the
 * cc2530 SoC with an ARM Cortex-M3 core.
 * @{
 *
 * \file
 *   Main module for the cc2538dk platform
 */
/*---------------------------------------------------------------------------*/
#include "contiki.h"
#include "dev/leds.h"
#include "dev/sys-ctrl.h"
#include "dev/scb.h"
#include "dev/nvic.h"
#include "dev/uart.h"
#include "dev/watchdog.h"
#include "dev/ioc.h"
#include "dev/button-sensor.h"
#include "dev/serial-line.h"
#include "dev/slip.h"
#include "dev/cc2538-rf.h"
#include "dev/udma.h"
#include "usb/usb-serial.h"
#include "lib/random.h"
#include "net/netstack.h"
#include "net/queuebuf.h"
#include "net/tcpip.h"
#include "net/uip.h"
#include "net/mac/frame802154.h"
#include "cpu.h"
#include "reg.h"
#include "ieee-addr.h"
#include "lpm.h"
#include "spi.h"
#include "fm25lb.h"

#include <stdint.h>
#include <string.h>
#include <stdio.h>
/*---------------------------------------------------------------------------*/
static void
set_rime_addr()
{
  ieee_addr_cpy_to(&rimeaddr_node_addr.u8[0], RIMEADDR_SIZE);
}
/*---------------------------------------------------------------------------*/
/**
 * \brief Main routine for the cc2538dk platform
 */
int
main(void)
{
  ioc_init();
  ioc_set_over(GPIO_A_NUM, 0, IOC_OVERRIDE_ANA);
  nvic_init();
  sys_ctrl_init();
  clock_init();
  lpm_init();
  rtimer_init();
  gpio_init();

  spi_init();
  fm25lb_init();

  process_init();

  watchdog_init();

//#if UART_CONF_ENABLE
//  uart_init();
//  uart_set_input(serial_line_input_byte);
//#endif
//  serial_line_init();

  INTERRUPTS_ENABLE();

  /* Initialise the H/W RNG engine. */
//  random_init(0);

  udma_init();

  process_start(&etimer_process, NULL);
  ctimer_init();

  set_rime_addr();
  netstack_init();
  cc2538_rf_set_addr(IEEE802154_PANID);

#if UIP_CONF_IPV6
  memcpy(&uip_lladdr.addr, &rimeaddr_node_addr, sizeof(uip_lladdr.addr));
  queuebuf_init();
  process_start(&tcpip_process, NULL);
#endif /* UIP_CONF_IPV6 */

  //process_start(&sensors_process, NULL);

//  energest_init();
//  ENERGEST_ON(ENERGEST_TYPE_CPU);

  autostart_start(autostart_processes);

  watchdog_start();

  while(1) {
    uint8_t r;
    do {
      /* Reset watchdog and handle polls and events */
      watchdog_periodic();

      r = process_run();
    } while(r > 0);

    /* We have serviced all pending events. Enter a Low-Power mode. */
    lpm_enter();
  }
}
/*---------------------------------------------------------------------------*/

/**
 * @}
 * @}
 */

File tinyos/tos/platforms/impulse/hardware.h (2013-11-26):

/**
 * Hardware definition for the Coilcube platform.
 *
 * @author Brad Campbell
 */
#ifndef _H_hardware_h
#define _H_hardware_h

#include "msp430hardware.h"

// enum so components can override power saving,
// as per TEP 112.
enum {
  TOS_SLEEP_NONE = MSP430_POWER_ACTIVE,
};

// internal flash is 16 bits in width
typedef uint16_t in_flash_addr_t;
// external flash is 32 bits in width
typedef uint32_t ex_flash_addr_t;

void wait(uint16_t t) {
  for ( ; t > 0; t-- );
}

// LEDS
TOSH_ASSIGN_PIN(RED_LED, 6, 1);
TOSH_ASSIGN_PIN(GREEN_LED, 4, 3);
TOSH_ASSIGN_PIN(YELLOW_LED, 4, 7);

// CC2420 RADIO
TOSH_ASSIGN_PIN(RADIO_CSN, 4, 2);
TOSH_ASSIGN_PIN(RADIO_VREF, 4, 5);
TOSH_ASSIGN_PIN(RADIO_RESET, 4, 6);
TOSH_ASSIGN_PIN(RADIO_FIFOP, 1, 0);
TOSH_ASSIGN_PIN(RADIO_SFD, 4, 1);
TOSH_ASSIGN_PIN(RADIO_GIO0, 1, 3);
TOSH_ASSIGN_PIN(RADIO_FIFO, 1, 3);
TOSH_ASSIGN_PIN(RADIO_GIO1, 1, 4);
TOSH_ASSIGN_PIN(RADIO_CCA, 1, 4);

TOSH_ASSIGN_PIN(CC_FIFOP, 1, 0);
TOSH_ASSIGN_PIN(CC_FIFO, 1, 3);
TOSH_ASSIGN_PIN(CC_SFD, 4, 1);
TOSH_ASSIGN_PIN(CC_VREN, 4, 5);
TOSH_ASSIGN_PIN(CC_RSTN, 4, 6);

// USART0
TOSH_ASSIGN_PIN(SIMO0, 3, 1);
TOSH_ASSIGN_PIN(SOMI0, 3, 2);
TOSH_ASSIGN_PIN(UCLK0, 3, 3);

// USART1
TOSH_ASSIGN_PIN(SIMO1, 5, 1);
TOSH_ASSIGN_PIN(SOMI1, 5, 2);
TOSH_ASSIGN_PIN(UCLK1, 5, 3);

// UART1
TOSH_ASSIGN_PIN(UTXD0, 3, 4);
TOSH_ASSIGN_PIN(URXD0, 3, 5);
TOSH_ASSIGN_PIN(UTXD1, 3, 6);
TOSH_ASSIGN_PIN(URXD1, 3, 7);

// User Interupt Pin
TOSH_ASSIGN_PIN(USERINT, 2, 7);

// FLASH
TOSH_ASSIGN_PIN(FLASH_CS, 4, 4);

// 1-Wire
TOSH_ASSIGN_PIN(ONEWIRE, 2, 4);


void TOSH_SET_PIN_DIRECTIONS(void)
{
  P3SEL = 0x0E; // set SPI and I2C to mod func

  P1DIR = 0xe0;
  P1OUT = 0x00;

  P2DIR = 0x7b;
  P2OUT = 0x10;

  P3DIR = 0xf1;
  P3OUT = 0x00;

  P4DIR = 0xfd;
  P4OUT = 0xdd;

  P5DIR = 0xff;
  P5OUT = 0xff;

  P6DIR = 0xff;
  P6OUT = 0x00;
}

// need to undef atomic inside header files or nesC ignores the directive
#undef atomic

#endif // _H_hardware_h

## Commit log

2013-07-05 Moved coilcube source from shed
    Fixed up some naming issues and formatted for the new tinyos build
    system.
    [RadioConfig.h, hardware.h]
2013-07-06 Added app to insert the node id in fram
    Fixed up some missing files and include folders as well.
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2013-07-16 App works correctly with blip and borderrouter now
    [coilcube_ip.h]
2013-07-18 Added gatd profile and correct IP
    [coilcube_ip.h]
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2013-07-23 Added all the gecko power supply revisions
    [monjolo_a.brd, monjolo_a.sch, monjolo_b.brd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]
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2013-08-09 added documentation to monjolo d
    [monjolo_d_bom.xls]
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2013-08-21 added cc power supply board
    Same form factor as the gecko power supply
    [cc_power_supply.brd, cc_power_supply.sch, cc_power_supply_bom.xlsx]
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2013-08-25 keep on improving my eagle documentation scripts
    [cc_power_supply_bom.csv]
2013-08-28 better doc cc power supply a
    [cc_power_supply.sch]
2013-09-06 added rev e of gecko power supply
    [monjolo.brd, monjolo.sch, monjolo_bom.csv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]
2013-09-06 Updated monjolo solar rev e
    [monjolo.brd, monjolo_bom.csv, monjolo_bom.xls]
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2013-09-09 added coilcube rev_c
    Should be ready to be assembled
    [coilcube.brd, coilcube.sch, coilcube_bom.csv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]
2013-09-13 preparing for a coilcube purchase
    [coilcube.brd, coilcube.sch, coilcube_bom.xlsx]
2013-09-13 updated bom for gecko ps
    [monjolo_bom.xls]
2013-09-15 Better bom, new eagle.py script
    [cc_power_supply_bom.csv, cc_power_supply_bom.xlsx]
2013-10-04 Added tinyos support for impulse
    Had to fix the clocks up and configure the led pin.
    [RadioConfig.h, hardware.h]
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2013-10-04 added in self charge when it gets too low
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2013-10-04 fixed backwardsness of led
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2013-10-04 v timer no longer clears itself
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2013-10-08 added cad files for the cutouts for the cc cases
    The female socket needs a hole in the case.
    [coilcube_case_cutout.dwg, coilcube_case_cutout.dxf]
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2013-10-08 added bom for the parts not on cc board
    [assembly_bom.xlsx]
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2013-10-14 Improved monjolo app that doesn't use ipv6
    [monjolo.h]
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2013-10-15 updated boms in excel
    [monjolo_bom.xls]
2013-10-15 added rev a of cc
    [coilcube.brd, coilcube.sch]
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2013-10-28 moved impulse to activator repo
    [impulse.brd, impulse.sch, impulse_bom.csv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]
2013-10-28 moved sEHnsor to activator repo
    [sEHnsor.brd, sEHnsor.sch, sEHnsor_bom.csv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]
2013-10-28 impulse rev c ready to ship
    [impulse.brd]
2013-10-28 updated bom with digireel
    impulse rev c
    [impulse_bom.xlsx]
2013-11-26 moved to hardware folder
    [cc_power_supply.brd, cc_power_supply.sch, cc_power_supply_bom.csv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]
2013-11-26 not sure how I got two
    [cc_power_supply.brd, cc_power_supply.sch, cc_power_supply_bom.csv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]
2013-11-26 moved to assembly folder
    [assembly_bom.xlsx, coilcube_case_cutout.dwg, coilcube_case_cutout.dxf]
2013-11-26 moved gecko power supply to its folder
    [monjolo.brd, monjolo.sch, monjolo_a.brd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]
2013-11-26 moved into hardware folder
    [monjolo.brd, monjolo.sch, monjolo_a.brd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]
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2013-11-26 moved to hardware for sehnsor
    [sEHnsor.brd, sEHnsor.sch, sEHnsor_bom.csv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]
2013-12-13 dnp in impulse bom
    [impulse_bom.xlsx]
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2013-12-26 added screws to coilcube bom
    [assembly_bom.xlsx, sEHnsor_bom.xlsx]
2013-12-31 changes to hardware docs
    [coilcube.brd, coilcube.sch]
2014-01-09 new docs for rev b
    [coilcube_bom.csv]
2014-01-09 more doc for rev a
    [coilcube.brd, coilcube.sch, coilcube_bom.csv]
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2014-01-09 gecko ps rev d doc
    [monjolo_d_bom.csv]
2014-01-09 gecko power supply rev c doc
    [monjolo_c_bom.csv]
2014-01-09 gecko power supply b doc
    [monjolo_b_bom.csv]
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2014-01-13 updated doc for cc rev c
    [coilcube_bom.csv]
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2014-02-04 added splitcore part numbers
    [assembly_bom.xlsx]
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2014-03-08 dummy routing for epic2
    [epic2.brd, epic2.sch]
2014-03-09 rectangular board close to routed
    [epic2.brd, epic2.sch]
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2014-03-09 getting closer with epic2
    [epic2.brd, epic2.sch]
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2014-03-10 epic2: cleaned up a couple things
    [epic2.brd, epic2.sch]
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2014-03-20 updates to epic2 brd
    [epic2.brd]
2014-03-24 moved castellated headers in
    [epic2.brd, epic2.sch]
2014-03-24 rerouted after moving castellated headers
    [epic2.brd]
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2014-03-25 added milling layer for panel to bigben
    [bigben.brd]
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2014-03-26 renamed epic2 to myth
    [myth.brd, myth.sch]
2014-04-09 adding files for breeze board
    [breeze.brd, breeze.sch]
2014-04-09 some parts on breeze
    [breeze.brd, breeze.sch]
2014-04-09 simple breeze board routed
    needs another pass when i get parts
    [breeze.brd, breeze.sch]
2014-04-14 connectted the analog pin to the testpoint
    [breeze.brd]
2014-04-18 updated breeze with low pass filter
    [breeze.brd, breeze.sch]
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2014-04-24 correctly drive input from coil
    [monjolo.h]
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2014-04-28 renamed myth to atum
    [atum.brd, atum.sch]
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2014-04-28 current test is looking pretty good
    based on the mechanics. no idea if it does the right thing, but the
    correct lines are getting toggled at the correct times
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2014-04-30 closer, issue with sfd timing
    [monjolo.h]
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2014-05-08 updated silkscreen and names
    - renumbered parts
    - made silkscreen names for assembly
    [atum.brd, atum.sch]
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2014-05-08 new publish files for atum
    [atum_bom.csv]
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2014-05-19 updated bom for bigben
    [bigben_bom.xls]
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2014-05-19 bigben files updated with picture
    [bigben.sch]
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2014-05-21 updated monjolo app to compile
    also fixed #ifndef in header file (finally!)
    [monjolo.h]
2014-05-31 moved atum to atum repository
    [atum.brd, atum.sch, atum_bom.csv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]
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2014-08-01 better error checking when downloading bigben
    [get_log.py]
2014-08-06 added rev b with transistor correct
    [hot_spring.brd, hot_spring.sch]
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2014-09-05 added blast board based on nrf51822
    in the activator series
    [blast.brd, blast.sch]
2014-09-08 not sure what i changed
    [blast.brd]
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2014-09-29 added 32khz crystal to squall
    [squall.brd, squall.sch]
2014-09-29 getting close, real close to shipping squall
    [squall.brd, squall.sch]
2014-09-30 squall rev a ready to ship
    [squall.brd, squall.sch, squall_bom.csv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]
2014-10-03 moved squall to new repo
    [squall.brd, squall.sch, squall_bom.csv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]
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2016-07-03 update to bigger solar panel
    - add footprint for big fram
    - add footprint for rtc
    [blast.brd, blast.sch]
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

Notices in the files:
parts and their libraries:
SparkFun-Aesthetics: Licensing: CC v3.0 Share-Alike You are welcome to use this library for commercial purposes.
